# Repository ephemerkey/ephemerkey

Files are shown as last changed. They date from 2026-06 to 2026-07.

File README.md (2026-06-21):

# ephemerkey

A battery-powered, **GPS-geofenced TOTP code generator**. It produces RFC 6238
time-based one-time passwords (TOTP) — but only when the device holds a valid
GNSS fix inside an authorized geofence. Outside the fence, no codes. A companion
analog "TOTP lock" board consumes the codes and drives an actuator.

> Time comes from GNSS (disciplined RTC), place comes from GNSS — so a code is
> proof of *being in the right place at the right time*.

## Features

- **GNSS time + place**: u-blox MAX-M10S provides UTC time (TIMEPULSE-disciplined
  RTC) and a position fix. Codes are gated on both an accurate clock and a fix
  inside the configured geofence.
- **RFC 6238 TOTP**: SHA1/HMAC/Base32 engine from the `smalltotp` library,
  6-digit / 30-second codes (configurable).
- **Ultra-low-power**: STM32U083 (Cortex-M0+ ULP) + TPS63900 buck-boost with
  nanoamp-class quiescent current for long battery life; GNSS duty-cycled.
- **Tamper / motion**: LIS3DH accelerometer for wake-on-motion and tamper
  detection (optionally zeroizes the secret on tamper).
- **Single coin/Li-ion cell** input via buck-boost (works above and below 3.3 V).

## Architecture

```
                    ┌───────────────── RF ─────────────────┐
   W3011A chip ANT ─┤  (50Ω + π-match)                      │
                    └──────────────┬───────────────────────┘
                                   │ RF_IN
                          ┌────────┴─────────┐
                          │  MAX-M10S-00B    │  u-blox M10 GNSS
                          │  (TCXO, LNA, SAW)│
                          └─┬───┬────┬───┬───┘
                   UART(TXD/RXD)│    │TIMEPULSE (1 PPS → RTC discipline)
                            │   │EXTINT (wake)
                            │   │
   batt ── TPS63900 ──3V3───┼───┴──────────────┐
   (buck-boost,             │                  │
    ultra-low Iq)           │ USART1           │ V_BCKP (RTC/GNSS backup)
                     ┌───────┴────────┐         │
                     │  STM32U083KCU6 │         │
                     │  Cortex-M0+    │── RTC ──┘ (TOTP time base)
                     │  256KB flash   │
                     └─┬────┬────┬────┘
                  I2C  │    │    │ SWD (PA13/PA14)
                  ┌────┴──┐ │    │
                  │LIS3DH │ │    └── USB (PA11/PA12) — provisioning/console
                  │ accel │ │
                  └───────┘ └── code out → companion "TOTP lock" board
                  (motion/tamper)   (UART / open-drain / display)
```

## Repository Structure

```
ephemerkey/
├── hardware/                    # PCB design (KiCad 10, CERN-OHL-P v2)
│   ├── lib/                     # empty — anchor parts use KiCad bundled libs
│   │   ├── symbols/             #   (reserved for future custom symbols)
│   │   ├── footprints.pretty/   #   (reserved for future custom footprints)
│   │   └── 3dmodels/            #   (reserved for future 3D STEP models)
│   ├── ephemerkey/              # The generator board
│   │   ├── ephemerkey.kicad_pro
│   │   ├── ephemerkey.kicad_sch # Top-level: MCU, USB, SWD, button, LED
│   │   ├── psu.kicad_sch        # Battery → TPS63900 buck-boost sub-sheet
│   │   ├── gnss.kicad_sch       # MAX-M10S + W3011A antenna sub-sheet
│   │   └── sensors.kicad_sch    # LIS3DH accelerometer sub-sheet
│   ├── scripts/
│   ├── Makefile
│   ├── sym-lib-table
│   └── fp-lib-table
├── firmware/
│   ├── ephemerkey-stm32/        # STM32U083 application (STM32CubeU0 HAL)
│   ├── common/                  # Shared HAL/utilities
│   ├── shared/                  # Shared protocol definitions
│   └── LICENSE                  # Apache 2.0
├── reference/                   # Datasheets, source-skeleton pointers
├── DESIGN.md                    # Full hardware/firmware design document
└── LICENSE
```

## Key Components

| Component | Part | Package | Purpose |
|---|---|---|---|
| MCU | STM32U083KCU6 | UFQFPN-32 | ULP Cortex-M0+, 256KB flash, RTC, USB, TOTP engine |
| GNSS | MAX-M10S-00B | LGA (9.7×10mm) | u-blox M10: UTC time + position fix |
| GPS antenna | W3011A | SMD chip | 1.559–1.606 GHz GNSS antenna |
| Power | TPS63900DSKR | VSON-10 | Buck-boost, nanoamp Iq, single-cell → 3V3 |
| Accelerometer | LIS3DHTR | LGA-16 | Motion wake + tamper detection |

## Companion Project

The **TOTP lock** (separate analog board) reads the code stream from this
generator and drives an actuator (solenoid/relay). ephemerkey is the *generator*
half; the lock is the *consumer* half. The interface is documented in
`DESIGN.md` (§ Code Output Interface).

## License

- **Hardware**: CERN-OHL-P v2 (permissive open hardware)
- **Firmware**: Apache 2.0 (TOTP engine via smalltotp, also Apache 2.0)

Copyright (c) 2025-2026 EphemerKey Authors

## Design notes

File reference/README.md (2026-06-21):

# Reference Material

Pointers to source material this project was built from.

## Source skeleton
- **Altium part-selection skeleton:** `elec/pr/totp/totp_gps_gen/` — the
  original schematic with the five anchor parts. Pin names/numbers for the
  KiCad symbols were extracted from `totp_gps_gen.SchDoc`.
- **Repo skeleton modeled after:** `github/reefvolt-sensorbuddy/` (KiCad 10
  layout, Makefile, lib-tables, JLCPCB script, DESIGN.md style).

## Firmware
- **smalltotp:** `github/smalltotp/` — RFC 6238 TOTP engine (SHA1, HMAC-SHA1,
  Base32) with STM32 RTC time helpers. Linked/vendored by the firmware.

## Datasheets (to download into this folder via the datasheets skill)
| Part | MPN | Notes |
|---|-----|---|
| MCU | STM32U083KCU6 | AF map for UFQFPN-32, RTC/USB/LPUART, RDP |
| GNSS | MAX-M10S-00B | u-blox M10 integration manual (UART, PPS, V_BCKP, RF) |
| Antenna | W3011A | π-match topology, ground keep-out |
| Power | TPS63900DSKR | CFG/SEL strapping, inductor + cap selection |
| Accel | LIS3DHTR | I2C addressing, INT1/INT2 config |

> Use the `digikey`/`datasheets` skills to populate this folder, then the
> `kicad`/`emc`/`spice` analyzers can consume verified specs.

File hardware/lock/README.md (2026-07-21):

# lock — companion TOTP lock board

The **consumer** half of the ephemerkey system, and the **second PCB in this
repo** (alongside `hardware/ephemerkey/`, sharing the same `scripts/kschgen.py`
engine, `Makefile`, and lib tables — the multi-project layout used by
`reefvolt-sensorbuddy`). ephemerkey *generates* an authenticated unlock; this
board *verifies* it and drives the actuator.

```
make gen-lock      # regenerate the schematic from scripts/lock.schgen.py (placed, not wired)
make check-lock    # component/footprint/dup-ref/ERC tally
make render-lock   # per-sheet PNGs
```

The schematic is **generated from a manifest** (`scripts/lock.schgen.py`), like
ephemerkey. Components are **placed, not wired** — each sheet carries an
on-canvas note that is the wiring spec for the eeschema phase. Regenerate
*before* wiring (regen reassigns UUIDs).

## What it does

1. Sleeps at ~0.1 µA (ATtiny1616 power-down). Coil de-energized, 12 V rail off.
2. ephemerkey starts an I2C transaction; the first START wakes the MCU (wake-on-I2C).
3. **Authenticated** challenge-response over I2C proves the request is
   genuine (HMAC-SHA1, shared secret in flash — see *Firmware plan*).
4. On success: enable the boost, run the **peak-and-hold** solenoid profile,
   then drop the rail and go back to sleep.

Everything (MCU + boost + driver) is **powered from ephemerkey over the I2C
connector** (J2.2 = VSYS, ephemerkey's ~3.0–4.7 V battery/system rail). The lock
carries **no local battery** (J1 removed). See the *current caveat* under the
interface section — a 12 V solenoid pull-in draws several amps through that cable.

## Architecture

```
 VSYS from ephemerkey ──┬─────────────────────────────► U1 ATtiny1616 VCC   (direct, NO LDO; ~0.1µA sleep)
   (J2.2, I2C connector) │                            │  PA5 SOL_PWM ─┐   PB0/PB1 I2C ── J2 (target; key=master)
                           │                            │  PA6 SOL_BOOST_EN  wake-on-I2C: SCL START (no wake line)
                           │   SOL_BOOST_EN ──► EN       │  PA0 UPDI ─────── J4 (program)
                           └─► U2 MT3608 boost ──► +12V (VSOL) ─┬─ C5 220µF + C6 22µF  (reservoir)
                               L1 10µH · D2 SS34               │
                               FB: R3 200k / R4 10k ≈ 12.6V    ▼
                                                          ┌─ SOLENOID ─┐  (J3 JST-PH)
                                                  D3 SS34 │            │
                                                  flyback └─────┬──────┘
                                                                │ SOL_DRV (drain)
                                                  SOL_PWM ─[R5 100R]─┤ Q1 AO3400A (low-side)
                                                              [R6 100k]│
                                                                    GND┘
```

Sheets: **MCU** (`mcu.kicad_sch`) · **PWR** (`psu.kicad_sch`) · **DRV** (`drv.kicad_sch`).

## BOM (all JLCPCB / LCSC)

| Ref | Part | Value | LCSC | JLC | Footprint |
|-----|---|---|---|-----|---|
| U1 | ATtiny1616 | tinyAVR-1, runs 1.8–5.5 V | C507118 | ext | QFN-20 3×3 0.4 mm |
| U2 | MT3608 | boost, ~2 A switch | C84817 | ext | SOT-23-6 |
| Q1,Q2,Q4,Q5 | AO3400A | N-FET (solenoid LS, FB switch, servo logic, interlock) | C20917 | **Basic** | SOT-23 |
| Q3 | AO3401A | P-FET (servo high-side load switch) | C15127 | **Basic** | SOT-23 |
| D2,D3 | SS34 | Schottky 40 V/3 A | C8678 | **Basic** | SMA |
| L1 | FNR6045S100MT | 10 µH power inductor | C168076 | ext | 6×6 mm |
| C5,C8 | 220 µF 25 V | reservoir / VSERVO bulk (electrolytic) | C4747974 | ext | Ø6.3×7.7 |
| C4,C6 | 22 µF 25 V | boost out / VSOL bypass | C12891 | **Basic** | 1206 |
| C3 | 10 µF 25 V | boost in | C15850 | **Basic** | 0805 |
| C1,C2,C7,C9,C10 | 100 nF / 1 µF / 1 nF | decouple / hall debounce / snubber(DNP) | C1525/C29266 | **Basic** | 0402 |
| R3 | 200 k | FB top | C25764 | **Basic** | 0402 |
| R4 | 22 k | FB base → 6 V default | C25768 | **Basic** | 0402 |
| R17 | 20 k | FB switch → 12 V (Q2) | C25765 | **Basic** | 0402 |
| R2,R6,R18,R19,R20 | 100 k | pulldowns / P-FET gate pull-up | C25741 | **Basic** | 0402 |
| R16,R21,R22,R23,R25 | 10 k | servo pulldowns/series, hall pull-ups | C25744 | **Basic** | 0402 |
| R5 | 100 Ω | gate series | C106232 | ext* | 0402 |
| R1,R15,R24 | 1 k | status LED / servo signal series | C11702 | **Basic** | 0402 |
| D1 | LED green | status (driven by **PC3**) | C160479 | ext | 0402 |
| J3 | JST-PH 2-pin | solenoid | C173752 | ext | PH 2.0 |
| J2 | JST-PH 4-pin RA (S4B-PH-K) | I2C link (right-angle) | C157926 | ext | PH 2.0 RA |
| J4 | pin header 1×3 | UPDI program | — | — | 1×3 |
| J5,J8 | pin header 1×3 | servo outputs (S/V+/GND), DNP unless servo build | — | — | 1×3 |
| R13,R14 | 0 Ω | VSERVO source select (fit one) | C17168 | **Basic** | 0402 |
| J6,J7 | JST-PH 3-pin RA (S3B-PH-K) | door / bolt hall sensors | C157929 | ext | PH 2.0 RA |

\* jlcsearch under-reports Basic flags; verify in JLCPCB's BOM tool at order time.

Every footprint is a KiCad-bundled package, so **all parts carry 3D models** — the
board is clearance-checkable in KiCad's 3D viewer once it's laid out.

## Boost + reservoir sizing (read before ordering)

12 V × up to 1 A ≈ **12 W ≈ ~3.8 A from the cell** — heavy. The design splits it:

- The **MT3608** is sized for the **hold** current (~0.3 A @ 12 V ≈ within its
  ~0.5 A @ 12 V capability) plus recharging the reservoir between actuations.
- The **reservoir** (C5) supplies the brief **pull-in** surge. Sizing:
  `ΔV ≈ I_pull · t_pull / C`. A 1 A, 30 ms pull-in pulls 30 mC; with 220 µF that
  sags the rail a lot, so **220 µF is the baseline for ≤ ~500 mA / short
  pull-ins**. For a true sustained **1 A @ 12 V pull-in**, either grow C5 into
  the multi-thousand-µF range **or** swap the MT3608 for a **TPS61088-class**
  boost that can source the full 12 W directly. Pin this down against the actual
  solenoid's pull-in current × time and re-fire rate.

Set Vout exactly with the FB divider: `Vout = 0.6·(1 + R3/R4)`. 200 k/10 k ≈
12.6 V; trim R3 toward 12.0 V if desired.

## Servo variant + firmware actuator control

The board drives a **12 V solenoid** or a **6 V RC servo**. Because the boost
voltage and the servo power are both firmware-controlled, **one fully-populated board
can carry both** and switch between them (one actuator active at a time — a single
boost = a single voltage). Firmware drives three lines:

- **`BOOST_VSEL`** (PA1) — picks the rail: low/default **6 V** (servo-safe), high
  **12 V** (solenoid). NMOS Q2 switches R17 across the FB divider.
- **`SERVO_PWR_EN`** (PA2) — high-side P-FET (Q3) load switch on VSERVO. Servo power
  comes on only when firmware asserts it **and** the boost is at 6 V: a **hardware
  interlock** (Q5, gated by `BOOST_VSEL`) forces servo power OFF at 12 V regardless of
  firmware, so a 12 V solenoid pulse can never reach a 6 V servo.
- **`SERVO_SIG`** (PB2 / TCA0) — 50 Hz position pulse, via R15 (1 k) + R16 (10 k idle
  pulldown) so the servo can't twitch at boot.

| Mode | BOOST_VSEL | SERVO_PWR_EN | Actuator |
|---|---|---|---|
| Solenoid | 12 V | off (interlock-forced) | Q1/D3/J3 peak-and-hold |
| Servo, 6 V | 6 V | on | J5 servo, VSERVO ← VSOL (`R13`, populated) |
| Servo, direct | boost off | on | J5 servo, VSERVO ← VSYS (`R14`, DNP alt) |

- **J5 / J8** — two 3-pin RC-servo outputs (`1=SIG, 2=V+ (VSERVO), 3=GND`), e.g. a
  dual-latch lock. `SERVO_SIG` (PB2/TCA0) and `SERVO_SIG2` (PB4, software-timed);
  both share the `VSERVO` rail and the load-switch/interlock. MT3608 ~1 A @ 6 V —
  drive them sequentially, or upsize C5/C8 for simultaneous travel.
- **VSERVO source** — fit **exactly one** 0 Ω: `R13 = VSOL` (6 V from the boost —
  the populated default) or `R14 = VSYS` (servo direct off the connector rail,
  ~3–4.7 V). **Never both.** C8 (220 µF) buffers servo inrush.
- `SERVO_SIG` is VSYS-level logic (~3–4.7 V), accepted by typical servos, GND-referenced.

## Authenticated digital interface + Firmware plan

The ephemerkey↔lock link is an authenticated I2C bus — **ephemerkey is the
master**, this lock is the target — on a **right-angle 4-pin JST-PH** (`S4B-PH-K`,
a standard 4-pin I2C cable, straight-through):

| Pin | lock (this board, target) | ephemerkey (key, master) |
|-----|---|---|
| 1 | GND (+ actuation return) | GND |
| 2 | **VCC ← powers the lock** (VSYS in) | **VSYS** (battery/system rail out) |
| 3 | `SDA` ↔ PB1 | `LOCK_SDA` (PA6, I2C3) |
| 4 | `SCL` → PB0 (clock + wake) | `LOCK_SCL` (PA7, I2C3) |

The lock has **no local battery** — its VCC (and the boost/actuator draw) comes in
on J2.2 from ephemerkey's VSYS rail. **Current caveat:** a 12 V solenoid pull-in is
~3–4 A from VSYS, beyond a JST-PH contact (~2 A) and ephemerkey's load-share path —
favor the 6 V servo / low-duty buffered by C5/C8, or run a heavier dedicated feed.
The I2C pull-ups live on ephemerkey at +3V3 (do not pull the bus to VSYS — the STM32
pins are 3.3 V-domain). The lock (running at VSYS) reads the 3.3 V idle
level fine across the discharge curve. The lock is the **target** at addr 0x60 with
**no separate wake line** — it wakes from power-down on the first I2C START (a
pin-change interrupt on SCL), so we don't mix a discrete "button"-style input with
the bus.

Authentication is **firmware HMAC** — no secure element. A pairing secret lives
in flash on **both** boards (separate from ephemerkey's TOTP secret).

**I2C register/command map** (lock = target @ 0x60). The master reads status/nonce
and writes *authenticated* commands:

| Reg | Access | Contents |
|-----|---|---|
| `0x00 STATUS` | read | bit0 `DOOR_CLOSED` · bit1 `BOLT_LOCKED` · bit2 `ACTUATOR` (0=solenoid,1=servo) · bit3 `RAIL_12V` · bit4 `BUSY` · bit5 `LAST_CMD_OK` |
| `0x01 NONCE` | read | a fresh 16-byte random nonce; reading **arms** it (consumed by the next COMMAND) |
| `0x10 COMMAND` | write | `[cmd] ‖ HMAC-SHA1(secret, nonce ‖ cmd ‖ code)` — cmd `0x01`=UNLOCK, `0x02`=LOCK |

**Probe lid/door state (unauthenticated read — status only):** the I2C START wakes
the lock; the master reads `STATUS`. `DOOR_CLOSED` / `BOLT_LOCKED` report the J6/J7
hall sensors; `ACTUATOR` tells the key whether a servo is fitted.

**Lock / unlock (authenticated challenge-response, anti-replay):**

1. Master reads `NONCE` (0x01).
2. Master writes `COMMAND` = `cmd ‖ HMAC-SHA1(secret, nonce ‖ cmd ‖ code)`.
3. Lock recomputes, **constant-time** compares against the armed nonce (then clears
   it → replay-proof), and only then drives the actuator:
   - **UNLOCK** (0x01): solenoid → peak-and-hold release; servo → unlock angle.
   - **LOCK** (0x02): **servo → lock angle** (a servo holds position). For a
     momentary solenoid, LOCK is a no-op — it re-latches mechanically (fail-secure).
4. Master may re-read `STATUS` to confirm `BOLT_LOCKED` flipped.

`code` may be the ephemerkey TOTP digits, binding the action to a fresh in-fence
code. Optionally fold a monotonic counter (EEPROM) into the HMAC so a weak RNG
can't be exploited.

**Lock firmware (ATtiny1616 — megaTinyCore or bare AVR):**

- State machine: `SLEEP(power-down)` → (I2C START wakes it) → service TWI as target
  → `SLEEP`; a verified `COMMAND` branches to `ACTUATE`. In `SLEEP`: TWI/boost off,
  `R6` holds Q1 off, `R2` holds boost off; SCL (PB0) pin-change wakes it (wake-on-I2C).
- **STATUS read** → pulse `HALL_PWR` (PA4) high, settle ~1 ms, sample `HALL_DOOR`
  (PA7) + `HALL_BOLT` (PB3), drop HALL_PWR, return the bits (~0 µA between reads).
- **ACTUATE**:
  - *Solenoid* — the **peak-and-hold economizer**: `SOL_BOOST_EN=1` → wait VSOL →
    `SOL_PWM` 100 % pull-in (~20–50 ms) → reduce duty for hold → release. PWM = TCB0 (PA5).
  - *Servo* — `BOOST_VSEL`=6 V, `SERVO_PWR_EN`=on, drive `SERVO_SIG` (PB2/TCA0) to
    the lock/unlock angle, wait for travel, then cut servo power. The hardware
    interlock keeps servo power off whenever `BOOST_VSEL`=12 V.
- HMAC-SHA1 (reuse `smalltotp`, portable C → compiles for AVR) fits in 16 KB/2 KB.
  Secret in USERROW/flash; **disable UPDI / set lockbits** in production.

**Key firmware (ephemerkey STM32U083 — add to its superloop):**

- **Probe the lid:** wake the lock (I2C START) and read `STATUS` — surface door
  open/closed + bolt locked/unlocked (e.g. on the OLED); no auth needed.
- **Lock / unlock:** on a request (button + in-fence + fresh, valid TOTP), read
  `NONCE`, compute `HMAC-SHA1(secret, nonce ‖ cmd ‖ code)`, write `COMMAND` with cmd
  = UNLOCK or LOCK. (Send a dummy/wake byte first and retry — the just-woken target
  NACKs the first.) Re-read `STATUS` to confirm.
- Use the **same** HMAC-SHA1 as the lock — `smalltotp` ships it, so both reuse it.
- The pairing secret is provisioned over USB during pairing.

## Programming

`J4` UPDI header: `1 = UPDI (PA0)`, `2 = VCC (BAT)`, `3 = GND`. One-wire UPDI via
`pymcuprog`, a serial-UPDI adapter, megaTinyCore, or Atmel-ICE/PICkit.

## Bring-up checklist

1. Power from a current-limited 1S cell; confirm the MCU enumerates over UPDI and
   sleeps at ~µA with the I2C bus idle.
2. Pulse `SOL_BOOST_EN`; scope VSOL → should reach ~12.6 V; trim R3 if needed.
3. With a solenoid fitted, tune the pull-in time and hold duty; add the R9/C7
   snubber (DNP) only if drain ringing is high.
4. Bring up the I2C challenge-response against ephemerkey (confirm wake-on-I2C +
   the dummy-then-retry handshake); verify a wrong/late response never actuates.

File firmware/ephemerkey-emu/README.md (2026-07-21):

# ekemu — generator + lock emulator

Runs the **exact `ephemerkey-core` engines the firmware ships** — policy
state machines, TOTP validation with walk-time delay windows, the reveal
scheduler with scatter/show-once/decoy display modes — under a virtual
clock, with the display and key-entry surfaces mimicked in text. A
30-minute walk takes one `time +30m`.

```sh
make demo          # self-checking walk-vault ritual (CI-able)
make run           # interactive REPL
make test          # core unit tests (RFC 4226/6238 vectors, etc.)
```

## Commands

```
time +<n>[s|m|h]      advance the virtual clock (ticks slot expiry)
time set <unix>       jump the clock
env fence <i> <in|out>  move the lock in/out of geofence i (portable locks)
env still <secs>      set how long the lock has been motionless
env cal <i> <open|shut> open/close calendar window i
env show              print the current virtual GNSS/accel/RTC environment
gen reveal [key]      request a reveal — prints the display frames the user
                      (and any shoulder-surfer) would see; scatter mode shows
                      one digit per frame, correct position, random order
gen next [key]        countdown to the next REAL reveal (show-once modes)
lock enter <code|@N>  type a code; @N = Nth revealed code (the "notebook"
                      the user wrote codes into before walking)
lock status           slot states (respects show_progress hiding)
validate <@R>         relay the Rth emitted receipt to the remote validator
expect <substring>    assert on the last event line; any miss => exit 1
echo / # / quit
```

## Confirm-TOTP (the lock talks back)

If a scenario has a `confirm` block (`{ "secret", "digits", "mode":
sequence|time|both }`), the lock mints its own **receipt** on every fire and
relock — a `RECEIPT @R` line carrying a **sequence** code (HOTP over a
monotonic event counter: order/replay proof), a **time** code (TOTP over the
event time: "it happened at HH:MM"), or both. `validate @R` relays a receipt
to a remote validator holding the same secret, which reports `VALID
(skipped/drift)`, `REPLAY`, `OUTOFWINDOW`, `DESYNC`, or `BADCODE`. Time proves
*when*; sequence proves *which event, in order* — a lock can require either or
both.

Each slot may carry **gates** (`{ "fence": i, "stillness_s": n, "calendar":
i }`) that must all hold — evaluated against the `env` above — before a code
counts. A correct code entered while a gate is shut reports `GATED slot=…
<reason>` and is **not burned**, so the same code works once the lock is in
position / still / in-window. Gates are checked in a fixed order (fence →
stillness → calendar) so the reported reason is deterministic.

The `DECOY` tag on reveal events is ground truth from the core's
`introspect` feature (emulator-only — firmware builds cannot see it; the
display pipeline is identical for real and poison codes by construction).

## Scenario files

JSON (`scenarios/*.json`): a key table (secret, digits 4-10, optional decoy
twin, display spec) and a slot table (policy + parameters). Policies:
`always`, `sequence` (N codes, generation cadence, walk delay), `path`
(ordered zone-keyed legs), `deadman` (beat or RELOCK), `quorum` (M-of-N
distinct keys, optional alternating).

| Scenario | Script demonstrates |
|---|---|
| `walk-vault` | the canonical ritual: 3 codes on 90-240 s minting cadence, valid 30-35 min later; scatter display; poison-mode decoy → lockout |
| `courier` | walk-the-path: zone A→B→C legs, order + pace proven by counters, entered from the notebook at the destination |
| `deadman` | unlock, keep-alive beats, missed-beat RELOCK, and the forced-reset-still-relocks invariant |
| `quorum` | two-person rule: alternating violation, completion, window expiry |
| `portable-vault` | position + stillness + calendar gates peel off one at a time; the never-burned code fires only when all three hold, then re-gates on leaving the fence |
| `receipts` | confirm-TOTP in `both` mode: fires and relocks mint sequence+time receipts; a validator catches replay, resync-skip, and time-window expiry |

## What the demo script proves

`scripts/walk-vault.txt` walks the full story: cadence minting → squeezed
4th reveal is a decoy → early entry rejected → 31-min walk → 3 codes
accepted on generation cadence → replays ignored without reset → unlock
fires → post-fire replay burned → the decoy arrives later and trips a
lockout. Every step is `expect`-checked.

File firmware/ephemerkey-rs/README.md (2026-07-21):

# ephemerkey-rs — STM32U083 firmware (Rust / Embassy)

Async-Rust replacement for the C `ephemerkey-stm32/` skeleton, built on
[Embassy](https://embassy.dev). Chip: **STM32U083KCU6** (Cortex-M0+,
UFQFPN-32, `thumbv6m-none-eabi`), officially supported by `embassy-stm32`
(feature `stm32u083kc`). No STM32Cube dependency.

## Personalities

One image, two roles, selected by provisioned config (`src/config.rs`):

| Role | Pipeline |
|---|---|
| **Generator** | GNSS (USART1) → geofence → RTC-disciplined TOTP emission |
| **LockController** | code slots / policy engine (`src/policy.rs`) → authenticated I2C link to the lock board |

Both are programmed with signed config **files** over USB (button-gated
provisioning mode) or the WiFi/ESP32-C3 link — see `src/provision.rs` and
`../../DESIGN-policies.md` for the slot/policy model.

## Layout

| File | Subsystem |
|---|---|
| `src/main.rs` | boot, role dispatch, LEDs (PB0/PB1), buttons (PA5/PA15), PPS placeholder (PA0) |
| `src/gnss.rs` | MAX-M10S on USART1 (PA9/PA10, DMA RX) + RESET_N (PA4, OD) + EXTINT (PA1) |
| `src/lock.rs` | hardware I2C3 master to the lock board (PA6 SDA / PA7 SCL) — see below |
| `src/sensors.rs` | I2C1 (PB6/PB7): LIS3DH @0x18, OLED @0x3C, M24M02E log EEPROM @0x50-53, MAX17048 fuel gauge @0x36; INT1/INT2 EXTI |
| `src/wifi.rs` | ESP32-C3 on LPUART1 (PA2/PA3) + PB5 power gate (off by default) |
| `src/buzzer.rs` | TIM3_CH1 PWM on PB4 (boot chirp) |
| `src/config.rs` | role + persistent config (flash journal TODO) |
| `src/provision.rs` | signed config file ingestion (USB/WiFi transports TODO) |
| `../ephemerkey-core` | **shared no_std core**: TOTP (4-10 digits, delay windows), code-slot policy engine, reveal scheduler (scatter/show-once/decoy) — unit-tested on host, exercised by `../ephemerkey-emu` |

Every pin binding is type-checked against the U083 AF table at compile time —
the crate builds only if the DESIGN.md pin budget is electrically coherent.

### Hardware finding → rev 0.2 pin swap

The original pin budget put the lock link on PB0/PB1, which carry **no I2C
alternate function** on the U083 (only LCD/LPTIM3/SPI1-CS/UART-flow) — caught
by this crate's compile-time AF check. Resolution: the lock link and the LEDs
swapped pins. The link now rides **hardware I2C3 on PA6 (SDA) / PA7 (SCL),
AF4**; the LEDs (function-agnostic) took PB0/PB1. Schematic + DESIGN.md are
updated to match.

The bus-transient requirement survives the swap: the lock glitches SDA/SCL
for ~0.4 s during actuation (see `../lock-attiny/README.md`), so the master
re-inits the peripheral + bus-clears + retries on any error.

### Timer allocation

| Timer | Use |
|---|-----|
| TIM15 | embassy time driver (do not touch) |
| TIM2 | reserved: GNSS PPS input capture (PA0, CH1) |
| TIM3 | buzzer PWM (CH1, PB4) |
| LPTIM1 | future: time driver in Stop mode (LSE), with the `low-power` work |

## Build / flash

```sh
make build          # debug
make release
make run            # probe-rs flash + defmt console (SWD on PA13/PA14)
make flash          # release flash
```

Requires `rustup` (pulls the pinned toolchain + target via
`rust-toolchain.toml`) and `probe-rs` (`--chip STM32U083KC`).

## Roadmap

- [ ] Clock tree: LSE→RTC, HSI48+CRS→USB; then Stop-mode + `low-power` executor
- [x] TOTP core: RustCrypto `hmac`/`sha1` in `ephemerkey-core` (RFC-vector tested)
- [ ] NMEA parse + geofence (port `geofence.c` point-in-polygon)
- [ ] TIM2_CH1 PPS capture → RTC discipline + staleness window
- [ ] Flash journal (`sequential-storage`): config/secret map (2×2KB
      ping-pong, rare writes) + confirm-TOTP counter queue (2×2KB append,
      ECC-safe single-write-per-word) + RDP/HDP — see `src/config.rs`
- [ ] USB FS provisioning console (`embassy-usb`, button-gated)
- [ ] Lock link: nonce/HMAC command flow over I2C3 (+ soak
      against the real lock through actuation transients)
- [x] Path / DeadMan / Quorum state machines (ephemerkey-core, emulator-proven)
- [x] Policy-engine gate model: `Sensors` trait + fence/stillness/calendar
      gates in `ephemerkey-core` (emulator-proven); firmware still needs the
      real `Sensors` impl over GNSS-fix / LIS3DH-activity / RTC
- [x] Confirm-TOTP receipts in `ephemerkey-core`: HOTP (event-sequence) and
      TOTP (event-time) proofs, independently selectable or both, minted on
      every fire/relock, with a remote `Validator` (emulator-proven). Firmware
      still needs to persist the monotonic event counter (flash journal) and
      wire the relay to OLED/USB/WiFi.
- [ ] ESP32-C3 protocol: OTA staging, config file transport

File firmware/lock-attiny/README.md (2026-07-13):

# ephemerkey lock board — ATtiny1616 firmware

Firmware for the companion "TOTP lock" board. The ATtiny1616 runs directly
off the cell (1.8–5.5 V, no LDO), authenticates codes over I²C via HMAC-SHA1
(shared with `smalltotp`), and drives the actuator with a peak-and-hold
economizer.

This tree implements the **authenticated I²C lock**: an HMAC-SHA1 challenge-
response that gates unlock/lock actuation, plus unauthenticated hall-sensor
status — running from power-down sleep, woken by the I²C bus.

## Hardware map (from `hardware/lock/`)

| Signal | Pin  | Notes |
|---|---|---|
| Status LED | PC3  | active-high: `PC3 → D1 → R1(1k) → GND` |
| UPDI / RESET  | PA0  | `SYSCFG0=0xF6` — RESET pin is UPDI |
| I²C SCL | PB0  | TWI0 (target @ 0x60); START wakes from power-down |
| I²C SDA | PB1  | TWI0 |
| HALL_PWR | PA4  | powers both hall sensors during a read only  |
| HALL_DOOR | PA7  | door sensor in (J6.3) |
| HALL_BOLT | PB3  | bolt sensor in (J7.3) |
| Servo1 signal | PB2  | `TCA0/WO2 → R15(1k) → J5.1`, 50 Hz / 0.6–2.4 ms |
| Servo2 signal | PB4  | software pulse (TCA0 OVF+CMP1) → R24 → J8.1 |
| Servo power | PA2  | `SERVO_PWR_EN → Q3` high-side (VSERVO) |
| Solenoid drive| PA5  | `SOL_PWM → R5 → Q1` low-side; hold PWM = TCD0/WOB ~31 kHz |
| Boost enable  | PA6  | `SOL_BOOST_EN → MT3608 EN` (12 V for solenoid) |
| Boost 6/12 V  | PA1  | `BOOST_VSEL` select + servo interlock (Q5) |

Fuses read factory-default; device is unlocked. See the bringup notes in the
repo for the full fuse dump.

### Servo power — servo runs on VSOL (default strap R13)

The servo supply (`VSERVO_SRC`) is strap-selected on the DRV sheet:
**`R13`(0Ω, fitted) → VSOL** (the boost rail, the default) or **`R14`(DNP) →
BAT+** (direct battery, alt). So the servo is on VSOL: at ~Vbat when the boost
is off (VSOL's passive L1+D2 path), or **6 V when boosted** (`servo_boost`
config flag → `SOL_BOOST_EN` on, `BOOST_VSEL` low = Q5 interlock clear).
`BOOST_VSEL` high (12 V) always interlocks servo power off.

(NB: an on-canvas note in `drv.kicad_sch` labels R13/R14 the other way round —
it's stale; R13→VSOL per the `lock.schgen.py` manifest and the built board.)

## Toolchain

- **Compiler:** `avr-gcc` / `avr-libc` (Fedora: `sudo dnf install avr-gcc
  avr-libc avr-binutils`). Needs avr-libc ≥ 2.0 for tinyAVR-1 headers.
- **Programmer:** [`pymcuprog`](https://pypi.org/project/pymcuprog/) SerialUPDI
  over an Adafruit UPDI Friend. Invoked via `uvx` — no system install needed.
- Adapter enumerates as a CH340 at `/dev/ttyUSB0` (override with `PORT=`).

The HMAC-SHA1 core is the **`smalltotp`** sibling repo (`src/sha1.c`,
`src/hmac_sha1.c`), linked — not vendored — exactly as the STM32 side does.
Point `SMALLTOTP` at your checkout:

## Build & flash

```sh
make SMALLTOTP=~/path/to/smalltotp        # compile + link + size
make flash SMALLTOTP=~/path/to/smalltotp  # erase, write, verify
make ping                                 # UPDI sig check (1E9421)
make fuses                                # dump fuses
make clean
```

Default is `SMALLTOTP ?= ../../../smalltotp` (a sibling of the repo). Select the
actuator with `-DLOCK_ACTUATOR=ACTUATOR_SERVO` (default) or `ACTUATOR_SOLENOID`.

## I²C protocol (target @ 0x60 — see `hardware/lock/README.md`)

| Reg | Access | Contents |
|-----|---|---|
| `0x00 STATUS`  | read  | bit0 DOOR_CLOSED · bit1 BOLT_LOCKED · bit2 SERVO_ON (live) · bit3 RAIL_12V · bit4 BUSY · bit5 LAST_CMD_OK · bit6 SOL_ON (live: coil energized, incl. drain) |
| `0x01 NONCE` | read  | fresh 16-byte nonce; **reading arms it** (single-use) |
| `0x10 COMMAND` | write | `cmd(1) ‖ HMAC-SHA1(pairing_secret, nonce ‖ cmd)(20)`; `0x01`=UNLOCK, `0x02`=LOCK, `0x03`=ABORT (emergency stop: everything off) |
| `0x20 CONFIG`  | write | `blob(65) ‖ HMAC-SHA1(config_secret, nonce ‖ blob)(20)` · read = current blob |

Flow: read `NONCE` → write `COMMAND`/`CONFIG` → lock recomputes the HMAC,
**constant-time** compares, **burns the nonce** (replay-proof), then actuates or
saves config. Master re-reads `STATUS`. HMAC covers `nonce ‖ payload` only (no
TOTP code — the lock has no clock). UNLOCK/LOCK are **idempotent** (re-lock /
re-unlock is fine).

- **Two secrets, split across USERROW** (`SECRET_LEN`=16 each): pairing
  `[0:16]` (UNLOCK/LOCK) and config `[16:32]` (admin CONFIG writes). DEV
  fallbacks when USERROW is blank; provision over UPDI + set lockbits.
- **Anti-replay:** the armed nonce is single-use *and* derived from a monotonic
  EEPROM counter (survives resets/power loss; no TRNG):
  `nonce = HMAC-SHA1(pairing_secret, counter)[0:16]`. The counter provides
  freshness; keying with the pairing secret makes nonces opaque (an unkeyed
  hash would let one captured nonce brute-force the 2³² counter offline and
  predict all future nonces — no forgery, but a usage-count leak).
  Regenerating takes ~tens of ms (software HMAC at 3.3 MHz), so back-to-back
  NONCE reads can briefly serve the same value. Harmless: one armed slot,
  burned on first use, and regeneration is ordered before command servicing —
  a MAC verifies at most once (replay of the exact bytes is rejected; verified
  live).

### Programmable config (bit-packed, 65 bytes, persisted in EEPROM)

Actuation is a **programmable step sequence**: an ordered list of up to 6 steps
run on UNLOCK, and an independent list run on LOCK. Header + two sequences:

| Byte | Field | Encoding |
|---|---|---|
| 0 | magic (0xE4) | validity guard |
| 1 | flags | b0 servo_boost (servo-only steps at 6 V) |
| 2 | solenoid strike time | ×10 ms (full pull-in, 12 V economizer) |
| 3 | solenoid hold duty | 0–255 → 0–100 % (TCD0 economizer) |
| 4 | sensor_map | b0-1 DOOR_CLOSED src · b2-3 BOLT_LOCKED src (0=J6, 1=J7, 2=off) |
| 5–34  | `seq_unlock[6]` | 6 × step (5 bytes) |
| 35–64 | `seq_lock[6]` | 6 × step (5 bytes) |

Each **step** is 5 bytes — `act`, `s1_pos`, `s2_pos`, `dur_ds`, `eoff`:

| Field | Encoding |
|---|---|
| `act` | b0 servo1 · b1 servo2 · b2 solenoid · **0 = end of sequence** |
| `s1_pos` / `s2_pos` | 8-bit target → 500–2500 µs (per step, either direction) |
| `dur_ds` | run time ×100 ms (servo drive / solenoid hold), 0–25.5 s |
| `eoff` | b0-1 sensor (0 none · 1 DOOR · 2 BOLT) · b2 edge (0 present / 1 absent) |

A step fires any combination of its actuators **together**, for `dur_ds`, then
the sequence advances. If `eoff` names a (logical) hall sensor, the step can
end early — heavily deglitched, because actuation disturbs the sensors (on the
bench the hall reads a *sustained* false-absent whenever actuators are loaded):

1. **Arm** — the step must first see the *opposite* state for 5 consecutive
   10 ms samples (e.g. `eoff=door-` requires the door seen **closed** for
   50 ms within the step). A sensor that's disturbed from the start, broken,
   or disconnected never arms — the step simply runs its full time.
2. **Fire** — an integrating counter over 10 ms samples: wanted state +1,
   opposite −5 (floor 0); fires at 50 (~500 ms clean dwell). A few transients
   only delay it; sustained opposite readings drain it.

Both layers fail toward "keep driving". Then the sequence advances. Per-step
**rail selection** (the boost makes VSOL, which also feeds the servo):

| Step drives | Rail | Solenoid |
|---|---|---|
| solenoid **+** servo | **6 V** (`BOOST_VSEL` low, interlock clear) | **full DC**, no PWM |
| solenoid only | **12 V** (`BOOST_VSEL` high) | strike → economizer PWM hold; servo interlocked out |
| servo + `servo_boost` | **6 V** | — |
| servo only | Vbat (boost off) | — |

> **Combined servo+solenoid** is the only way to move a servo while the solenoid
> fires: forced to **6 V** with the solenoid at **full DC** (no economizer PWM),
> so the shared rail can power both. Normally the two are electrically exclusive
> (12 V solenoid interlocks servo power off).

> **`servo_boost` (flag b0) — 6 V boosted servo.** Servo-only steps run off the
> boost rail at **6 V** (`SOL_BOOST_EN` on, `BOOST_VSEL` **low** = Q5 interlock
> clear), with a boost ramp before and a VSOL drain after. Requires the servo
> strapped to VSOL (R13, the default strap) and a 6 V servo. **Off by default; do
> not set it unless the board is wired for a boosted servo.**

### Non-blocking actuation

Actuation runs as a **TCB0-tick-driven step engine** (`actuate.c`), never
blocking the main loop: it walks the configured UNLOCK/LOCK step list, ramping
each step's rail, driving its actuators for the step time (or until early-off),
then draining — all while I²C stays fully responsive, and a new lock/unlock
**aborts** the in-flight cycle. Per-step rail selection + VSOL drain are
preserved. The LED mirrors BUSY.

> **Verification status:** protocol verified **live on hardware** via the
> RedBoard I²C bridge (`testharness/`) — unlock/lock accept with a valid HMAC,
> reject a bad one, nonces are fresh per command, hall status reads; soaked 40
> lock/unlock pairs with aggressive mid-cycle polling. Sleep is
> **IDLE** for bringup (`LOCK_SLEEP_MODE`): a TWI target in continuous
> POWER-DOWN both NACK-wedges the bus and makes UPDI unreachable, so power-down
> is deferred until the wake path is hardened. Every reset opens an ~8 s awake
> window (LED flutter) for reliable reprogramming. STM32 master I²C+HMAC is
> still unimplemented (it talks one-way over UART today — a known spec gap).

> **⚠️ I²C during actuation:** the boost soft-starting into stalled servos
> glitches SDA/SCL for ~0.4 s at actuation start (bus-error bursts on every
> cycle on the bench; dev-board wiring exaggerates it, but assume nonzero on
> any build). The lock target rides it out fine — but **the master must
> implement bus-error recovery** (peripheral re-init / 9-clock bus-clear +
> retry) or it can latch and go permanently deaf, as the RedBoard's ATmega TWI
> did. Full write-up + soak/regression tool: `testharness/README.md`.

## Roadmap

- [x] Blink + sleep (LED + flash + wake path)
- [x] Dual servo actuation on battery voltage (TCA0 PWM, both connectors)
- [x] Gated 12 V solenoid, peak-and-hold, boost↔servo mutual exclusion + drain
- [x] I²C target + HMAC-SHA1 challenge-response (unlock/lock) + hall status
- [x] Power-down sleep, wake on I²C
- [ ] Live protocol test against the STM32 master (needs STM32 I²C+HMAC side)
- [ ] STM32 master I²C driver: bus-error recovery (re-init / 9-clock bus-clear
      + retry) — actuation glitches the bus every cycle; see testharness/README
- [ ] Confirm hall-sensor output polarity against the real part
- [ ] Provision USERROW secret + set UPDI lockbits
- [ ] Fuse config: enable BOD level for actuator brown-out margin

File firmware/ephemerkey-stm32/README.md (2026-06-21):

# ephemerkey-stm32

STM32U083 application firmware for the ephemerkey GPS-geofenced TOTP generator.
Built on the **STM32CubeU0 HAL** and the **smalltotp** RFC 6238 engine.

## What it does

Wake → power the GNSS → acquire a fix → parse NMEA → discipline the RTC from
GNSS UTC → gate on **fix quality** (sats, HDOP), **clock freshness**
(anti-replay), and **geofence** (haversine) → generate a TOTP code → emit it to
the companion lock (UART line + `CODE_VALID` strobe) → sleep until motion
(LIS3DH) or a duty timer. See `../../DESIGN.md` for the full design.

## Layout

```
ephemerkey-stm32/
├── Makefile                  # arm-none-eabi build (CUBE_U0 + smalltotp)
├── STM32U083KCUx_FLASH.ld    # linker script (256K flash / 40K RAM)
├── include/
│   ├── board.h               # pin map (mirrors DESIGN.md pin budget)
│   ├── ephemerkey_config.h   # secret, geofence, gating thresholds
│   ├── gnss.h                # NMEA RMC/GGA parser
│   ├── geofence.h            # haversine geofence test
│   ├── totp_app.h            # RTC <-> Unix bridge + emit
│   └── stm32u0xx_hal_conf.h  # HAL module config
└── src/
    ├── main.c                # superloop + peripheral init
    ├── gnss.c                # NMEA parser (host-testable)
    ├── geofence.c            # haversine (host-testable)
    ├── totp_app.c            # TOTP glue (RTC, smalltotp, lock output)
    ├── stm32u0xx_hal_msp.c   # AF pin / clock setup
    └── stm32u0xx_it.c        # ISRs (SysTick, EXTI2_3)
```

## Prerequisites

```bash
# ARM toolchain (already on this machine)
arm-none-eabi-gcc --version

# STM32CubeU0 (HAL + CMSIS + startup + system file)
git clone https://github.com/STMicroelectronics/STM32CubeU0 \
    ../vendor/STM32CubeU0        # -> firmware/vendor/STM32CubeU0 (gitignored)

# smalltotp is the sibling repo github/smalltotp (default path used by Makefile)
```

## Build

```bash
make                                   # uses CUBE_U0=../../vendor/STM32CubeU0
# or point at an existing checkout:
make CUBE_U0=/path/to/STM32CubeU0 SMALLTOTP=/path/to/smalltotp
make flash                             # st-flash to 0x08000000
make size
```

## TODOs before first silicon

- `SystemClock_Config()` — generate the LSE/MSI(/HSI48+CRS for USB) clock tree
  with CubeMX for STM32U083 and paste it into `main.c`.
- Verify AF numbers in `board.h` / `stm32u0xx_hal_msp.c` against the datasheet
  (USART2 TX on PB0, I2C1 on PB6/PB7, USART1 on PA9/PA10).
- I2C `Timing` value in `MX_I2C1_Init` — recompute for the chosen I2C clock.
- `enter_stop_until_event()` — implement Stop 2 entry + LIS3DH INT1 EXTI wake +
  RTC wakeup timer (currently a placeholder delay).
- `lis3dh_init()` — configure motion/tamper interrupts.
- USB CDC provisioning path (load secret + geofence into protected flash).

## Host-testable units

`gnss.c` and `geofence.c` depend only on libc/libm (no HAL) and can be compiled
and unit-tested natively:

```bash
cc -Iinclude -c src/gnss.c src/geofence.c   # sanity compile
```

## License

Apache 2.0 — see `../LICENSE`. smalltotp is also Apache 2.0.

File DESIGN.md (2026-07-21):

# ephemerkey Design Document

## Overview

ephemerkey is a battery-powered **GPS-geofenced TOTP generator**. It emits
RFC 6238 time-based one-time passwords, but only when the device holds a valid
GNSS fix *inside an authorized geofence*. The two inputs that gate a code are
therefore **time** and **place**, both sourced from the same u-blox GNSS module:

- **Time** — UTC from the GNSS, with the 1 PPS TIMEPULSE disciplining the
  STM32 RTC. The RTC is the TOTP time base (so codes are valid even between
  GNSS wake-ups).
- **Place** — a position fix that must lie within a configured lat/lon radius,
  with sufficient fix quality (min satellites, max HDOP).

A companion **TOTP lock** board (now in this repo at `hardware/lock/` — a second
PCB) consumes the emitted codes over an authenticated link and drives a solenoid.
ephemerkey is the *generator*; the lock is the *consumer*. See § Code Output
Interface.

This board was ported from an Altium part-selection skeleton
(`elec/pr/totp/totp_gps_gen`). The five anchor parts (MCU, GNSS, antenna,
power, accelerometer) come from that skeleton; the supporting circuitry and
firmware are designed here. Repository layout follows `reefvolt-sensorbuddy/`.

## Architecture Decisions

### MCU: STM32U083KCU6 (UFQFPN-32)

- **Ultra-low-power** Cortex-M0+ (STM32U0 family) — the right fit for a
  coin/Li-ion-cell device that spends most of its life in Stop mode waiting on
  motion or a duty-cycle timer.
- 256KB flash / 40KB RAM — ample for the HAL, NMEA parser, TOTP engine, and
  geofence tables, with room for readout protection (RDP) of the secret.
- **RTC with LSE** (32.768kHz crystal on PC14/PC15) is the TOTP time base.
  Disciplined by GNSS 1 PPS so it stays accurate while the GNSS is powered down.
- **USB FS device** (PA11/PA12) for provisioning/console (load the TOTP secret
  and geofence over USB; crystal-less USB clock recovery available on U0).
- AES hardware + TRNG on U0 — useful for at-rest secret protection / future
  challenge-response.
- Same family/footprint discipline as the reefvolt STM32 boards (UFQFPN custom
  footprint), so PCB practices carry over.

### GNSS: MAX-M10S-00B

- u-blox M10 module: integrated TCXO, LNA, and SAW filter — designed to work
  with a **passive** chip antenna, which is exactly the W3011A here.
- Concurrent GNSS, very low tracking power (~25mW), good for a duty-cycled,
  battery device.
- **UART (NMEA)** is the primary interface (TXD/RXD → STM32 USART1). The module
  also exposes DDC (I2C) and SPI; we use UART and leave I2C for the accelerometer.
- **TIMEPULSE** (1 PPS) → STM32 timer input capture for RTC discipline.
- **EXTINT** driven by the MCU for software wake / time-mark.
- **V_BCKP** kept alive from the always-on 3V3 tap so hot-starts are fast
  (RTC + last ephemeris retained between GNSS power cycles).
- Default UART baud 9600, UBX + NMEA. Configured at boot via UBX-CFG-VALSET
  (set message rates, power mode, dynamic model).

### GPS Antenna: W3011A

- SMD chip antenna, 1.559–1.606 GHz (covers GPS L1 / Galileo E1 / GLONASS G1).
- **Matching (datasheet-verified):** the W3011A datasheet labels the match a
  single *optional shunt*, but its rated performance (−16 dB return loss, 85%
  efficiency) is measured **with a shunt 1.8 pF** at the antenna feed. So the
  π-placeholder is populated **series 0 Ω (Rm1) + antenna-side shunt Cm2 = 1.8 pF**
  (datasheet reference value), RF_IN-side shunt Cm3 = DNP. VNA-trim at bring-up
  (target S11 < −10 dB, 1559–1606 MHz) on a 50 Ω controlled-impedance trace.
- **Keep-out:** 4.00 × 6.25 mm ground clearance under/around AE1 (W3011A datasheet),
  ground area ringed with vias; reserve a board corner. 50 Ω feed line.
- Passive antenna — the MAX-M10S RF_IN is 50 Ω with an **internal DC block** (no
  external DC-block cap) and an internal LNA (low-gain mode default) that supplies
  the gain; no external LNA/bias-tee. (Per u-blox MAX-M10S integration manual
  UBX-20053088. LNA_EN available if an active antenna is ever fitted.)
- **Antenna contingency (cap-select U.FL):** RF_IN taps two series positions —
  **Rm1** (0 Ω → the on-board W3011A, default) and **Cs1** (DNP → **J6**, a
  Hirose U.FL-R-SMT-1 on `Connector_Coaxial:U.FL_…`). Populate exactly one: to
  run an external antenna, DNP Rm1, fit Cs1 (0 Ω or a DC-block cap), and cable
  in via the U.FL. A *passive* external patch needs no bias. For an *active*
  antenna (built-in LNA), an on-board **bias-tee** is present but **DNP** — fit
  Cs1 as a DC-block cap (~10–33 pF), **L3** as an RF choke from +3V3 to the
  Cs1↔J6 node, and **C33** (100 nF) as the +3V3 RF bypass; DC then rides up the
  coax to the antenna LNA while Cs1 keeps it off RF_IN. Keeps the tiny chip
  antenna as the cheap default while leaving a populate-only path to a
  higher-gain external element — no respin.

### Power: TPS63900DSKR (buck-boost)

- Single-inductor buck-boost with **nanoamp-class quiescent current** and a
  selectable dual-output-voltage feature — ideal for a primary-cell or Li-ion
  device whose input spans both above and below 3.3V over its discharge curve.
- Input range covers 1×Li-ion (3.0–4.2V), 2×alkaline/NiMH (1.8–3.2V), or a
  LiSOCl₂ cell. Output set to **3.3V**.
- Powers everything: STM32 (VDD/VDDA/VDDUSB), MAX-M10S (VCC/VCC_RF/V_IO),
  LIS3DH, and the V_BCKP tap.
- 0.4A capability comfortably covers the GNSS (~11.5mA acq, up to 100mA inrush) and USB.
  (The optional WiFi module is expressly **not** on this rail — its 350mA TX
  bursts get a dedicated LDO from VSYS; see the WiFi section.)
- CFG1/2/3 are read once at startup by the resistor-to-digital interface
  (each pin → 1% resistor → GND, then the pins are disabled): R27 CFG1 =
  36.5kΩ (V_O(2) = 3.3V), R28 CFG2 = 0Ω (input current limit = Unlimited),
  R29 CFG3 = 16.2kΩ (V_O(1) = 3.3V). SEL is strapped to GND — no spare GPIO
  for runtime DVS, and both presets read 3.3V anyway so a SEL fault is
  harmless. EN tied to VIN (always on).

### Accelerometer: LIS3DHTR (LGA-16)

- 3-axis, low-power (µA-class), I2C — on I2C1 (addr 0x18/0x19) alongside the
  OLED (0x3C) and the audit-log EEPROM (0x50–0x53); GNSS is on UART.
- **Wake-on-motion** (INT1) lets the MCU sleep in Stop mode and only run the
  GNSS/TOTP pipeline when the device is handled.
- **Tamper detection** (free-fall / orientation, OR'd onto the INT1 pin) —
  optional policy to zeroize the TOTP secret in flash if the enclosure is
  disturbed while armed.
- **Peripheral power gate** (`PERI_EN`, freed from the 2nd accel-interrupt
  pin): a high-side load switch (Sensors Q3 AO3401A / Q4 AO3400A, R30/R31,
  C31) powers **+3V3_SW** for the OLED, the audit EEPROM, and the I2C1
  pull-ups (R9/R10) — all gated off in Stop so they can't leak. The LIS3DH
  stays on always-on +3V3 (it's the wake source); FW drives SCL/SDA low
  before Stop so the powered accel never floats on the unpulled bus. The lock
  link (PB0/PB1, R11/R12) is a **separate** bus and stays always-on.

### WiFi (optional): ESP32-C3-MINI-1 + AP2112K-3.3

Optional 2.4GHz link (provisioning, NTP cross-check, later OTA). Lives on its
own sheet (`wifi.kicad_sch`) — **depopulate the sheet to omit**; nothing else
references it.

- **Own regulator, own rail.** AP2112K-3.3 (600mA LDO, U6) fed from **VSYS**,
  not from the 3V3 buck-boost rail: an 802.11b TX burst is **350mA @ +21dBm**
  (C3-MINI-1 datasheet), which would eat the TPS63900's 400mA rating at
  coincident peaks and ripple the GNSS VCC_RF supply. Off-state cost: AP2112K
  standby 0.01µA typ / 1µA max; EN-low engages an internal 60Ω VOUT discharge,
  so a power cycle re-straps cleanly in milliseconds.
- **3 MCU pins total:**
  - **PB5 = WIFI_PWR** → U6 EN (R26 100k pulldown — off by default, incl.
    through MCU reset). No ESP EN/RESET pin: **power cycle = reset** (module EN
    has a local 10k+1µF RC).
  - **PA2 = WIFI_TXD** (LPUART1_TX/USART2_TX) → ESP IO20 via 1k. **Doubles as
    the IO9 boot strap** (10k from the TX net to IO9): hold PA2 GPIO-low across
    a WIFI_PWR power-up → ROM UART loader; leave Hi-Z/idle-high → flash boot.
  - **PA3 = WIFI_RXD** (LPUART1_RX) ← ESP IO21 via 1k; LPUART1 gives
    wake-from-Stop on RX.
- **Flashing the ESP:** STM32 firmware exposes a USB-CDC transparent bridge
  (maps DTR/RTS semantics onto the PWR/strap sequence) — stock `esptool.py`
  flashes MD2 through the MCU unmodified.
- **Later (STM32-from-WiFi):** the app jumps to a UART bootloader on LPUART1.
  PA2/PA3 = USART2 = an STM32U0 ROM-bootloader UART (AN2606 — verify for U083),
  so R24/R25 (0R, DNP) from ESP IO4/IO5 to BOOT0/NRST let the ESP reflash even
  a blank MCU.
- **FW policy:** prefer WiFi when USB-powered (VSYS ≈4.6V → full 3.3V). On
  battery below ~3.5V the LDO drops out toward the C3's 3.0V floor — gate WiFi
  on power state. Keep WiFi TX and GNSS acquisition time-separated (RF hygiene);
  place the module's PCB antenna at a board edge with the Espressif keep-out.
- **Displaced pins:** ACC INT1 PA2→PB3 (EXTI3), which now also carries tamper
  (2nd interrupt generator OR'd onto INT1 via CTRL_REG3 I1_IA2). The 2nd accel
  interrupt *pin* is dropped, freeing PA8 → **PERI_EN** (peripheral power-gate
  → Sensors Q3). PB5 carries WIFI_PWR (PA5/BTN1 owns EXTI line 5, so PB5 can't
  take an INT).
  **No spare GPIO remains** on the 32-pin package.

## Geofence + TOTP Logic

```
   wake (motion INT1 or duty timer)
        │
        ▼
   power GNSS ──► acquire fix ──► parse NMEA (RMC/GGA/GSA)
        │                              │
        │                       fix valid? sats ≥ N, HDOP ≤ H?
        │                              │ yes
        ▼                              ▼
   discipline RTC from PPS      inside geofence? (haversine ≤ radius)
        │                              │ yes
        ▼                              ▼
   RTC = TOTP time base    ─────►  totp_generate_current()
                                       │
                                       ▼
                                emit code (UART + strobe), blink green
        out-of-fence / no fix / stale clock ──► no code, blink red
```

- **Geofence test:** haversine distance from fix to each authorized center;
  inside if ≤ radius. Centers/radii stored in flash (provisioned over USB).
- **Fix gating:** require GNSS valid flag, ≥ N satellites, HDOP ≤ H, and an
  RTC that has been disciplined within a max-staleness window. Reject codes if
  the clock has not seen PPS/UTC recently enough (prevents replay with a frozen
  clock).
- **TOTP:** `smalltotp` (`totp_generate_current`) with the RTC-derived Unix
  time; 6 digits / 30 s by default. Secret stored base32, decoded at boot.

## Power Tree

Resolved: **1S Li-ion (rechargeable)**, **USB-C powers + charges + provisions**,
GNSS kept hot via **V_BCKP** (see decisions below).

```
 USB-C ─VBUS─┬─ USBLC6-2SC6 (ESD: VBUS, D+, D-)
 (GCT        │      D+/D- ─────────────► STM32 USB (PA11/PA12)
  USB4105)   │      CC1/CC2 ─ 5.1k ─ GND (UFP/sink)
             │
             ├─ MCP73831T-2ACI/OT ──BAT── 1S Li-ion ──┐  (charge; Rprog sets Ichg)
             │   (VBUS in, STAT→LED)                  │
             │                                        │
             └─ Schottky ─┐                  load-share P-FET (AO3401A):
                          ▼                  src=BAT, drn=SYS, gate=VBUS
                         SYS ◄────────────────── ON when VBUS absent (run from BAT)
                          │                       OFF when VBUS present (run from VBUS,
                          │                                              charge cleanly)
                          ▼
                  TPS63900DSKR ──── 3V3 rail ──┬── STM32U083  VDD/VDDA-VREF+/VDDUSB (~5–25mA)
                  (buck-boost,                 ├── MAX-M10S   VCC / VCC_RF / V_IO   (~12mA acq, 100mA inrush)
                   ~75nA Iq, L=2.2µH,          ├── LIS3DH     VDD / VDD_IO          (~2µA–2mA)
                   Cin/Cout per DS)            ├── V_BCKP tap (always-on, GNSS RTC/ephemeris backup)
                                               └── pull-ups, LEDs

 (SYS also feeds) ► AP2112K-3.3 ── WIFI_3V3 ── ESP32-C3-MINI-1   (OPTIONAL; EN ← PB5, default off,
                    (600mA LDO)                (350mA TX bursts)   <1µA off — WiFi never loads the 3V3 rail)
```

SYS (TPS63900 VIN) is VBUS-via-Schottky (~4.7V) when USB present, else BAT
(3.0–4.2V) — both inside the TPS63900 1.8–5.5V input range, so the buck-boost
outputs a steady 3.3V either way.

### Buck-boost: TPS63900DSKR

- L: 2.2µH shielded (per datasheet typical), DCR-low for efficiency.
- Cin: 10µF X7R; Cout: 2×10µF X7R (low ESR for ripple at the GNSS RF supply).
- Output: 3.3V via CFG straps — R27 36.5k (CFG1, V_O(2)=3.3V), R28 0R (CFG2,
  I_lim Unlimited; needs L Isat ≥ 2A — FNR3015S2R2MT is 2A), R29 16.2k (CFG3,
  V_O(1)=3.3V); SEL = GND (V_O(1) active). Read once at EN rising — power-cycle
  to change. 1%/≤200ppm parts, short CFG traces (<10pF), no probes/caps on CFG.
- EN: tied to VIN (always on).
- Thermal pad to ground pour.

### USB-C input + Li-ion charging

Built from parts already used in sibling projects (BOM consolidation):

- **USB-C receptacle:** GCT **USB4105-xx-A** 16-pin USB-2.0 receptacle
  (MPN USB-TYPE-C-019, LCSC C2927039) — the house-standard connector
  (footprint `Connector_USB:USB_C_Receptacle_GCT_USB4105-xx-A_16P_TopMnt_Horizontal`,
  used in pulsarfab + others). Alt: HRO `TYPE-C-31-M-12` (C165948, notchdeck).
  - **CC1/CC2:** 5.1kΩ pull-downs to GND (device/sink/UFP role; advertises
    default USB current). Two resistors, one per CC line.
  - **D+/D-:** to STM32 USB (PA11/PA12), through the ESD device.
  - **VBUS:** 10µF bulk + feeds charger and the SYS power path.
  - **SHIELD:** to chassis/GND via a 1MΩ ∥ 4.7nF (or direct, TBD).
- **ESD:** **USBLC6-2SC6** (SOT-23-6, LCSC C2687116) on VBUS/D+/D- — same part
  the reefvolt/notchdeck boards use.
- **Charger:** **MCP73831T-2ACI/OT** (SOT-23-5, LCSC C424093) — the house Li-ion
  charger (used in notchdeck). Single-cell, 4.2V (the "-2" variant).
  - VBUS → VDD (input); VBAT → battery (+) node; STAT → indicator LED + 1kΩ.
  - **Rprog** sets charge current: I_chg ≈ 1000V / R_prog. Pick for the cell,
    e.g. 4.7kΩ → ~210mA (≈0.5C of a 400–500mAh cell). 4.7µF on VDD and VBAT.
  - **TODO:** finalize cell capacity → Rprog; add NTC/temperature qualification
    only if the cell pack lacks its own protection.
- **Power path (load sharing):** **AO3401A** P-FET (SOT-23, LCSC C15127) — the
  house P-MOS. Standard Microchip/Adafruit load-share:
  - Q: source=BAT, drain=SYS, gate→VBUS (100kΩ gate-to-GND pull-down).
  - VBUS present → gate high → P-FET OFF → battery isolated from the system load
    (charger sees only the battery → clean charge termination); SYS is fed from
    VBUS through a small **Schottky** (e.g. house SS-series) → run + provision
    from USB without cycling the battery.
  - VBUS absent → gate pulled low → P-FET ON → battery powers SYS.
- **Battery protection:** use a protected 1S Li-ion pack (integrated
  over/under-voltage + over-current), or add a 1S protection IC (e.g. DW01 +
  dual-FET) if using a bare cell. JST-PH 2-pin battery connector (house style).

This keeps provisioning-over-USB clean (system runs from VBUS, battery charges)
and adds no quiescent penalty when unplugged (P-FET on, ~75nA TPS63900 Iq path).

### Supply decoupling

- STM32: 100nF per VDD/VDDA/VDDUSB + 4.7µF bulk; VREF+ filtered (1µF + 10nF).
- MAX-M10S: VCC 100nF + 10µF; **VCC_RF** clean (ferrite bead + 100nF/10pF) —
  RF supply isolation matters for sensitivity; V_BCKP 100nF.
- LIS3DH: 100nF VDD + 100nF VDD_IO.

## Pin Budget: STM32U083KCU6 (UFQFPN-32)

32 perimeter pins + exposed pad. Assignments below are preliminary and must be
verified against the STM32U083 datasheet AF table for the UFQFPN-32 package.

| Pin | MCU | Function | Notes |
|-----|-----|---|---|
| 1 | VDD | 3V3 | 100nF + 4.7µF |
| 2 | PC14-OSC32_IN | LSE in | 32.768kHz crystal (RTC) |
| 3 | PC15-OSC32_OUT | LSE out | 32.768kHz crystal (RTC) |
| 4 | PF2-NRST | Reset | 100nF to GND |
| 5 | VDDA/VREF+ | 3V3 analog | 1µF + 10nF |
| 6 | PA0-CK_IN | GNSS PPS in | TIM2_CH1 input capture (RTC discipline) |
| 7 | PA1 | GNSS EXTINT | MCU → GNSS wake / time-mark |
| 8 | PA2 | WIFI_TXD | LPUART1_TX → ESP IO20 (1k); doubles as IO9 boot strap (10k) |
| 9 | PA3 | WIFI_RXD | LPUART1_RX ← ESP IO21 (1k); wake-from-Stop on RX |
| 10 | PA4 | GNSS RESET_N | open-drain output to GNSS |
| 11 | PA5 | Button | SW1 user button 1 (internal pull-up, to GND) |
| 12 | PA6 | LOCK_SDA | I2C3_SDA (AF4) ↔ lock (authenticated link; ephemerkey = master) |
| 13 | PA7 | LOCK_SCL | I2C3_SCL (AF4) → lock (authenticated link; ephemerkey = master) |
| 14 | PB0 | LED green | in-fence / code-valid |
| 15 | PB1 | LED red | out-of-fence / fault |
| 16 | VSS_1 | GND | |
| 17 | VDDUSB | 3V3 USB | 100nF (USB transceiver supply) |
| 18 | PA8 | PERI_EN | peripheral power-gate → Sensors Q3 (+3V3_SW); active-high, R31 pulldown = off at reset |
| 19 | PA9 | USART1_TX | → GNSS RXD (NMEA/UBX) |
| 20 | PA10 | USART1_RX | ← GNSS TXD (NMEA/UBX) |
| 21 | PA11 | USB_DM | USB FS (provisioning/console) |
| 22 | PA12 | USB_DP | USB FS (provisioning/console) |
| 23 | PA13 | SWDIO | debug |
| 24 | PA14 | SWCLK | debug |
| 25 | PA15 | Button | SW2 user button 2 (internal pull-up, to GND) |
| 26 | PB3 | LIS3DH INT1 | EXTI wake-on-motion (EXTI3) |
| 27 | PB4 | BUZZER_PWM | TIM3_CH1 → LS1 buzzer via Q2 low-side driver |
| 28 | PB5 | WIFI_PWR | → AP2112K EN (100k pulldown — WiFi off by default) |
| 29 | PB6 | I2C1_SCL | LIS3DH + OLED + log EEPROM + fuel gauge (and optional GNSS DDC) |
| 30 | PB7 | I2C1_SDA | LIS3DH + OLED + log EEPROM + fuel gauge (and optional GNSS DDC) |
| 31 | PF3-BOOT0 | Button + BOOT0 | SW3 user button 3 (to +3V3); 10k pull-down = boot from flash. Hold SW3 at reset → USB DFU |
| 32 | VSS_2 | GND | |
| EP (33) | GND | thermal/exposed pad | via stitching |

**Peripheral summary:** USART1 (GNSS), LPUART1 (WiFi, wake-from-Stop), I2C3
(master, authenticated lock link: PA6/PA7), I2C1 (accel, OLED,
log EEPROM, fuel gauge), TIM2 capture (PPS), RTC+LSE (TOTP time), USB FS (provisioning),
1×EXTI (accel INT1, PB3), TIM3_CH1 (buzzer PWM, PB4), SWD (debug), WIFI_PWR
gate (PB5), PERI_EN peripheral load-switch gate (PA8).
**No spare GPIO** — the 32-pin package is fully allocated.

**Notes**
- USB DM/DP must land on PA11/PA12. On the UFQFPN-32, PA9/PA10 and PA11/PA12
  share pads with a SYSCFG remap — here PA9/PA10 (pins 19/20) carry USART1 and
  PA11/PA12 (pins 21/22) carry USB. Verify the remap configuration in firmware
  (`SYSCFG` PA11/PA12 remap) matches this intent.
- GNSS UART stays on **USART1** — the duty-cycle design keeps the MCU awake
  while GNSS is on. LPUART1 (wake-on-RX in Stop mode) is allocated to the WiFi
  link on PA2/PA3.
- The lock link and the LEDs **swapped pins** (rev 0.2): PB0/PB1 carry no I2C
  alternate function on the U083 (caught by the Rust firmware's compile-time
  AF check), while PA6/PA7 are I2C3 SDA/SCL at AF4. LEDs are
  function-agnostic, so they took PB0/PB1.

## Storage, Logging & OTA

Three data classes, three homes — chosen so nothing secret ever leaves the MCU
and no new pins are spent (the 32-pin package is fully allocated):

| Data | Where | Why |
|---|---|-----|
| Secrets (TOTP, lock-pairing, device/log keys) + config (geofence table) | **Internal flash**, last 2×2KB pages, ping-pong journal + CRC | Desolder-proof; hidden from SWD via RDP (+HDP secure-hide — verify RM0503). Config is <1KB and rarely written. |
| Audit log (code emissions, unlock commands, fence enter/exit, tamper, power events) | **U7 M24M02E-F** (2Mbit I2C EEPROM, UFDFPN8 2×3mm, `storage.kicad_sch`) at 0x50–0x53 on I2C1 | Zero new pins — rides the existing accel/OLED bus. 256KB ≈ 8,000 records ≈ 13 months rolling at 20 events/day. 350nA standby; 4M-cycle endurance; lockable 256B ID page for board serial. |
| Staged STM32 OTA image | **ESP32-C3's own 4MB flash** (WiFi sheet) | The ESP downloads it anyway; the image survives power-fail mid-update, so no internal A/B slots are needed. |

**Log format.** Fixed 32B records in an append-only ring: sequence, RTC
timestamp, event type, fix quality, truncated code hash, and a **chained
HMAC-SHA1 tag** (key = internal device key; reuses smalltotp's HMAC). Records
are **encrypted** with an internal-flash key before hitting the external chip —
the EEPROM is desolderable, so it stores no plaintext and no secrets, and any
excised or edited record breaks every subsequent chain tag (tamper-evident
audit trail). Torn writes are detected by CRC + sequence and skipped. 4M-cycle
endurance → decades of ring logging.

**Counters.** The confirm-TOTP event counter (bumped every fire/relock) and
the config anti-rollback `seq` are monotonic and must survive power loss, but
they are written far more often than the ~1 KB config blob — so they live in a
**separate 2×2KB append region**, not the config record. Unlock/lock events
aren't frequent, but we size for them anyway: exploiting NOR's program-`1→0` /
bulk-erase asymmetry, each bump programs the next fresh 64-bit double-word
(STM32U0 ECC forbids re-writing a unit before erase, so we append rather than
re-flip in place) and the region is bulk-erased only when full. That's 256
bumps per 2 KB page, ~5M bumps across the two-page queue before the erase-cycle
limit (verify the U0 number) — **>100 years even at a heavy 100 events/day**,
so no reserve-ahead is needed for wear. A reboot resumes from the last
persisted counter; the small skip is absorbed by the receipt validator's
RFC 4226 look-ahead, so no counter is ever reused. Built on the
`sequential-storage` log (ECC-safe single-write-per-word), not hand-rolled.

**OTA flow (STM32-from-WiFi; later firmware work, no extra hardware):**

1. ESP32 downloads the STM32 image into its own flash partition and verifies
   the image HMAC (shared device key; asymmetric signatures possible later).
2. The STM32 app sets an "update pending" flag in config flash and reboots
   into the bootloader (first ~16KB, WRP write-protected, never self-erases).
3. The bootloader streams CRC'd chunks over LPUART1, verifies the whole-image
   tag, then erases and rewrites the app region.
4. Power-fail ≠ brick: the image persists in ESP flash, so recovery is
   "bootloader asks again." Fallbacks stay layered: USB DFU via ROM bootloader
   (SW3/BOOT0) on the bench; R24/R25 DNP links for ESP-driven ROM recovery.

## Code Output Interface (to the companion lock)

The companion **lock board lives in this repo at `hardware/lock/`** (a second
PCB; see its README). ephemerkey talks to it over an authenticated I2C bus —
**ephemerkey is the master** — on J2, a **right-angle 4-pin JST-PH** (`S4B-PH-K`,
a standard 4-pin I2C cable), straight-through to the lock's J2:

| J2 pin | net | dir | function |
|---|-----|-----|---|
| 1 | GND | — | common ground / actuation return |
| 2 | VSYS | out | **battery/system rail — powers the lock** (the lock has no own cell) |
| 3 | LOCK_SDA | bidir (PA6, I2C3) | I2C data |
| 4 | LOCK_SCL | out (PA7, I2C3) | I2C clock — ephemerkey is master; also the lock's wake edge |

The lock is **powered from ephemerkey** over this connector (J2.2 = VSYS, the
load-share/battery rail); it carries no local battery. There is **no separate
wake/trigger line** — the lock sleeps in power-down and wakes on the first I2C
START (a pin-change interrupt on SCL). The master sends a dummy/wake transfer,
then retries once the target is up.

**Current caveat:** the lock's logic *and* its boost/actuator draw come through
this cable. A 12 V solenoid pull-in is ~3–4 A from VSYS — beyond a JST-PH contact
(~2 A) and ephemerkey's load-share path. Keep actuation to the **6 V servo** / low
duty buffered by the lock's reservoir caps, or add a heavier dedicated power feed.

The I2C pull-ups (≈4.7 kΩ, R11/R12) stay on **ephemerkey** to **+3V3** — do not
pull the bus to VSYS (verify PA6/PA7 voltage tolerance in the datasheet before ever
reconsidering; a 3.3 V bus is correct regardless). The lock's open-drain target
sinks fine, and its VIH (~0.7·VSYS) is met by the 3.3 V idle level across the
discharge curve. Keep the cable short (100 kHz).

**Register interface + authentication (firmware HMAC, no secure element).** The lock
exposes `STATUS` (read), `NONCE` (read), and `COMMAND` (write) registers; a pairing
secret (distinct from the TOTP secret) is held in flash on both boards.

- **Probe lid state** (no auth): wake the lock (I2C START) and read `STATUS` — door
  open/closed, bolt locked/unlocked, and whether a servo is fitted (show on the OLED).
- **Lock / unlock** (authenticated), on a request — (in-fence) ∧ (valid fix) ∧ (fresh
  clock) ∧ (button/armed): read `NONCE`, then write `COMMAND` =
  `cmd ‖ HMAC-SHA1(secret, nonce ‖ cmd ‖ code)`, cmd ∈ {UNLOCK, LOCK}. The lock
  constant-time compares against the armed nonce (replay-proof) and only then drives
  the actuator — **LOCK** drives a fitted servo to the lock angle; **UNLOCK** releases
  (solenoid peak-and-hold, or servo to the unlock angle).

**Firmware plan.** Both boards use **HMAC-SHA1**, reusing `smalltotp`'s existing
HMAC-SHA1 (no extra crypto; HMAC-SHA1 stays sound — it doesn't rely on SHA1 collision
resistance). ephemerkey drives the I2C master transactions (I2C3, PA6/PA7) from firmware;
the lock side (ATtiny1616 sleep/wake, door-hall sampling, peak-and-hold or servo drive,
fail-secure timing) is specified in `hardware/lock/README.md`.

## Security Considerations

- **Secret at rest:** TOTP shared secret stored in MCU flash; enable RDP
  (level 1 minimum) in production. Optionally wrap with the U0 AES engine using
  a key derived from a device-unique value.
- **Tamper:** LIS3DH free-fall/motion-while-armed (2nd interrupt generator
  OR'd onto the INT1 pin) can trigger secret zeroization. Policy is
  firmware-configurable.
- **Anti-replay on clock:** reject code generation if the RTC has not been
  disciplined by GNSS within a configurable staleness window — a frozen or
  rolled-back clock must not yield valid codes.
- **Geofence integrity:** geofence table also in protected flash; provisioning
  over USB requires the device be in an explicit provisioning mode (button +
  USB), not silently writable.

## Resolved Decisions

- **MCU:** STM32U083KCU6 (UFQFPN-32, LCSC C22459164) — ULP Cortex-M0+, RTC,
  USB, 256KB flash. Kept over the JLCPCB-stocked STM32U073KCU6 to retain AES.
- **GNSS:** MAX-M10S-00B over UART (USART1), PPS to TIM2 capture.
- **Antenna:** W3011A passive chip antenna + π-match into RF_IN.
- **Power:** TPS63900DSKR buck-boost, 3.3V out.
- **Battery:** 1S Li-ion (rechargeable), JST-PH; protected pack or add 1S
  protection IC. Buck-boost spans the 3.0–4.2V discharge curve.
- **USB-C:** powers + charges + provisions. GCT USB4105 (USB-TYPE-C-019,
  C2927039), USBLC6-2SC6 ESD, MCP73831T-2ACI/OT charger, AO3401A load-share
  P-FET — all house parts (see § USB-C input + Li-ion charging).
- **GNSS power:** keep V_BCKP alive (~3µA, retains ephemeris) for hot starts
  (~1–2s vs ~25s cold); VCC stays on the always-on 3V3 rail — PA8 is now PERI_EN,
  so no VCC gate. Deep-sleep via EXTINT/UBX-RXM-PMREQ software standby: floor
  ≈49µA, V_IO-dominated (VCC 120nA, V_IO 46µA, V_BCKP 3µA). A VCC-only gate would
  save only that 120nA — worthless; the 28µA hardware-backup floor needs V_IO
  gated too, not worth the back-power cost. [MAX-M10S DS UBX-20035208, T15/17]
- **Accel:** LIS3DHTR on I2C1, INT1 = wake + tamper (INT2 generator OR'd onto the INT1 pin; 2nd pin freed → PERI_EN).
- **Time base:** STM32 RTC w/ LSE crystal, GNSS-disciplined.
- **Code output / lock link:** authenticated I2C (ephemerkey = master) on J2, which
  also carries VSYS to power the companion lock. See § Code Output Interface.

## Open Questions

1. ~~**Battery chemistry / holder**~~ **RESOLVED:** 1S Li-ion (rechargeable),
   JST-PH connector; USB-C charges via MCP73831 + load-share. Use a protected
   pack or add a 1S protection IC. Remaining: pick cell capacity → set Rprog.
2. ~~**GNSS power gating**~~ **RESOLVED:** keep V_BCKP alive for hot starts
   (energy math strongly favors it); VCC left ungated (PA8 reassigned to
   PERI_EN) — deep-sleep the receiver via EXTINT/PMREQ backup, not a VCC cut.
3. **W3011A placement/keep-out:** confirm ground clearance and match topology
   against the antenna datasheet; reserve a board corner.
4. ~~**TPS63900 CFG/SEL strapping**~~ **RESOLVED:** SEL = GND (no spare GPIO
   for DVS); R27 CFG1 = 36.5k → V_O(2) 3.3V, R28 CFG2 = 0R → I_lim Unlimited,
   R29 CFG3 = 16.2k → V_O(1) 3.3V (the active preset). Both presets 3.3V, so
   no sleep rail — the TPS63900's 75nA Iq doesn't need one.
5. ~~**USB-C role**~~ **RESOLVED:** USB-C powers + charges + provisions
   (GCT USB4105, MCP73831 charger, AO3401A load-share). Remaining: USB-C SHIELD
   tie (direct vs 1MΩ∥cap).
6. **Lock interface electrical level:** 3.3V logic direct, or opto-isolated /
   open-drain only? Depends on the companion lock board's input stage.
6. **Provisioning UX:** USB CDC console only, or also a button-driven on-device
   secret-entry mode?
7. ~~**Display**~~ **RESOLVED:** a 128×32 I²C OLED (DS1) mounts on a 4-pin 0.1"
   header on I²C1 (shares the bus with U5 LIS3DH; addresses 0x3C vs 0x18). Shows
   the code / status for manual entry. (Enclosure style still TBD.)
8. **LSE vs internal:** is a 32.768kHz crystal populated, or run RTC from LSI +
   GNSS discipline only (cheaper, less accurate between fixes)?

## Parts List

### Active Components

| Part | MPN | Package | Qty | Purpose | LCSC | Stock | JLC |
|---|-----|---|-----|---|---|---|-----|
| MCU | STM32U083KCU6 | UFQFPN-32 | 1 | ULP Cortex-M0+, RTC, USB, TOTP | C22459164 | ~10 | extended |
| GNSS module | MAX-M10S-00B | LCC-18 9.7×10mm | 1 | u-blox M10 GNSS (time + place) | C4153167 | ~183 | extended |
| GPS antenna | W3011A | 1206 SMD | 1 | 1.559–1.606 GHz passive antenna | C5830926 | ~101 | extended |
| Buck-boost | TPS63900DSKR | WSON-10-EP | 1 | Battery → 3.3V, nanoamp Iq | C1518762 | ~4187 | extended |
| Accelerometer | LIS3DHTR | LGA-16 3×3 | 1 | Motion wake + tamper | C15134 | ~89984 | extended |
| USB-C conn | USB-TYPE-C-019 (GCT USB4105) | 16P SMD | 1 | USB-C power/charge/data | C2927039 | ~34k | extended |
| Li-ion charger | MCP73831T-2ACI/OT | SOT-23-5 | 1 | 1S Li-ion charger (4.2V) | C424093 | ~2.7k | extended |
| USB ESD | USBLC6-2SC6 | SOT-23-6 | 1 | USB VBUS/D± ESD | C2687116 | ~231k | extended |
| Load-share FET | AO3401A | SOT-23 | 1 | USB/battery power path (P-FET) | C15127 | ~1.2M | extended |
| Fuel gauge | MAX17048G+T10 | TDFN-8 2×2 | 1 | 1S battery SoC (ModelGauge), I2C1 @0x36, 3µA hibernate | C2682616 | — | extended |

> LCSC numbers verified 2026-06-21 (jlcsearch API; STM32U083KCU6 confirmed on
> the LCSC storefront under C22459164, which jlcsearch does not index). Stock
> figures are a snapshot — recheck before ordering. All parts are JLCPCB
> **extended** (per-part setup fee); none are basic.
>
> **STM32U083KCU6 (C22459164)** is in the LCSC/JLCPCB library, so the MCU is
> JLCPCB-assemblable — but storefront stock is thin (~10), so verify availability
> before an assembly run. If stock is short, the pin-compatible
> **STM32U073KCU6** (UFQFPN-32, C22445363) is a drop-in alternative that drops
> only the unused AES accelerator.

### KiCad Library Map

All five anchor parts are in **KiCad's bundled libraries** — no custom symbols
or footprints are needed. When placing each part in the schematic, use the
symbol below and assign the listed footprint, then set the `LCSC`, `MPN`, and
`Manufacturer` fields (a project Field-Name Template pre-defining these three
fields is recommended). The project's own symbol/footprint libs are kept empty,
reserved for future non-standard parts.

| Part | Symbol (lib:name) | Footprint (lib:name) | LCSC | MPN |
|---|---|---|---|-----|
| MCU | `MCU_ST_STM32U0:STM32U083KCUx` | `ephemerkey:UFQFPN-32-1EP_5x5mm_P0.5mm_EP3.5x3.5mm` (project copy → generic QFN-32 3D model) | C22459164 | STM32U083KCU6 |
| GNSS | `RF_GPS:MAX-M10S` | `ephemerkey:ublox_MAX` (project copy of RF_GPS:ublox_MAX + 3D model) | C4153167 | MAX-M10S-00B |
| Antenna | `Device:Antenna_Chip` (2-pin: feed+GND) | `RF_Antenna:Pulse_W3011` (pads 1,2,2) | C5830926 | W3011A |
| Buck-boost | `Regulator_Switching:TPS63900` | `Package_SON:WSON-10-1EP_2.5x2.5mm_P0.5mm_EP1.2x2mm` | C1518762 | TPS63900DSKR |
| Accel | `Sensor_Motion:LIS3DH` | `Package_LGA:LGA-16_3x3mm_P0.5mm` | C15134 | LIS3DHTR |
| USB-C | `Connector:USB_C_Receptacle_USB2.0_16P` | `Connector_USB:USB_C_Receptacle_GCT_USB4105-xx-A_16P_TopMnt_Horizontal` | C2927039 | USB-TYPE-C-019 |
| Charger | `Battery_Management:MCP73831-2-OT` | `Package_TO_SOT_SMD:SOT-23-5` | C424093 | MCP73831T-2ACI/OT |
| USB ESD | `Power_Protection:USBLC6-2SC6` | `Package_TO_SOT_SMD:SOT-23-6` | C2687116 | USBLC6-2SC6 |
| Load-share FET | `Device:Q_PMOS_GSD` | `Package_TO_SOT_SMD:SOT-23` | C15127 | AO3401A |
| OLED (display) | `Display_Graphic:ER_OLEDM0.91_1x-I2C` | `Connector_PinSocket_2.54mm:PinSocket_1x04_P2.54mm_Vertical` | — | 128×32 I²C OLED module (DS1, 4-pin 0.1" female socket) |

Manufacturers: STM32U083KCU6 / LIS3DHTR = STMicroelectronics; MAX-M10S-00B =
u-blox; W3011A = Pulse Electronics; TPS63900DSKR = Texas Instruments.

Notes:
- GNSS footprint is `ephemerkey:ublox_MAX` — a project copy of the bundled
  `RF_GPS:ublox_MAX` (18-pad LCC, shared MAX-series land pattern) with its
  `(model …)` repointed to the vendored `lib/3dmodels/ublox_MAX-M10S.step`.
- `RF_Antenna:Pulse_W3011` has 3 pads numbered 1,2,2 (feed + two GND) — it pairs
  with the 2-pin `Device:Antenna_Chip` symbol. Honor the antenna ground keep-out
  (4.0 × 6.25 mm for the W3011A variant) and 50 Ω feed; see § GPS Antenna.
- STM32 symbols ship with an empty Footprint field — assign the UFQFPN-32 one
  above explicitly (use the `_ThermalVias` variant for the EP if preferred).
- **User buttons (×3):** SW1→PA5, SW2→PA15 (active-low, MCU pull-ups). SW3→PF3/
  BOOT0 (active-high to +3V3; R1 10k pulldown = default flash boot). Holding SW3
  at reset enters the STM32U0 ROM bootloader → **USB DFU** over USB-C (AN2606;
  crystal-less USB via HSI48+CRS). All three use `ephemerkey:SW_Push_1P1T_XKB_TS-1187A`.
- **3D models:** most footprints carry bundled models. MAX-M10S and the SW
  buttons are **vendored** in `lib/3dmodels/`; the MCU's UFQFPN-32 footprint
  (project copy) points at KiCad's **generic QFN-32-1EP_5x5mm_P0.5mm** model
  (UFQFPN is the ultra-thin variant of the same body — only the height differs).
  **Only W3011A still needs a downloaded STEP** — see
  `hardware/lib/3dmodels/README.md`.

### Power Passives

| Part | Value | Package | Qty | Purpose |
|---|---|---|-----|---|
| Inductor | 2.2µH shielded | 2520/2016 | 1 | TPS63900 buck-boost |
| Input cap | 10µF 16V X7R | 0805 | 1 | TPS63900 VIN |
| Output cap | 10µF 16V X7R | 0805 | 2 | TPS63900 VOUT |
| CFG straps | 36.5k / 0R / 16.2k 1% | 0402 | 3 | TPS63900 CFG1/2/3 → GND (R27/R28/R29); EN → VIN, SEL → GND (no resistor) |
| Bulk | 4.7µF 16V X7R | 0805 | 1 | 3V3 rail bulk |
| Decoupling | 100nF 16V X7R | 0402 | ~10 | per-IC supply decoupling |

### GNSS / RF Passives

| Part | Value | Package | Qty | Purpose |
|---|---|---|-----|---|
| RF match series | DNP/0Ω (tune) | 0402 | 1 | W3011A π-match series element |
| RF match shunt | DNP (tune) | 0402 | 2 | W3011A π-match shunt elements |
| VCC_RF ferrite | ferrite bead | 0402 | 1 | RF supply isolation |
| VCC_RF cap | 100nF + 10pF | 0402 | 2 | RF supply decoupling |
| GNSS bulk | 10µF 16V X7R | 0805 | 1 | MAX-M10S VCC bulk |
| V_BCKP cap | 100nF | 0402 | 1 | GNSS backup-supply decoupling |

### MCU / Misc Passives

| Part | Value | Package | Qty | Purpose |
|---|---|---|-----|---|
| LSE crystal | 32.768kHz | 3215 | 1 | RTC time base |
| LSE load caps | ~6–12pF | 0402 | 2 | crystal load (per CL) |
| VREF filter | 1µF + 10nF | 0402 | 2 | VDDA/VREF+ |
| BOOT0 pull-down | 10k | 0402 | 1 | boot from flash |
| NRST cap | 100nF | 0402 | 1 | reset filter |
| I2C pull-ups | 4.7k | 0402 | 2 | I2C1 SCL/SDA |
| Button | tactile SMD | — | 1 | provision / show-code |
| LEDs | red / green | 0402 | 2 | status |
| LED resistors | 1k | 0402 | 2 | LED current limit |
| USB connector | USB-C / micro | — | 1 | provisioning + (opt) power |
| USB CC resistors | 5.1k | 0402 | 2 | USB-C CC (if USB-C) |
| Battery holder | per chemistry | — | 1 | see Open Questions |

## Schematic Sheet Plan

| Sheet | Contents |
|---|---|
| ephemerkey.kicad_sch | Top-level: STM32U083, SWD, USB, button, LEDs, lock interface, inter-sheet buses |
| psu.kicad_sch | Battery input + TPS63900 buck-boost + 3V3 distribution + V_BCKP tap |
| gnss.kicad_sch | MAX-M10S + W3011A antenna + π-match + RF supply + UART/PPS/EXTINT |
| sensors.kicad_sch | LIS3DH accelerometer + I2C + interrupt lines |

## Firmware Dependencies (STM32U083)

| Library | License | Purpose | Source |
|---|---|---|---|
| smalltotp | Apache-2.0 | TOTP / HMAC-SHA1 / Base32 / RTC time helpers | github/smalltotp (sibling) |
| STM32CubeU0 HAL/LL | BSD-3 | RTC, USART, I2C, USB, GPIO, low-power | ST (set CUBE_U0) |
| minmea (or hand-rolled) | MIT | NMEA sentence parser (RMC/GGA/GSA) | github.com/kosma/minmea |

Architecture: low-power superloop. Sleep in Stop mode; wake on LIS3DH motion
(INT1) or a duty-cycle RTC alarm; power/duty-cycle the GNSS; parse NMEA;
discipline the RTC from PPS; run the geofence test; generate and emit the TOTP
code; return to Stop. USB provisioning entered via button + USB enumeration.

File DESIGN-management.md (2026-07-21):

# ephemerkey Management Plane — Sets, Keys, Encoding, Web UI

Companion to `DESIGN-policies.md` (what policies exist) — this covers how
policies get **into** devices and how signed telemetry gets **out**: the key
model, the wire encoding, and the web UI that authors it all. Applies to both
personalities (Generator / LockController).

## The "set" — key-bound fleet model

An **ephemerkey set** is an owner keypair plus the devices enrolled under it.

| Key | Where | Algorithm | Purpose |
|-----|---|---|---|
| **Owner key** | web UI / operator (exportable, or WebCrypto non-extractable) | Ed25519 | signs every config document; the root of the set |
| **Device signing key** | generated ON-device (U0 TRNG), never leaves | Ed25519 | signs telemetry, receipts, enrollment proof |
| **Device agreement key** | generated on-device, pubkey exported at enrollment | X25519 | lets the UI encrypt secrets *to* a device |
| Zone/TOTP/pairing secrets | symmetric, delivered inside config | (existing HMAC-SHA1 machinery) | the data plane stays symmetric and cheap |

- `set_id = SHA-256(owner_pub)[0..8]` — devices are *bound* to the set by
  storing `owner_pub` at enrollment; every config they ever accept must verify
  under it. A config for set A is meaningless to a device in set B.
- **Enrollment (TOFU, physically gated):** device in provisioning mode
  (button + USB) emits an enrollment doc `{device_id, sign_pub, kx_pub, fw}`
  signed by its device key; the UI adds it to the roster and writes back
  `owner_pub`. First writer wins; re-keying requires physical provisioning
  mode again. Remote enrollment is deliberately impossible.
- **Owner rotation:** a rotation doc signed by the *old* owner key, or
  physical re-enrollment. (Losing the owner key = re-enroll everything —
  document this loudly in the UI.)

ECC choice: **Ed25519/X25519**, not P-256. No PKA hardware on the U083 either
way, `salty` is written for Cortex-M (verify ≈ tens of ms at 48 MHz, fine for
config-rate events), no ECDSA nonce-reuse footgun, and WebCrypto ships Ed25519
in current browsers (libraries like `@noble/curves` cover stragglers).

## Encoding: CBOR + COSE

Config documents and telemetry are **CBOR** (RFC 8949), wrapped in **COSE**
(RFC 9052) envelopes:

- **Config update** = `COSE_Encrypt0( COSE_Sign1(config, owner_key), device_kx )`
  — sign-then-encrypt. Signature = authority; encryption (ephemeral X25519 →
  HKDF → AES — the U083 has an AES engine) because configs *carry symmetric
  secrets* and the remote path traverses the ESP and the internet.
- **Telemetry** = `COSE_Sign1(events, device_key)` — no secrets inside
  (audit records are already encrypted at rest before they hit the EEPROM),
  so integrity/attribution only.

Why CBOR over the alternatives:

| | verdict |
|---|---|
| custom TLV (what the 65-byte lock blob uses) | right for a fixed tiny struct, wrong for a growing policy tree — every field addition is a migration |
| protobuf | schema compiler in the loop, no canonical bytes without care, signing needs wrapper conventions |
| JSON | not compact, not canonical, floats/strings ambiguity — hostile to signatures |
| **CBOR/COSE** | deterministic encoding rules for signing, integer-keyed maps stay tiny, decodes with `minicbor` (no_std, no alloc) on the M0+, native in JS (`cbor-x`), and COSE is *the* standard for exactly this shape of problem |

Skeleton (integer keys, unknown keys ignored → forward compatible):

```
config = {
  1: seq,          ; uint, strictly increasing per device (anti-rollback)
  2: set_id,       ; bstr[8]
  3: target,       ; device_id or 0 = whole set
  4: role,         ; 1 = generator, 2 = lock-controller
  5: keys,         ; [ {id, kind(totp/zone/pairing/confirm/decoy), secret,
                   ;    digits(4-10), display(plain/scatter/short/once), decoy_ref} ]
  6: zones,        ; [ {id, shape(circle/poly), coords, hdop, minsats} ]
  7: slots,        ; [ {key, policy, gates, action, progress, reset_on_invalid} ]
  8: policy-blobs, ; per-slot params, tagged by policy type
  9: device-opts   ; staleness window, tamper policy, buzzer, display
}

event = {
  1: seq, 2: device_id, 3: rtc_ts, 4: type,   ; unlock/lock/duress/tamper/
  5: detail, 6: chain_tag                     ; fence-enter/exit/power/config-ack
}
```

Device rules: reject bad signature, wrong `set_id`, `seq <=` stored seq (the
config journal already stores a monotonic sequence — same slot). A `config-ack`
telemetry event (echoing `seq` + config hash) closes the loop in the UI.

## Transports (same bytes everywhere)

The envelope is transport-independent — the device trusts only the
COSE layers, never the channel:

- **Local / USB:** provisioning mode (button + USB CDC). Web UI talks
  **WebSerial** directly from the browser (Chromium; elsewhere: download the
  `.ekcfg` blob and use a tiny CLI, or file-drop once USB-MSC-style ingest
  exists). Telemetry pulls the audit ring the same way.
- **Remote / WiFi:** the UI publishes the sealed blob (any dumb HTTPS
  endpoint or relay — it needs no trust); the ESP32-C3 fetches it, streams it
  over LPUART1, the STM32 verifies exactly as if it came over USB. Telemetry
  pushes back through the ESP as signed event batches.
- **Sneakernet:** the sealed blob is just bytes — QR-code chunks or a file on
  a phone work for air-gapped sites.

## Web UI — configuring the policy catalog

One page per set: roster (enrollment status, last-seen telemetry, config seq),
a **slot table** per device, and a policy editor per slot. Per-policy forms:

| Policy | UI controls |
|---|---|
| Master (AlwaysValid) | key slot picker; big red "no ceremony" warning |
| Time-gated sequence (N/Y/min-max) | steppers for N; duration fields for window + min/max gap; live validity check (`n·gap_min ≤ window`); progress visible/hidden toggle |
| Walk-time delay | dual duration slider "codes valid from +X to +Y after minting" (0 = instant); warning that a wide window multiplies guess surface → suggests longer digits |
| Code length / display | digits stepper 4–10 (entropy note at 10: 31-bit truncation cap); display mode dropdown per key: plain / scatter-reveal (dwell ms, step-by-button) / short-reveal (secs) / show-once → refuse-or-decoy; decoy severity picker (reset / lockout / silent duress) |
| Rhythm lock | cadence + tolerance; renders a metronome preview |
| Zone-keyed distance ("generator must be far") | map widget: draw the far zone(s) on the *generator's* config, UI auto-creates the zone key and references it from the lock's slot — the cross-device wiring is done by the UI, invisibly |
| Walk-the-path | ordered waypoint list on the map, per-leg deadline fields; drag to reorder |
| Walk-away unlock | concentric ring editor (radii sliders) |
| Two-person / quorum | multi-select from the set roster, M-of-N stepper, "alternating" toggle |
| Dead-man re-arm | beat interval; scary copy about what happens when you miss one |
| Calendar gate | week grid (paint hours), attachable to any slot |
| Stillness / motion gate | quiet-seconds slider; invert checkbox |
| Portable-lock positioning | two map fences: P_unlock, P_lock |
| Duress slot | clone-of-slot picker + silent-flag notice; UI shows its distinct confirm-code stream |
| Receipt chaining | toggle per slot; picks which validator key verifies receipts |
| Backoff/lockout | failure threshold + base delay; graph preview of the curve |

Plus a **ritual simulator**: given a slot's config, the UI renders a timeline
("code at t=0, next accepted 90 s–4 min, all three inside 10 min…") and lets
you scrub through a simulated attempt — the pedantic policies are exactly the
ones people will misconfigure, so dry-run before signing.

Signing UX: "Review & sign" shows the canonical CBOR diff vs the device's
acked config, then signs with the owner key (WebCrypto) and queues per-device
sealed blobs for whichever transport is available.

## Firmware crates (all no_std, verified available)

| Crate | Use |
|---|-----|
| `minicbor` | CBOR encode/decode, zero-alloc |
| `salty` | Ed25519 sign/verify (Cortex-M optimized) |
| `x25519-dalek` | ECDH for COSE_Encrypt0 unseal |
| U083 AES engine | payload cipher (via embassy/PAC), HKDF via existing SHA1-HMAC or add sha2 |

COSE envelopes are small enough to hand-roll with `minicbor` (COSE_Sign1 /
Encrypt0 are ~4-field arrays) — no heavy COSE crate needed.

## Open questions

- Telemetry batching/ack window when the ESP is only powered occasionally
  (how much audit ring to replay; the chain tags make gaps detectable).
- Whether the web UI is a static SPA only (fits the "dumb relay" model) or
  also a small server for fleets — leaning static-first.
- SHA-256 shows up in set_id/HKDF — pull in `sha2` (fine) or reuse SHA-1
  everywhere (avoid; keep SHA-1 confined to the legacy lock link + TOTP).
- Config size budget: a maxed-out slot table with polygon zones should stay
  ≤ 2 KB (one journal page) — enforce in the UI, paginate zones if ever needed.

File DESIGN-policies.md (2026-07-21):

# ephemerkey Unlock Policies — Ideas & Design

Companion to `DESIGN.md`. This covers the *behavioral* layer: what combinations
of codes, places, and timing a lock demands before it acts. Firmware sketch:
`firmware/ephemerkey-rs/src/policy.rs`.

## Personalities

One firmware image, one hardware design, two roles selected by provisioned
config (`firmware/ephemerkey-rs/src/config.rs`):

- **Generator** — the classic ephemerkey: emits TOTP codes only with a valid
  GNSS fix inside (or outside — see zone keys) its authorized geofence.
- **LockController** — receives/validates codes and drives the companion
  ATtiny lock board over the bit-banged LOCK I2C bus. It has the *same* GNSS
  hardware, so it can impose position requirements on **itself** (portable
  locks).

Both are programmed with a signed config **file** delivered over USB
(explicit provisioning mode: button + enumeration) or the WiFi/ESP32-C3 link
(`provision.rs`). The file carries the role, secrets, geofences, and the
**code slot table** below.

## Who can enforce what (the honest part)

A TOTP code is six digits; it carries no location. So:

- A lock can enforce **its own** position (it has GNSS), timing between codes,
  code counts, and code validity.
- A lock **cannot observe the generator's position**. "The generator must be
  ≥5 km away" is enforced one of two ways:
  1. **Generator-side policy** — the generator simply refuses to emit unless
     its own policy (fix + fence + clock freshness) is satisfied. Fine when
     both devices are ours (they are — that's the product).
  2. **Zone-keyed secrets** — the generator holds several TOTP secrets and
     selects one by which of *its* configured zones it currently occupies
     (e.g. `K_home`, `K_far`, `K_transit`). A code proves, cryptographically,
     "a trusted generator, in zone X, at time T." The lock's policy then says
     "I need a `K_far` code," and distance claims stop being honor-system.

Zone-keyed secrets are the primitive that makes most of the pedantic
sequences below real instead of theatrical.

## Code slots

A lock holds up to `N_SLOTS` **parallel, independent code slots**. Each slot
is its own secret (or zone-key set), its own policy state machine, and its own
action. Examples of a slot table:

| Slot | Secret | Policy | Action |
|---|---|---|---|
| 0 | `K_master` | AlwaysValid | unlock |
| 1 | `K_far` | Sequence{n=3, window=10min, gap=90s..240s} | unlock |
| 2 | `K_home` | AlwaysValid | lock |
| 3 | `K_duress` | AlwaysValid | unlock + silent flag |

Semantics:

- Every received code is tried against **every slot** (constant-time compare
  per slot; a code is consumed by at most one slot — first match in priority
  order).
- A code that matches **no** slot is an *invalid code*: it resets the
  sequence state of every slot marked `reset_on_invalid` (default: all).
- Each TOTP counter value is counted **once per slot** — replaying the same
  code twice in one period advances nothing (dedupe by period counter, same
  discipline as the lock board's armed nonce).

## The canonical pedantic sequence (the motivating example)

Lock fixed at the vault; generator must be taken far away. Unlock requires
**N codes within Y minutes**, with **min and max spacing between codes**:

```
policy Sequence {
    key        = K_far          # zone-keyed: generator must be in the "far" zone
    n          = 3              # codes required
    window     = 10 min         # all N must land inside this (arrival)
    gap_min    = 90 s           # too fast -> reset (no code hoarding)
    gap_max    = 4 min          # too slow -> reset (continuous presence)
    delay      = 30..35 min     # walk time: codes valid this long AFTER minting
                                # (0..~30s = instant; see "Time-shifted validity")
    reset_on_invalid = true
    progress   = visible | hidden
}
```

State machine: `Idle --code--> Counting(1) --code(in gap)--> Counting(2) ...
--> Fire`. Any violation (early, late, invalid, window expiry) → `Idle`,
silently or visibly per `progress`. `gap_min` prevents pre-generating a batch
of codes and replaying them in one burst; `gap_max` proves the generator
*stayed* in the far zone for the whole ritual.

**Progress display** is a per-slot flag: show a count on the OLED/LEDs, or
show nothing (an observer can't tell a 2-of-3 state from idle — decoy option:
always display the same idle screen).

## Time-shifted validity (walk time)

The person opening the lock and the holder of the generator are usually the
**same person** — the far zone and the lock may be a 30-minute walk apart. So
a slot can accept codes with a configured **delay window**: a code generated
at T=0 is valid at the lock from `T+delay_min` to `T+delay_max` (e.g.
+30…+35 min) — and, importantly, *not* valid immediately.

Mechanics (all from standard TOTP, no new crypto):

- The lock knows which TOTP counter a code matched, i.e. its **generation
  time** to one period. Delay check: `now - gen_time ∈ [delay_min, delay_max]`.
  The verifier simply searches the counter range
  `[(now-delay_max)/P … (now-delay_min)/P]` instead of "current ± 1".
- With a delay window, sequence **gap timing splits in two**, and both are
  checked:
  - **generation cadence** — spacing between the *counters* of accepted
    codes (`Δcounter × P ∈ [gap_min, gap_max]`): proves the codes were
    minted at the far place at the required rhythm. Immune to arrival
    jitter, and immune to hoarding-then-bursting by construction.
  - **arrival window** — all M codes must still be entered within the
    slot's overall window (and optionally with their own arrival gaps).
- A delayed slot proves "*you were in the far zone at T-30min, M times, at
  the right cadence*" — the person writes the codes down (or remembers them)
  and walks. This is the intended, primary usage of the sequence policy.
- Composition rule: **split-epoch freshness** (catalog #11) is the delay
  window's opposite (`delay = [0, X]`); a slot has exactly one arrival
  window, `[delay_min, delay_max]`, with instant slots being `[0, ~P]`.
- Replay unchanged: each accepted counter burns once per slot; the wider
  counter search only widens brute-force surface, which is countered by code
  length (below) and lockout (#12).

## Code length & display modes (generator side)

**Code length is per-key configurable, 4–10 digits.** RFC 6238 dynamic
truncation yields 31 bits, so entropy saturates just above 9 digits — 10 is
allowed but adds nothing (and its leading digit skews low); the UI says so.
Short codes (4–5 digits) are for low-stakes slots and pair naturally with
strict lockout; delayed/high-stakes slots should use 8+ (a wider delay window
multiplies the guessing surface).

The generator's *display* is itself policy-configurable per key:

- **Scatter reveal (secret mode)** — the code is shown **one digit at a
  time, in its correct position, in random order** (`__3___`, `4_____`, …).
  A shoulder-surfer must capture every frame *and* its position; the owner
  just fills in a mental grid. Config: per-digit dwell time, auto-advance or
  button-step.
- **Short reveal** — correct codes display for a bounded time (e.g. 5 s),
  then blank. Config: reveal seconds.
- **Show-once + refuse** — after one reveal, the generator refuses to show
  another code until the *next legitimate cadence window* (it knows the
  slot's `gap_min`/`gap_max` and counts down to it). Someone who grabs the
  device after you've read your code gets nothing.
- **Show-once + decoy (poison mode)** — stronger: instead of refusing,
  subsequent reveals show a plausible code drawn from a distinct decoy
  secret (`K_decoy`). Entering a decoy at the lock is a **negative match**:
  it's not "invalid noise", it's a definite signal someone squeezed the
  generator for extra codes. Per-slot response: reset, hard lockout, or
  silent duress telemetry. Under coercion, "show me another code" hands the
  attacker a tripwire.

  **Indistinguishability is a hard requirement:** the decoy stream renders
  through the *identical* display pipeline as real codes — same digit count,
  same scatter-reveal order/dwell, same reveal duration, same "next code in
  N s" countdown, same refusal windows. Real and decoy reveals share one
  code path parameterized only by which key they mint from; any observable
  difference (timing, animation, brightness, buzzer) is a side channel that
  defeats poison mode.

Generator-side display/reveal state is RAM-only and per-key, mirroring the
lock's slot config so the countdown UX ("next code in 90 s") matches what
the lock will actually accept.

## Cascading generators (ritual-gated generation)

So far a generator emits a code whenever its **emission gate** is open (valid
fix, inside fence, fresh clock — `gate::may_emit`). That is a *place* gate. A
generator can also sit behind a **ritual** gate: it will not reveal a key's
real code until an unlock ritual has been performed on the device itself, and
reveals a **decoy** (or silently refuses) until then. This makes generators
first-class ritual devices, symmetric with the LockController, and lets them
**cascade**: one device's output feeds the next device's ritual.

**Ritual = entering TOTP codes.** The ritual is not button choreography — it is
dialing in one or more 4–8 digit TOTP codes, exactly the codes a LockController
consumes. So the generator embeds the *same* engine: a `LockEngine`
(`ephemerkey-core::engine`) built from a slot table, validating dialed codes
against any policy in the catalog (a single `AlwaysValid` code, a paced
`Sequence`, a `Quorum`, a `Path`…). Nothing new in the engine — the generator
holds **a `Generator` *and* a `LockEngine`**, and wires the lock's outcome to
the reveal window:

```
dialed code --> LockEngine::enter_code_with(code, now, sensors)
     Fired(unlock)  --> unlocked_until = now + window_s   (real reveals open)
     Fired(duress)  --> unlocked_until = now + window_s, DECOY-ONLY (poison)
     Progress/Gated --> stay locked (no distinct signal — see below)
```

`reveal(idx)` then gates on the ritual window in addition to the place gate.
Real, decoy, and refusal already share one code path in
`ephemerkey-core::reveal` (poison-mode indistinguishability), so the ritual
gate only chooses *which* branch:

| place gate (fix+fence+fresh) | ritual window | REVEAL yields |
|---|---|---|
| open | unlocked | **real code** |
| open | locked | **decoy** if a twin is configured, else **silent refuse** (blank, no tone) |
| open | duress-unlocked | **decoy** (device looks unlocked; only poison flows) |
| closed | — | refuse (no fresh in-fence fix, unchanged) |

A locked REVEAL never emits a "wrong ritual" signal — an error tone or distinct
screen would leak that the ritual failed, defeating poison mode. Decoy if a
decoy secret exists; otherwise a blank no-op.

**The cascade.** A ritual leg is just a TOTP over some secret; make that secret
one that *another device generates* and you have cascading devices:

```
Device A: unlock A (its ritual + fence) --> A reveals a code over K_cascade
Human reads A's display, dials it into B within B's gap window
Device B: that code satisfies a leg of B's ritual --> B unlocks --> B reveals
```

The "ritual" is physically walking the code from A to B; the `Sequence` gap
windows (`gap_min`/`gap_max`) bound how long that walk may take, so a stale
relayed code is rejected by construction. Within-device cascade (key X's ritual
gates key Y) is the identical mechanism pointed at a *local* secret — purely a
config choice. The existing receipt chain (`reveal::ChainSpec` / `feed_chain`,
catalog #10) is the pre-wired **lock→generator** instance of this; ritual-gated
generation generalizes it to any predecessor, generator or lock.

**Duress cascade.** Because `Fired(duress)` opens a decoy-only window, a duress
*ritual code* propagates deniably down a cascade: dial the duress code into A
and every device downstream that keys off A's output now mints only poison,
while looking unlocked to an observer.

### Three-button generator UX

The product generator has **three tactile buttons** and a small display — no
keypad — yet must dial 4–8 digit codes, select among keys, reveal, and enter
provisioning. The buttons are overloaded by *mode*, not multiplied. Naming them
`●` (left), `◆` (center), `■` (right):

**Dialing a code (LOCKED / DIAL mode):**

| Button | Action |
|---|---|
| `●` | current digit −1 (wraps 9→0) |
| `■` | current digit +1 (wraps 0→9) |
| `◆` tap | accept digit → advance to next position |
| `◆` double-tap | backspace (fix a mis-dialed digit) |
| `◆` hold | submit the assembled code to the engine |

Nearest-direction increment means any digit is ≤5 presses; the center button
carries accept / backspace / submit by tap / double / hold. The display shows
the code-so-far with a cursor (`[ 4 _ _ _ _ _ ]`).

**State machine:**

```
SLEEP ──any press──▶ LOCKED / DIAL   [ _ _ _ _ _ _ ]
        (◆ long-hold at boot ──▶ USB provisioning, unchanged)
   submit ─┬─ Progress ─▶ DIAL next code   (display: ✓ n/m, gap countdown)
           ├─ Fired(unlock) ─▶ UNLOCKED (window countdown running)
           ├─ Fired(duress) ─▶ UNLOCKED (decoy-only, indistinguishable)
           └─ Invalid/Gated ─▶ back to DIAL   (no distinct error — silent)

UNLOCKED:  ● prev-key   ■ next-key   ◆ REVEAL selected key
           auto re-lock on window expiry or idle timeout
```

Multi-code rituals reuse the lock's timing gates directly: dial code 1 → submit
→ engine returns `Progress` → the UI shows `✓ 1/3` and counts down the
`gap_min`/`gap_max` window before code 2 is accepted. A cascade leg is where the
human leaves to go generate the next code on another device; the gap window is
sized for that trip.

### What this reuses vs. adds

Reused unchanged: `LockEngine` + the whole policy catalog, `reveal.rs` poison
mode / decoy indistinguishability, the receipt-chain primitive, the emission
gate. New work is small and mostly wiring:

- **core** — the `Generator` gains an optional embedded `LockEngine` and a
  `unlocked_until` window; `reveal()` consults it (real vs. decoy vs. refuse per
  the table). No new policy types.
- **firmware** — a 3-button input task (dial → assemble → `enter_code_with`);
  wire the two currently-unused buttons (only `PA5` is read today).
- **config schema** — let the **Generator** role carry a `slots` ritual table
  plus a reveal `window_s` and a per-key "gated" flag; add encoders to
  `cose.ts` / `ekenv.mjs` and the emulator so the wire format agrees across all
  three producers.
- **emu** — model the dial as CLI commands and the reveal window, so cascades
  are exercised end-to-end (A→B) on host without hardware.

**Implemented** across the stack: the reveal-window gate + `apply_ritual_outcome`
in `ephemerkey-core::reveal`; the schema (`gated` key field 7, `unlock_window_s`
key 9, `crit:["cascade"]`) + `build_ritual` in `ephemerkey-config`; the emulator
`gen unlock` command + `cascade-generator` scenario (in `make demo`); the
`configToCbor` encoders (`cose.ts` + `ekenv.mjs`, auto-injecting the cascade
crit) with a serial-emu round-trip; and the firmware `generator::task` 3-button
dial FSM (SW1/SW2/SW3 = PA5/PA15/PF3) building the ritual engine and gating
reveals. The dial / reveal UI is a shared render model (`ephemerkey-ui`): a
`View` → a 21×4 character `Screen` the firmware blits to the 128×32 SSD1306 OLED
(`display.rs`, ssd1306 + embedded-graphics) and the emulator paints to the
terminal, so the sim shows what the device draws. The bench `hw-aes` build omits
the panel for SRAM headroom (the `oled` cfg). I2C1 is a shared blocking bus
(`embassy-embedded-hal`), so the generator drives both the OLED and the LIS3DH:
`sensors::task` samples the accel and publishes a stillness duration to the
`motion` latch, which the generator ritual's and the lock's stillness gates now
read (the accel threshold is bench-tunable). Remaining hardware bring-up: the
lock's own GNSS fence, and tuning the stillness threshold on real hardware.
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

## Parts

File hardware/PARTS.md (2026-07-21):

# ephemerkey — Parts (BOM source of truth)

Every line resolves to a real KiCad **bundled** symbol + footprint and a JLCPCB
**LCSC** number. 0402 passives throughout; bulk caps 0805. Charge current set for
a ~500 mAh 1S Li-ion (Rprog 4.7 kΩ ≈ 213 mA, ~0.5 C). The schematic is generated
from `scripts/ephemerkey.schgen.py` — **edit that, not the `.kicad_sch` files**.

> JLCPCB Basic vs Extended: the jlcsearch API under-reports the Basic flag, so
> verify in JLCPCB's BOM tool at order time. The common 0402 R/C (Uniohm/Samsung)
> and SOT-23 jellybeans here are Basic; the ICs, crystal, inductor, connectors,
> and LEDs are Extended.

## Actives / modules

| Ref | Value | MPN | LCSC | Footprint |
|-----|---|-----|---|---|
| U1 | STM32U083KCU6 | STM32U083KCU6 | C22459164 | ephemerkey:UFQFPN-32-1EP_5x5mm_P0.5mm_EP3.5x3.5mm (project copy → generic QFN-32 3D model) |
| MD1 | MAX-M10S-00B | MAX-M10S-00B | C4153167 | ephemerkey:ublox_MAX (project copy + vendored 3D model) |
| AE1 | W3011A | W3011A | C5830926 | RF_Antenna:Pulse_W3011 |
| U2 | TPS63900DSKR | TPS63900DSKR | C1518762 | Package_SON:WSON-10-1EP_2.5x2.5mm_P0.5mm_EP1.2x2mm |
| U3 | USBLC6-2SC6 | USBLC6-2SC6 | C2687116 | Package_TO_SOT_SMD:SOT-23-6 |
| U4 | MCP73831-2-OT | MCP73831T-2ACI/OT | C424093 | Package_TO_SOT_SMD:SOT-23-5 |
| U5 | LIS3DHTR | LIS3DHTR | C15134 | Package_LGA:LGA-16_3x3mm_P0.5mm |
| Q1, Q3 | AO3401A (P-FET) | AO3401A | C15127 | Package_TO_SOT_SMD:SOT-23 |
| Q2, Q4 | AO3400A (N-FET) | AO3400A | C20917 | Package_TO_SOT_SMD:SOT-23 |
| D3 | B5819W (Schottky) | B5819W | C8598 | Diode_SMD:D_SOD-123 |
| MD2 | ESP32-C3-MINI-1 (WiFi, optional) | ESP32-C3-MINI-1-N4 | C2838502 | ephemerkey:ESP32-C3-MINI-1 (vendored from espressif/kicad-libraries, w/ 3D model) |
| U6 | AP2112K-3.3 (WiFi LDO, optional) | AP2112K-3.3TRG1 | C51118 | Package_TO_SOT_SMD:SOT-23-5 |
| U7 | M24M02E (2Mbit audit-log EEPROM) | M24M02E-FMC6TG | C29549719 | ephemerkey:ST_UFDFPN8-8-1EP_2x3mm_P0.5mm_EP1.4x1.4mm (vendored; verified vs ST UFDFPN8 outline) |
| U8 | MAX17048 (1S fuel gauge, I2C1 @0x36) | MAX17048G+T10 | C2682616 | Package_DFN_QFN:TDFN-8-1EP_2x2mm_P0.5mm_EP0.8x1.2mm (stdlib; sym `ephemerkey:MAX17048` authored from ADI DS, cross-checked vs notchdeck's — verify EP land vs 21-0168) |

## Frequency / power magnetics

| Ref | Value | MPN | LCSC | Footprint | Note |
|-----|---|-----|---|---|---|
| Y1 | 32.768 kHz | Q13FC13500004 | C32346 | Crystal:Crystal_SMD_3215-2Pin_3.2x1.5mm | RTC LSE; match load caps to CL |
| L1 | 2.2 µH | FNR3015S2R2MT | C167747 | Inductor_SMD:L_Changjiang_FNR3015S | TPS63900 (3×3 mm, small) |
| L2 | FB 600Ω@100MHz | BLM15AG601SN1D | C76884 | Inductor_SMD:L_0402_1005Metric | VCC_RF isolation |

## Connectors / switch / LEDs

| Ref | Value | MPN | LCSC | Footprint |
|-----|---|-----|---|---|
| J3 | USB-C (GCT USB4105) | USB-TYPE-C-019 | C2927039 | Connector_USB:USB_C_Receptacle_GCT_USB4105-xx-A_16P_TopMnt_Horizontal |
| J4 | BAT 1S (JST PH RA) | S2B-PH-K-S | C173752 | Connector_JST:JST_PH_S2B-PH-K_1x02_P2.00mm_Horizontal |
| J1 | SWD | Conn_ARM_SWD_TagConnect_TC2030-NL | — | Connector:Tag-Connect_TC2030-IDC-NL_2x03_P1.27mm_Vertical |
| J2 | LOCK OUT (1x4) | header 2.54 | — | Connector_PinHeader_2.54mm:PinHeader_1x04_P2.54mm_Vertical |
| DS1 | OLED 128x32 I2C (1x4, 0.1") | `Display_Graphic:ER_OLEDM0.91_1x-I2C` | — | 1x4 female socket P2.54 (PinSocket_1x04): GND/VCC/SCL/SDA → I2C1 |
| SW1–SW3 | USER1/2/3 (SW3=BOOT0/DFU) | TS-1187A-B-A-B | C318884 | ephemerkey:SW_Push_1P1T_XKB_TS-1187A (vendored from tsumikoro, has 3D model) |
| D1 | LED green (status) | LTST-C281KGKT | C160479 | LED_SMD:LED_0402_1005Metric |
| D2 / D4 | LED red (fault / charge) | NCD0402R1 | C130719 | LED_SMD:LED_0402_1005Metric |

## 0402 passives (Basic)

| Value | LCSC | Used for |
|---|---|---|
| R 5.1k | C25905 | USB-C CC1/CC2 (R4,R5) |
| R 4.7k | C25900 | Rprog (R6, 213 mA), I²C pull-ups (R9,R10) |
| R 100k | C25741 | load-share gate pulldown (R7), WiFi LDO EN pulldown (R26), +3V3_SW switch (R30 Q3 gate PU, R31 PERI_EN PD) |
| R 10k | C25744 | BOOT0 pulldown (R1), WiFi EN RC + straps (R18–R21) |
| R 1k | C11702 | LED series (R2,R3,R8), WiFi UART series (R22,R23) |
| R 0Ω | C17168 | antenna π-match series (Rm1), TPS63900 CFG2 = I_lim Unlimited (R28), WiFi→MCU recovery links (R24,R25 — DNP) |
| R 36.5k 1% | C25887 | TPS63900 CFG1 = V_O(2) 3.3V (R27) |
| R 16.2k 1% | C27176 | TPS63900 CFG3 = V_O(1) 3.3V, the active preset (R29) |
| C 100nF | C1525 | decoupling (C3,C4,C5,C8,C9,C17,C20,C21,C22,C23,C24,C28,C30) |
| C 1µF | C29266 | VDDA/VREF+ filter (C7), WiFi EN RC (C25), +3V3_SW reservoir (C31) |
| C 12pF | C1547 | LSE load caps (C1,C2) — tune to crystal CL |
| C 10pF | (TBD) | VCC_RF HF bypass (C18) |
| C 10µF 0805 | C15850 | bulk: 3V3, charger, buck-boost, VBUS/VBAT, GNSS VCC (C6,C10–C16,C19), WiFi LDO/module (C26,C27,C29) |
| C DNP | — | antenna π-match shunts (Cm2,Cm3 — fit at bring-up) |

## Notes
- **Rprog → charge current:** I_chg ≈ 1000 V / Rprog. 4.7 kΩ = 213 mA (~0.5 C of
  500 mAh). Use 3.9 kΩ for ~256 mA if faster charging is wanted.
- **LSE load caps:** 12 pF shown; set to ≈2·(CL − C_stray) for the chosen Y1 CL,
  trim residual with the STM32 RTC SMOOTHCALIB.
- **TPS63900 CFG straps (R27–R29):** read once at EN rising by the R2D
  interface — 1% / ≤200 ppm required (TI: total RMS error < 3%), keep CFG
  traces short (< 10 pF), SEL strapped to GND. Both presets 3.3 V, I_lim
  Unlimited (L1 Isat 2 A meets the ≥ 2 A requirement).
- **3 parts need a downloaded 3D model** (STM32U083KCU6, MAX-M10S, W3011A) — see
  `lib/3dmodels/README.md`.
- **WiFi is optional:** MD2 + U6 + R18–R26 + C25–C29 live on `wifi.kicad_sch`
  and can be depopulated as a group. Own LDO rail from VSYS (350mA TX bursts
  never load the TPS63900); off by default (PB5 low, <1µA leak).
- **U7 audit log** (`storage.kicad_sch`): I2C1 @ 0x50–0x53, encrypted +
  HMAC-chained 32B records, ~8000-record ring (2Mbit). Secrets stay in internal
  flash; STM32 OTA images stage in the ESP32's 4MB flash — see DESIGN.md
  "Storage, Logging & OTA".

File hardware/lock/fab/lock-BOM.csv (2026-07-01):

Item | Designator | Comment | Footprint | Qty | LCSC Part # | MPN | Manufacturer
1 | C1,C9,C10 | 100nF | Capacitor_SMD:C_0402_1005Metric | 3 | C1525
2 | C2 | 1uF | Capacitor_SMD:C_0402_1005Metric | 1 | C29266
3 | C3 | 10uF | Capacitor_SMD:C_0805_2012Metric | 1 | C15850
4 | C4,C6 | 22uF | Capacitor_SMD:C_1206_3216Metric | 2 | C12891
5 | C5,C8 | 220uF 25V | Capacitor_SMD:CP_Elec_6.3x7.7 | 2 | C4747974 | RST220UF25V019 | generic
6 | D1 | STAT | LED_SMD:LED_0402_1005Metric | 1 | C160479 | LTST-C281KGKT | Lite-On
7 | D2,D3 | SS34 | Diode_SMD:D_SMA | 2 | C8678 | SS34 | MDD
8 | J2 | I2C JST-PH RA | Connector_JST:JST_PH_S4B-PH-K_1x04_P2.00mm_Horizontal | 1 | C157926 | S4B-PH-K-S | JST
9 | J3 | SOLENOID 12V | Connector_JST:JST_PH_S2B-PH-K_1x02_P2.00mm_Horizontal | 1 | C173752 | S2B-PH-K-S | JST
12 | J6 | HALL DOOR | Connector_JST:JST_PH_S3B-PH-K_1x03_P2.00mm_Horizontal | 1 | C157929 | S3B-PH-K-S | JST
13 | J7 | HALL BOLT | Connector_JST:JST_PH_S3B-PH-K_1x03_P2.00mm_Horizontal | 1 | C157929 | S3B-PH-K-S | JST
15 | L1 | 10uH | Inductor_SMD:L_Changjiang_FNR6045S | 1 | C168076 | FNR6045S100MT | Changjiang
16 | Q1,Q2,Q4,Q5 | AO3400A | Package_TO_SOT_SMD:SOT-23 | 4 | C20917 | AO3400A | AOS
17 | Q3 | AO3401A | Package_TO_SOT_SMD:SOT-23 | 1 | C15127 | AO3401A | AOS
18 | R1,R15,R24 | 1k | Resistor_SMD:R_0402_1005Metric | 3 | C11702
19 | R2,R6,R18,R19,R20 | 100k | Resistor_SMD:R_0402_1005Metric | 5 | C25741
20 | R3 | 200k | Resistor_SMD:R_0402_1005Metric | 1 | C25764
21 | R4 | 22k | Resistor_SMD:R_0402_1005Metric | 1 | C25768
22 | R5 | 100R | Resistor_SMD:R_0402_1005Metric | 1 | C106232
23 | R13 | 0R | Resistor_SMD:R_0402_1005Metric | 1 | C17168
24 | R16,R21,R22,R23,R25 | 10k | Resistor_SMD:R_0402_1005Metric | 5 | C25744
25 | R17 | 20k | Resistor_SMD:R_0402_1005Metric | 1 | C25765
26 | U1 | ATtiny1616 | Package_DFN_QFN:VQFN-20-1EP_3x3mm_P0.4mm_EP1.7x1.7mm | 1 | C507118 | ATTINY1616-MNR | Microchip
27 | U2 | MT3608 | Package_TO_SOT_SMD:SOT-23-6 | 1 | C84817 | MT3608 | Aerosemi

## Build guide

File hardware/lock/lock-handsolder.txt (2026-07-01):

# Designators assembled by hand (NOT by JLCPCB) — excluded from the assembly
# BOM + CPL so the two match. One per line; '#' comments allowed.
#
# The pin headers have no LCSC part and are fitted by hand:
J4   # UPDI programming header (1x3)
J5   # servo output 1 (1x3)
J8   # servo output 2 (1x3)
#
# The JST connectors (J2 I2C, J3 solenoid, J6/J7 hall) DO have LCSC numbers and
# are left in the package for JLCPCB THT assembly — do not list them here.

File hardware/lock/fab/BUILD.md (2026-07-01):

# lock — fab package snapshot

A captured copy of the JLCPCB manufacturing outputs so we have a record of
*exactly* what was generated. The live build dir (`hardware/lock/jlcpcb/`) is
gitignored/regenerable; this `fab/` folder is the committed snapshot.

## Provenance
- **Source commit:** `92903b9` (schematic `mcu.kicad_sch` with U1 LCSC restored +
  repoured `lock.kicad_pcb` with clearances cleared).
- **Built with:** `make jlc-lock` → `scripts/jlcpcb-package.sh` (KiCad 10 `kicad-cli`).
- **Date:** 2026-06-30.
- **Board:** 2-layer, 1.6 mm, ~64 × 23 mm. Design rules = JLCPCB 2-layer.

## Contents
| File | What |
|---|---|
| `gerbers/*.gtl/.gbl/.gts/.gbs/.gto/.gbo/.gtp/.gbp` | copper / mask / silk / paste (F+B) |
| `gerbers/lock-Edge_Cuts.gm1` | board outline |
| `gerbers/lock.drl`, `lock-drl_map.gbr` | merged Excellon drill + map |
| `gerbers/lock-job.gbrjob` | Gerber job file |
| `lock-BOM.csv` | assembly BOM (Designator, Value, Footprint, Qty, LCSC, MPN, Mfr) |
| `lock-CPL.csv` | component placement (pick-and-place) |
| `lock-jlcpcb.zip` | the upload bundle (gerbers + drill + BOM + CPL) |

Upload the zip to <https://cart.jlcpcb.com/quote>, enable PCB Assembly, attach
BOM + CPL.

## BOM/CPL format (JLCPCB match)
- BOM lists every designator **individually** (`--ref-range-delimiter ''`) — JLCPCB
  can't expand ranges like `R18-R20`, which would silently drop those SMD parts.
- CPL is **DNP-excluded** (`--exclude-dnp`) and drops mounting holes (H*) + the
  hand-solder list; the BOM applies the same hand-solder exclusion. **BOM and CPL
  now match exactly (42 = 42 parts, no diffs)** — no JLCPCB part-mismatch warnings.

## Assembly plan (JLCPCB **Standard** tier)
- **JLC-assembled (SMD + THT):** all SMD, plus the **JST connectors** J2 (I2C),
  J3 (solenoid), J6/J7 (hall) — they carry LCSC and are placed via **THT assembly**.
- **Hand-soldered (excluded from BOM+CPL):** the 1×3 pin headers **J4** (UPDI),
  **J5 / J8** (servo) — no LCSC. Listed in `hardware/lock/lock-handsolder.txt`.
- **Assembly tier — Economic worked (confirmed on an actual order).** JLCPCB
  **Economic** assembly accepted the whole board, **including the through-hole JST
  connectors** J2/J3/J6/J7 — so THT did *not* force the Standard tier here, contrary
  to the old "Economic is SMD-only" assumption. Only the hand-soldered pin headers
  (J4/J5/J8) sit outside JLC assembly.
  - **C5 / C8 — 220 µF 25 V uses `C4747974` (RST220UF25V019)**, which is
    Economic-eligible (swapped from `C2918361`, which was not — same D6.3×L7.7 mm
    body). With that swap, the full BOM assembles on Economic.

## State at capture — READ BEFORE ORDERING
This is a **working snapshot, not a signed-off release.** Known-open items:

- **DRC:** 0 unconnected, 0 schematic-parity. **3 starved-thermal** on the
  through-hole GND pins of **J6/J7** (hall connectors) — mild (pads still connect
  to GND); fix by setting those pads to solid zone connection or widening the
  thermal spoke.
- **THT rotation:** verify the JST connector rotations in the CPL against JLCPCB's
  convention at review (JST/THT parts sometimes need a rotation offset).
- **ERC (schematic hygiene, does not affect these outputs):** no-connect flags
  still needed on PA3/PB5/PC0–PC2; PWR_FLAGs on VCC + GND.

## DNP (not assembled) / hand-solder
- **DNP** (excluded from BOM+CPL): `R14` (VSERVO source alt), `R9` + `C7` (drain snubber).
- **Hand-solder** (excluded from BOM+CPL, fitted by hand): `J4`, `J5`, `J8`.

## Regenerate
`cd hardware && make jlc-lock` → rebuilds `hardware/lock/jlcpcb/` + the zip, then
copy over this `fab/` folder to re-capture.

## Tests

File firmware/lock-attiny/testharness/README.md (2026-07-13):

# Lock I²C test harness (RedBoard bridge)

Drive the ATtiny1616 lock's authenticated I²C protocol from the host, without
the STM32 master. A SparkFun RedBoard (ATmega328P) runs a serial↔I²C-master
bridge; `lock_test.py` speaks the NONCE/COMMAND/STATUS protocol over it.

## Build & flash the bridge

```sh
make flash                      # /dev/ttyUSB1, Optiboot @ 115200
# older bootloader? make flash PROG_BAUD=57600
```

## Wiring  ⚠️ level safety

The RedBoard is 5 V, the lock runs at ~Vbat (≈3.3 V). I²C is open-drain and the
bridge **only pulls low** (internal pull-ups disabled), so this is safe **iff**:

| RedBoard | Lock (J2) | notes |
|---|---|---|
| A4 (SDA) | SDA / PB1 (J2.3) | |
| A5 (SCL) | SCL / PB0 (J2.4) | |
| GND | GND (J2.1) | **common ground required** (also with the UPDI adapter) |

- Bus **pull-ups (≈4.7 kΩ) go to the LOCK's Vdd, NOT the RedBoard 5 V.** If the
  lock board already has I²C pull-ups to its Vdd, add none.
- **Do not** wire RedBoard 5 V to the lock.
- The lock must be powered (its own cell or the UPDI adapter's Vtarget).

## Run the protocol (authenticated, over the I2C bridge)

```sh
uv run --with pyserial lock_test.py status                 # door/bolt/status bits
uv run --with pyserial lock_test.py nonce                  # arm + print a nonce
uv run --with pyserial lock_test.py unlock                 # NONCE -> HMAC -> COMMAND -> poll
uv run --with pyserial lock_test.py lock
uv run --with pyserial lock_test.py abort                  # emergency stop (everything off)
uv run --with pyserial lock_test.py getconfig
uv run --with pyserial lock_test.py setconfig \            # authenticated (config secret)
    --servo-boost 1 \
    --unlock "s1=2500,s2=2500,dur=550 sol,dur=10000,eoff=door-" \
    --lock   "s1=500,s2=500,dur=550"
```

If you provision non-default secrets (below), pass them to the I2C actions too:
`--pairing-secret <16B ASCII|32 hex>` / `--config-secret ...`.

## Provision config + keys over UPDI (the debug probe, no I2C/auth)

Writes straight to the chip via `pymcuprog` on the UPDI adapter (`/dev/ttyUSB0`)
— for factory/first provisioning before any secret exists. Config → EEPROM,
keys → USERROW (pairing `[0:16]`, config `[16:32]`). Needs `pymcuprog`
(`uv tool install pymcuprog`, or pass `--pymcuprog "uvx pymcuprog"`).

```sh
# keys: default DEV secrets, explicit, or random (prints them — record for the master)
uv run --with pyserial lock_test.py provision-keys
uv run --with pyserial lock_test.py provision-keys \
    --pairing-secret 00112233445566778899aabbccddeeff --config-secret <32hex>
uv run --with pyserial lock_test.py provision-keys --random

# config straight to EEPROM (same knobs as setconfig)
uv run --with pyserial lock_test.py provision-config --servo1 1 --solenoid 1 --hold-ms 10000

uv run --with pyserial lock_test.py provision-all --random   # keys + config in one go
```

USERROW keys survive a chip erase; the EEPROM config does not — re-provision
config after any `--erase` reflash. Once USERROW holds a real secret, set UPDI
lockbits in production.

The lock NACKs its first transaction after waking from power-down, so every op
is retried. The DEV secret in `lock_test.py` matches `src/secret.c` while
USERROW is blank.

## Bridge serial protocol (all hex, one response line each)

```
W <addr> <b0> <b1> ...   -> OK | ERR <tw_status>
R <addr> <n>             -> D <b0> <b1> ... | ERR <tw_status>
L                        -> L SDA=<0|1> SCL=<0|1>   (raw bus line levels)
```
`ERR FF` = bus timeout (nothing responding / no pull-ups). `ERR 48`/`20` =
address NACK (expected on the lock's first post-wake transaction). `ERR 00` =
TWI bus error — an illegal START/STOP seen on the wire (electrical glitch, see
below). The bridge **fully re-inits its TWI on every error**, so one glitch
cannot latch it.

## ⚠️ Bus transients during actuation (bench finding, July 2026)

Soak-testing (`soak.py`) showed **bursts of bus errors on every actuation**:
3–5 failed transactions (`ERR 00` bus error / `ERR 20` NACK / timeouts) in the
~0.4 s window where the MT3608 boost soft-starts into two stalled servos at
6 V. The solenoid phases produce none — it is the boost-under-stall switching
transient coupling into SDA/SCL, **not** a firmware fault (the lock's engine
and TWI target stay healthy throughout).

The original "lock goes deaf" wedge was the **ATmega328 TWI master latching**
after one such bus error and failing every subsequent START — which looks
identical, from the host, to the target dying. Recovery attempts confounded
this for days: every new `lock_test.py` invocation DTR-resets the RedBoard,
silently un-latching the bridge while we credited the target reset.

Caveats and requirements that follow:

- **This bench exaggerates transients**: flying jumpers, one thin shared
  ground lead carrying servo/boost return current, and dev-board wiring. A
  real installation (short traces, solid ground, local decoupling) should be
  much quieter — but do not count on zero glitches.
- **Any I²C master talking to the lock during actuation MUST be robust**: on
  bus error / arbitration-lost / NACK, re-init the peripheral (or run a
  bus-clear: 9 SCL toggles), back off, retry. This applies to the real
  **STM32 master** — its I²C driver needs explicit bus-error recovery, not
  just a retry loop. Polling STATUS during a cycle is safe *only* with that
  in place.
- `soak.py` is the regression test: repeated lock/unlock pairs, aggressive
  polling, one serial session (no hidden DTR resets), per-error `L` line
  states, and a wedge-attribution ladder (in-session retry → bridge-only
  reset → target). Baseline: 40 pairs, ~250 transient errors, zero wedges.

```sh
uv run --with pyserial python3 soak.py /dev/ttyUSB1 40
```

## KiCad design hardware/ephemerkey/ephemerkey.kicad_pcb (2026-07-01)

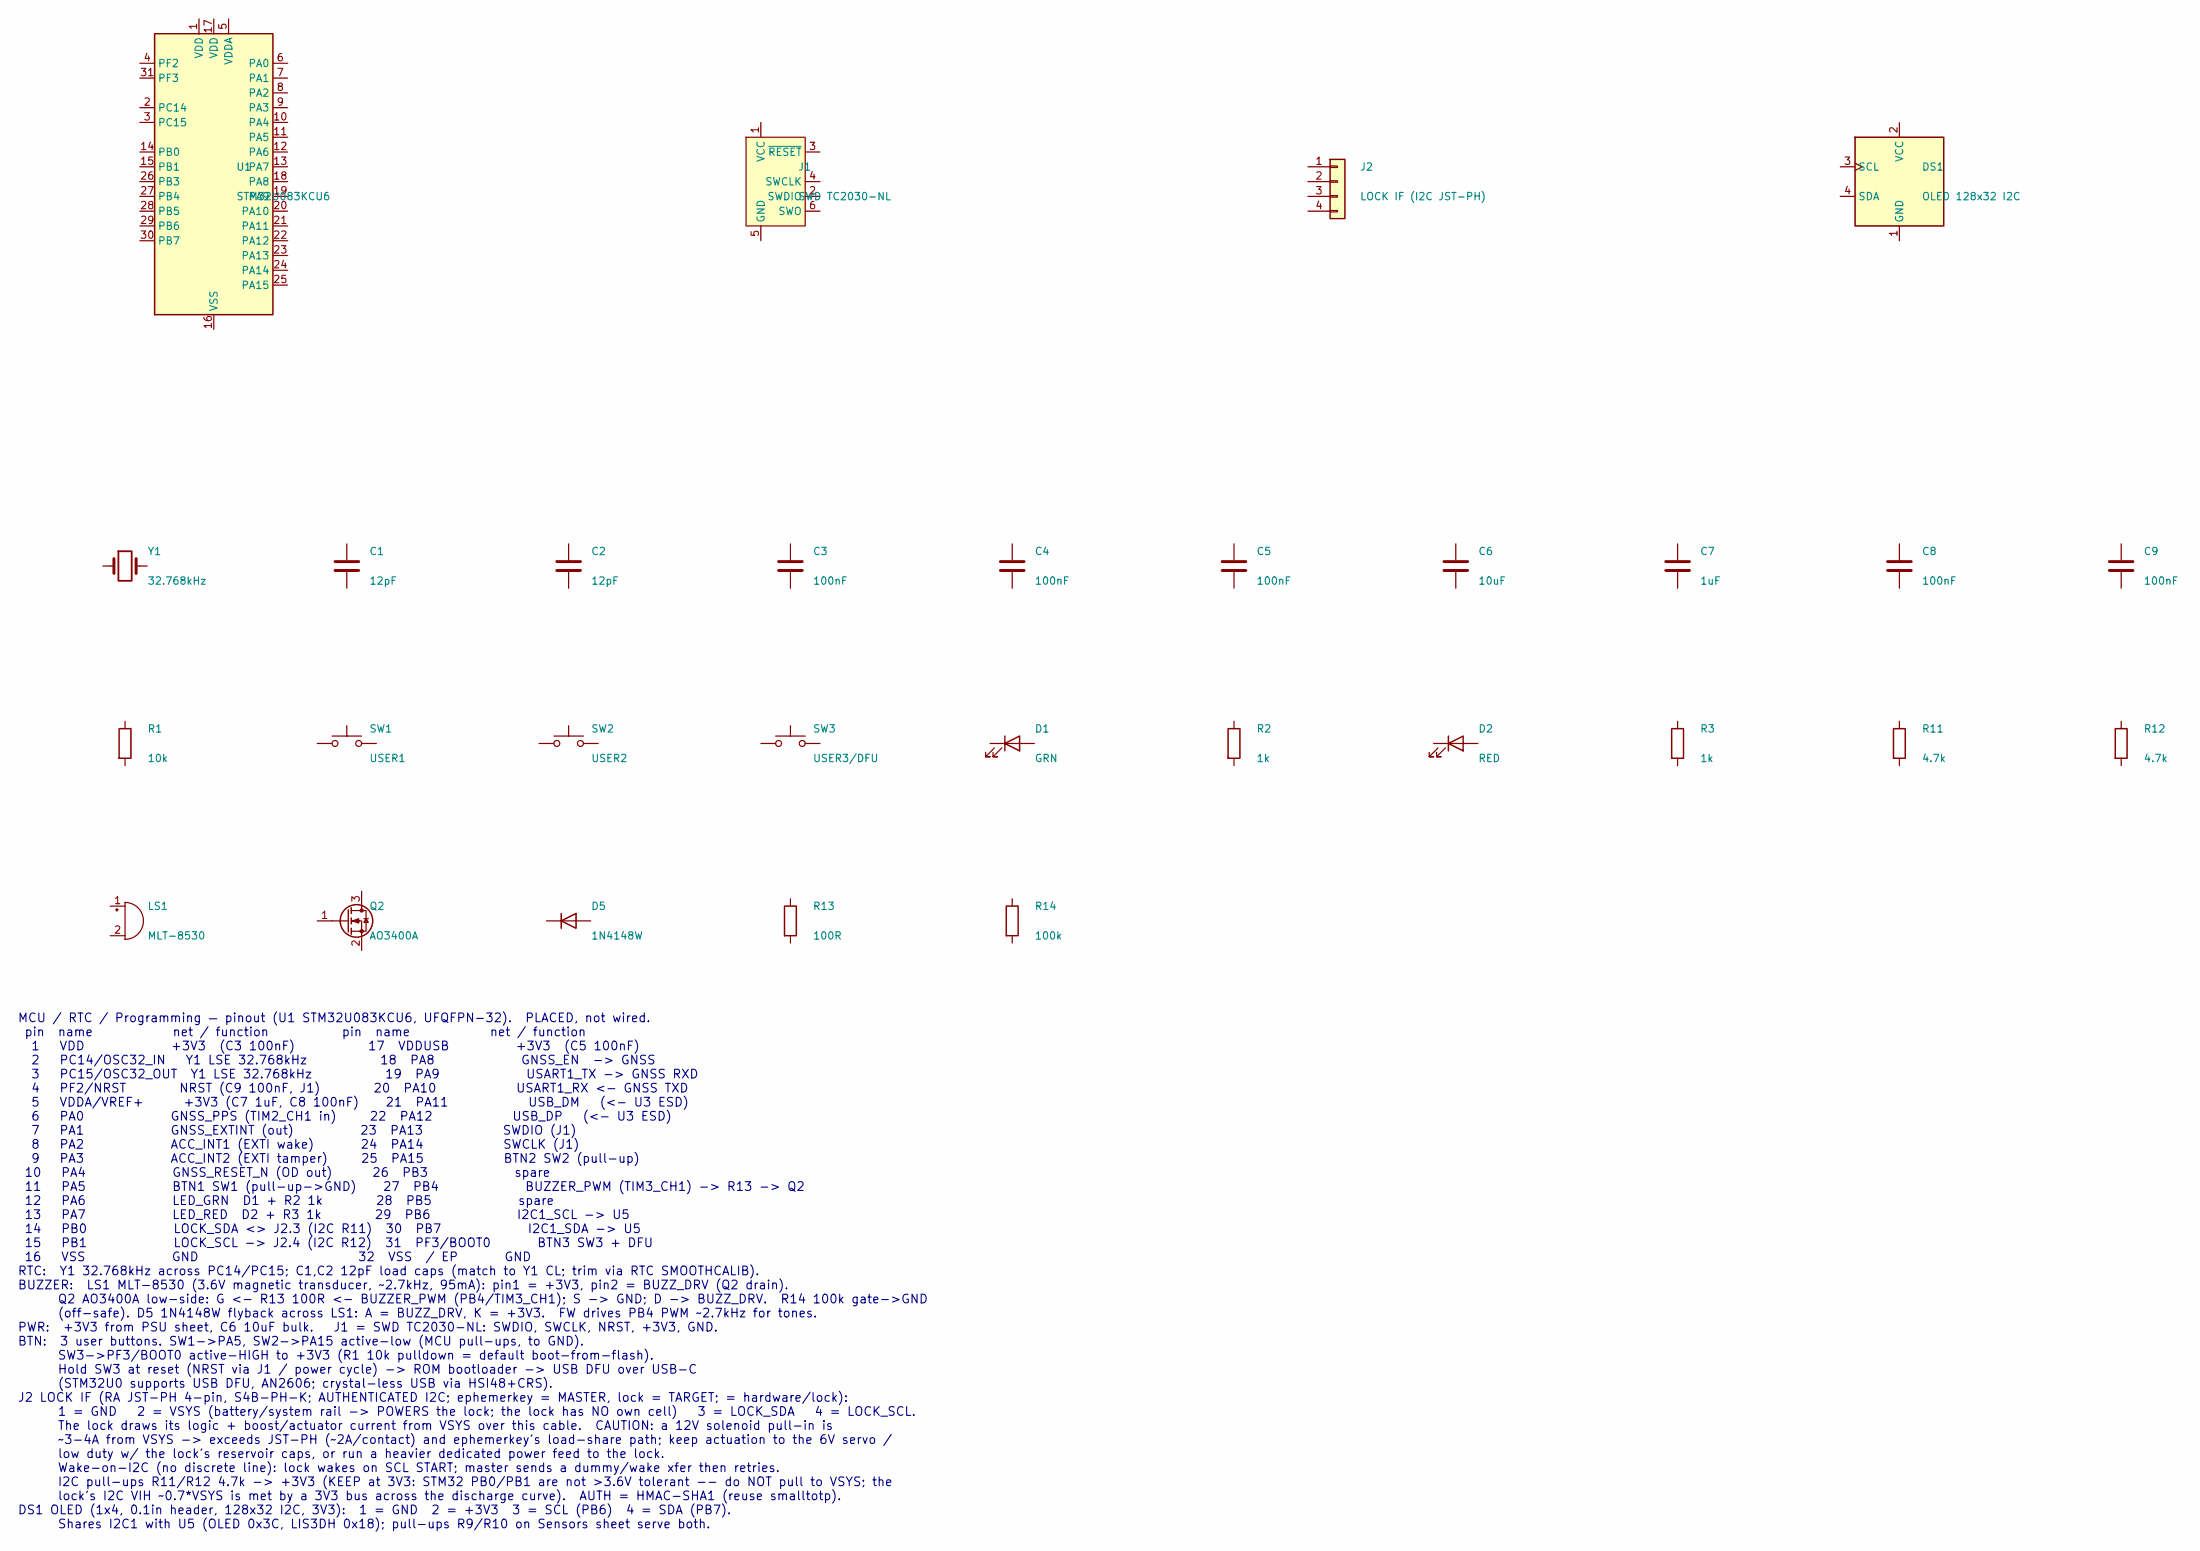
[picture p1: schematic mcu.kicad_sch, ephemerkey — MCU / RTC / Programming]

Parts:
C1, C2: 12pF; C_0402_1005Metric; LCSC C1547
C3, C4, C5, C8, C9: 100nF; C_0402_1005Metric; LCSC C1525
C6: 10uF; C_0805_2012Metric; LCSC C15850
C7: 1uF; C_0402_1005Metric; LCSC C29266
D1: GRN; LED_0402_1005Metric; MPN LTST-C281KGKT; LCSC C160479
D2: RED; LED_0402_1005Metric; MPN NCD0402R1; LCSC C130719
D5: 1N4148W; D_SOD-123; MPN 1N4148W; LCSC C81598
DS1: OLED 128x32 I2C; PinSocket_1x04_P2.54mm_Vertical
J1: SWD TC2030-NL; Tag-Connect_TC2030-IDC-NL_2x03_P1.27mm_Vertical
J2: LOCK IF (I2C JST-PH); JST_PH_S4B-PH-K_1x04_P2.00mm_Horizontal; MPN S4B-PH-K-S; LCSC C157926
LS1: MLT-8530; MagneticBuzzer_CUI_CMT-8504-100-SMT; MPN MLT-8530; LCSC C94599
Q2: AO3400A; SOT-23; MPN AO3400A; LCSC C20917
R1: 10k; R_0402_1005Metric; LCSC C25744
R2, R3: 1k; R_0402_1005Metric; LCSC C11702
R11, R12: 4.7k; R_0402_1005Metric; LCSC C25900
R13: 100R; R_0402_1005Metric; LCSC C106232
R14: 100k; R_0402_1005Metric; LCSC C25741
SW1: USER1; SW_Push_1P1T_XKB_TS-1187A; MPN TS-1187A-B-A-B; LCSC C318884
SW2: USER2; SW_Push_1P1T_XKB_TS-1187A; MPN TS-1187A-B-A-B; LCSC C318884
SW3: USER3/DFU; SW_Push_1P1T_XKB_TS-1187A; MPN TS-1187A-B-A-B; LCSC C318884
U1: STM32U083KCU6; UFQFPN-32-1EP_5x5mm_P0.5mm_EP3.5x3.5mm; MPN STM32U083KCU6; LCSC C22459164
Y1: 32.768kHz; Crystal_SMD_3215-2Pin_3.2x1.5mm; MPN Q13FC13500004; LCSC C32346

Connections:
unnamed: U1.16 (VSS), U1.32 (VSS), U1.33 (VSS)

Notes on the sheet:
MCU / RTC / Programming — pinout (U1 STM32U083KCU6, UFQFPN-32). PLACED, not wired. pin name net / function pin name net / function 1 VDD +3V3 (C3 100nF) 17 VDDUSB +3V3 (C5 100nF) 2 PC14/OSC32_IN Y1 LSE 32.768kHz 18 PA8 GNSS_EN -> GNSS 3 PC15/OSC32_OUT Y1 LSE 32.768kHz 19 PA9 USART1_TX -> GNSS RXD 4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

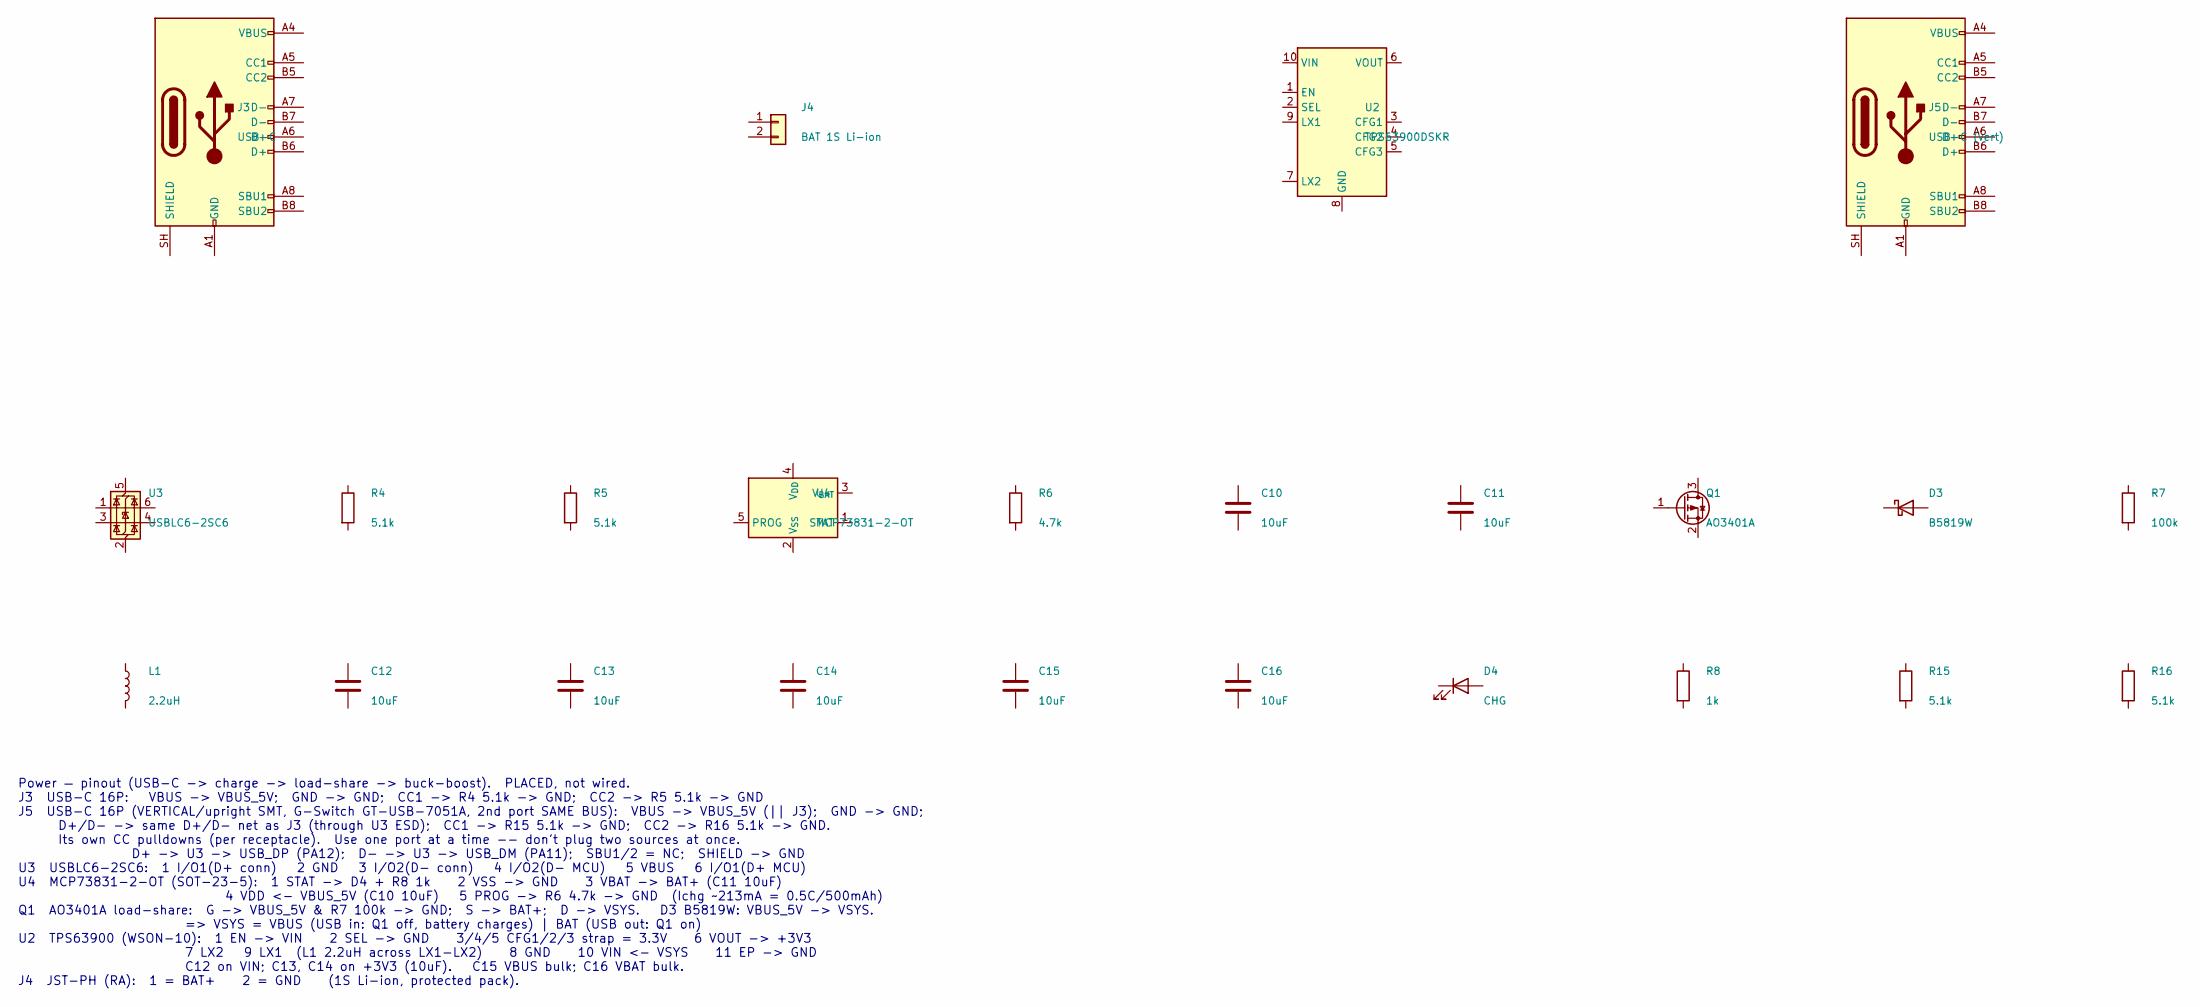
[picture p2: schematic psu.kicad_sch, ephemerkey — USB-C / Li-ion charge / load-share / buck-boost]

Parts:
C10, C11, C12, C13, C14, C15, C16: 10uF; C_0805_2012Metric; LCSC C15850
D3: B5819W; D_SOD-123; MPN B5819W; LCSC C8598
D4: CHG; LED_0402_1005Metric; MPN NCD0402R1; LCSC C130719
J3: USB-C; USB_C_Receptacle_GCT_USB4105-xx-A_16P_TopMnt_Horizontal; MPN USB-TYPE-C-019; LCSC C2927039
J4: BAT 1S Li-ion; JST_PH_S2B-PH-K_1x02_P2.00mm_Horizontal; MPN S2B-PH-K-S; LCSC C173752
J5: USB-C (vert); USB_C_Receptacle_G-Switch_GT-USB-7051x; MPN GT-USB-7051A; LCSC C2843970
L1: 2.2uH; L_Changjiang_FNR3015S; MPN FNR3015S2R2MT; LCSC C167747
Q1: AO3401A; SOT-23; MPN AO3401A; LCSC C15127
R4, R5, R15, R16: 5.1k; R_0402_1005Metric; LCSC C25905
R6: 4.7k; R_0402_1005Metric; LCSC C25900
R7: 100k; R_0402_1005Metric; LCSC C25741
R8: 1k; R_0402_1005Metric; LCSC C11702
U2: TPS63900DSKR; WSON-10-1EP_2.5x2.5mm_P0.5mm_EP1.2x2mm; MPN TPS63900DSKR; LCSC C1518762
U3: USBLC6-2SC6; SOT-23-6; MPN USBLC6-2SC6; LCSC C2687116
U4: MCP73831-2-OT; SOT-23-5; MPN MCP73831T-2ACI/OT; LCSC C424093

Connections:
unnamed: J3.A1 (GND), J3.A12 (GND), J3.B1 (GND), J3.B12 (GND)
unnamed: J3.A4 (VBUS), J3.A9 (VBUS), J3.B4 (VBUS), J3.B9 (VBUS)
unnamed: J5.A1 (GND), J5.A12 (GND), J5.B1 (GND), J5.B12 (GND)
unnamed: J5.A4 (VBUS), J5.A9 (VBUS), J5.B4 (VBUS), J5.B9 (VBUS)
unnamed: U2.8 (GND), U2.11 (GND)

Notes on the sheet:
Power — pinout (USB-C -> charge -> load-share -> buck-boost). PLACED, not wired. J3 USB-C 16P: VBUS -> VBUS_5V; GND -> GND; CC1 -> R4 5.1k -> GND; CC2 -> R5 5.1k -> GND J5 USB-C 16P (VERTICAL/upright SMT, G-Switch GT-USB-7051A, 2nd port SAME BUS): VBUS -> VBUS_5V (|| J3); GND -> GND; D+/D- -> same 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

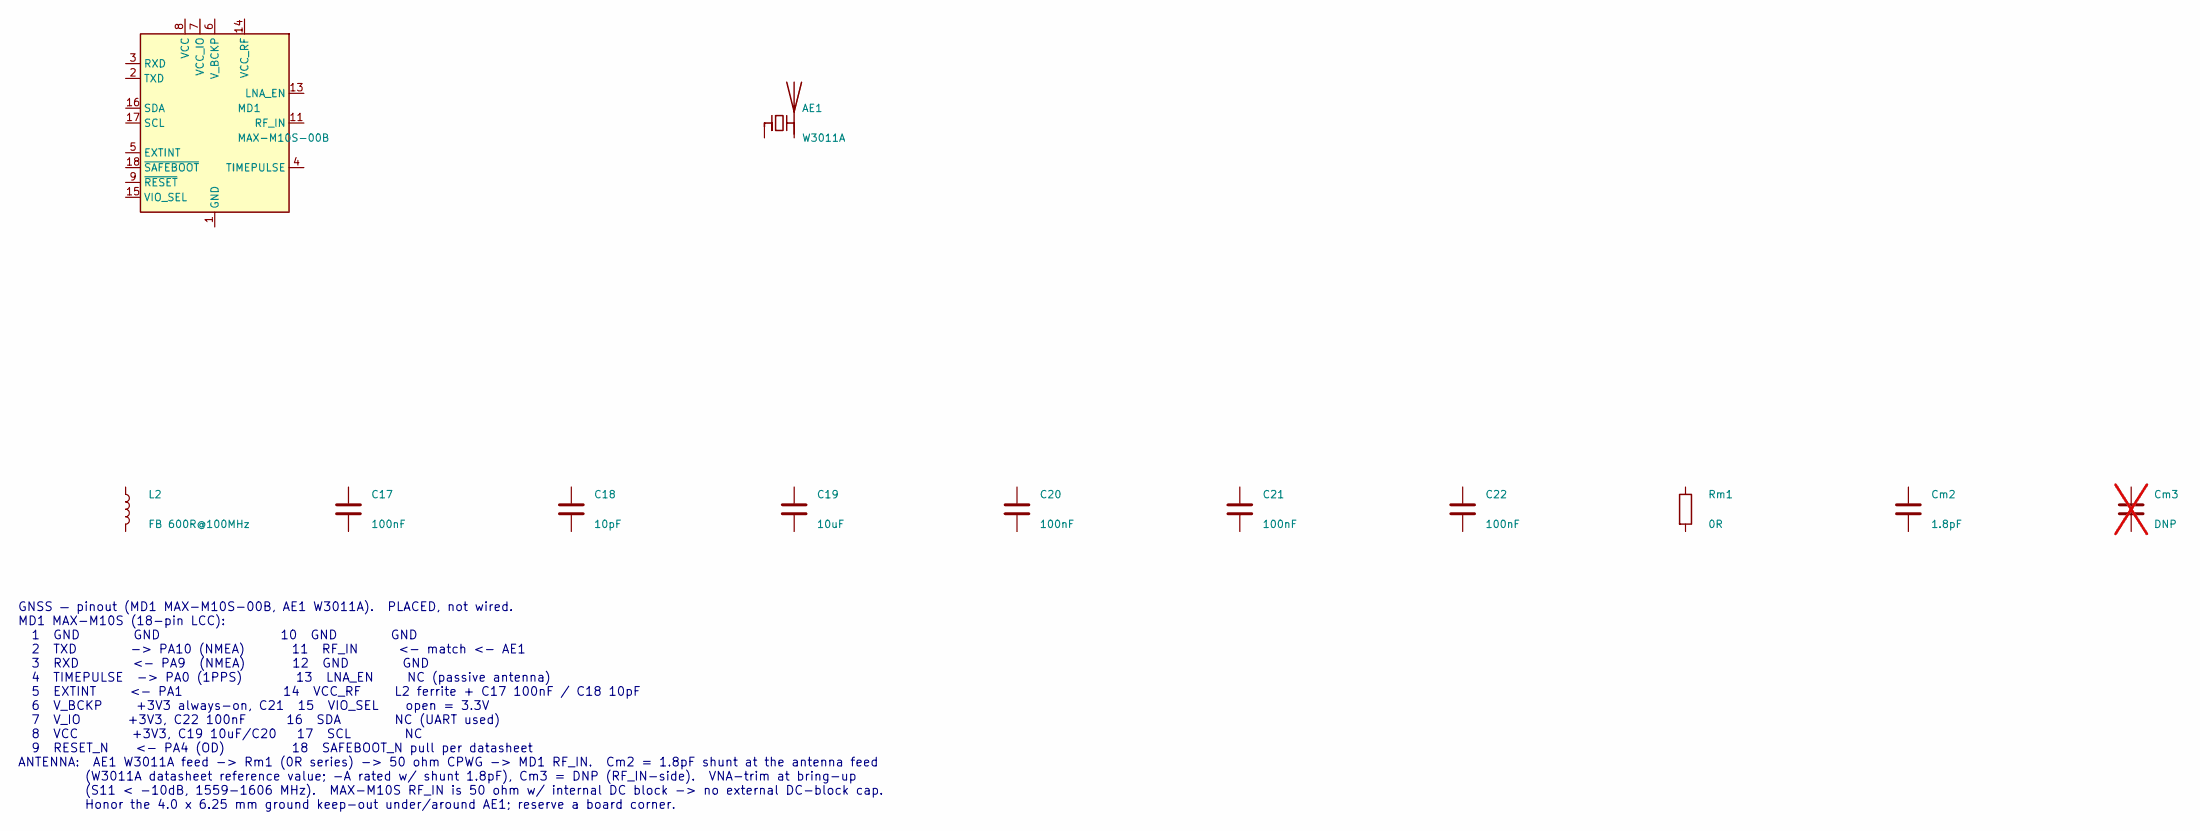
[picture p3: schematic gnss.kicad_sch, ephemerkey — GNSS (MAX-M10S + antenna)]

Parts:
AE1: W3011A; Pulse_W3011; MPN W3011A; LCSC C5830926
C17, C20, C21, C22: 100nF; C_0402_1005Metric; LCSC C1525
C18: 10pF; C_0402_1005Metric
C19: 10uF; C_0805_2012Metric; LCSC C15850
Cm2: 1.8pF; C_0402_1005Metric; LCSC C1549
Cm3: DNP; C_0402_1005Metric; not fitted
L2: FB 600R@100MHz; L_0402_1005Metric; MPN BLM15AG601SN1D; LCSC C76884
MD1: MAX-M10S-00B; ublox_MAX; MPN MAX-M10S-00B; LCSC C4153167
Rm1: 0R; R_0402_1005Metric; LCSC C17168

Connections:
unnamed: MD1.1 (GND), MD1.10 (GND), MD1.12 (GND)

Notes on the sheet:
GNSS — pinout (MD1 MAX-M10S-00B, AE1 W3011A). PLACED, not wired. MD1 MAX-M10S (18-pin LCC): 1 GND GND 10 GND GND 2 TXD -> PA10 (NMEA) 11 RF_IN <- match <- AE1 3 RXD <- PA9 (NMEA) 12 GND GND 4 TIMEPULSE -> PA0 (1PPS) 13 LNA_EN NC (passive antenna) 5 EXTINT <- PA1 14 VCC_RF L2 ferrite + C17 100nF / C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

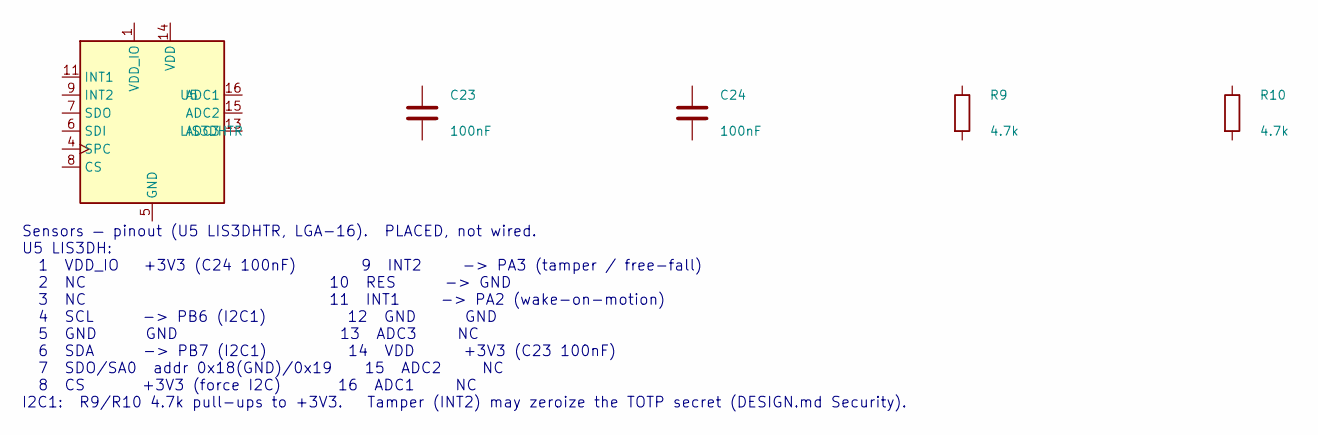
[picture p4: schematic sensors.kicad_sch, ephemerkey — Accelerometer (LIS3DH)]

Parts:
C23, C24: 100nF; C_0402_1005Metric; LCSC C1525
R9, R10: 4.7k; R_0402_1005Metric; LCSC C25900
U5: LIS3DHTR; LGA-16_3x3mm_P0.5mm; MPN LIS3DHTR; LCSC C15134

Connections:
unnamed: U5.5 (GND), U5.10 (GND), U5.12 (GND)

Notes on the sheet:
Sensors — pinout (U5 LIS3DHTR, LGA-16). PLACED, not wired. U5 LIS3DH: 1 VDD_IO +3V3 (C24 100nF) 9 INT2 -> PA3 (tamper / free-fall) 2 NC 10 RES -> GND 3 NC 11 INT1 -> PA2 (wake-on-motion) 4 SCL -> PB6 (I2C1) 12 GND GND 5 GND GND 13 ADC3 NC 6 SDA -> PB7 (I2C1) 14 VDD +3V3 (C23 100nF) 7 SDO/SA0 addr 0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

Board: 2 copper layers, 70 parts (0 on the bottom side), 8 nets, no tracks yet.

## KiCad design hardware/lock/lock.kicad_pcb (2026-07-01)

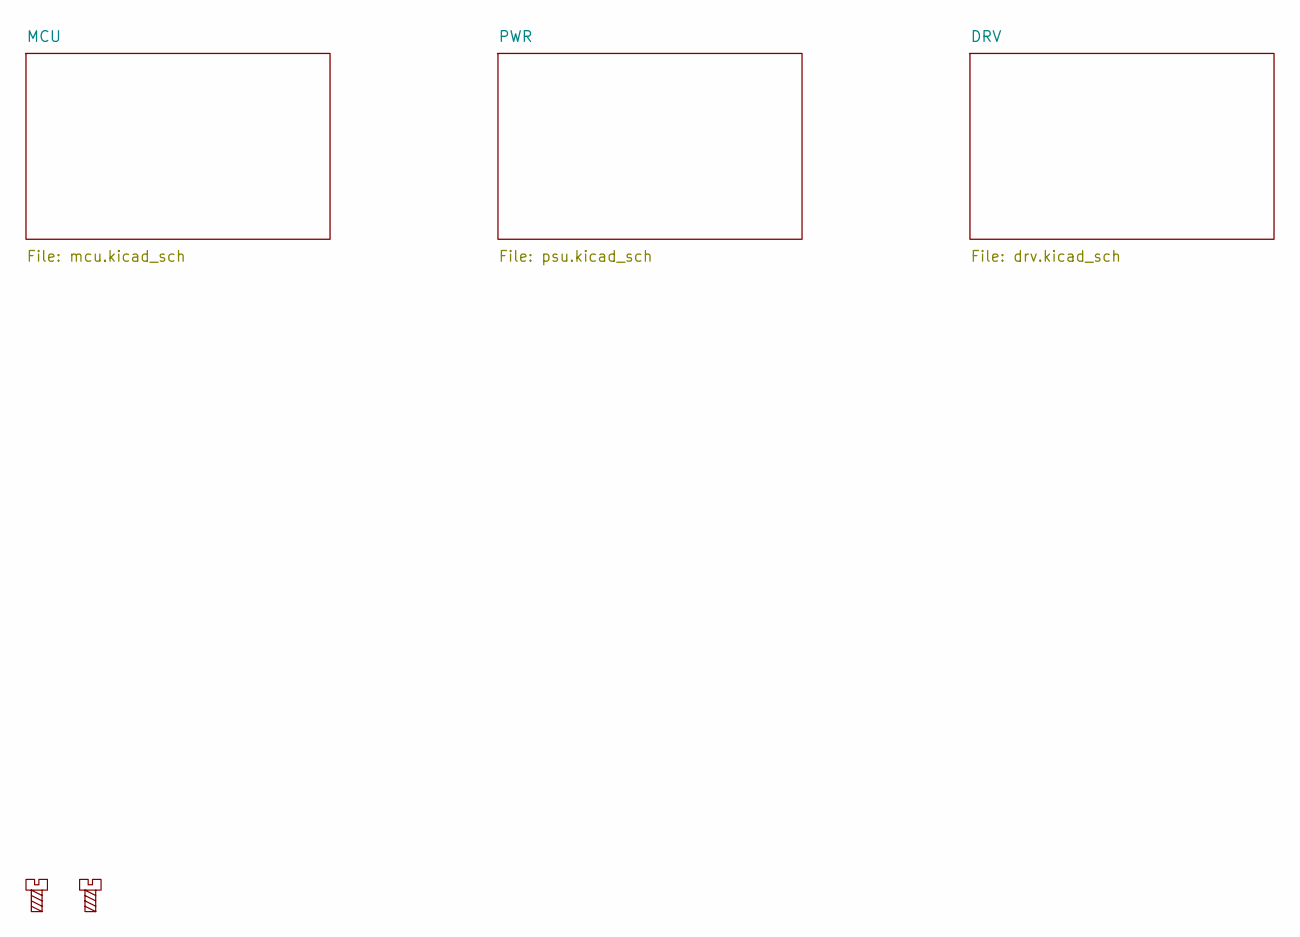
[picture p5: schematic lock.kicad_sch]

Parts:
H2, H3: MountingScrew; MountingHole_3.2mm_M3_Pad_TopBottom

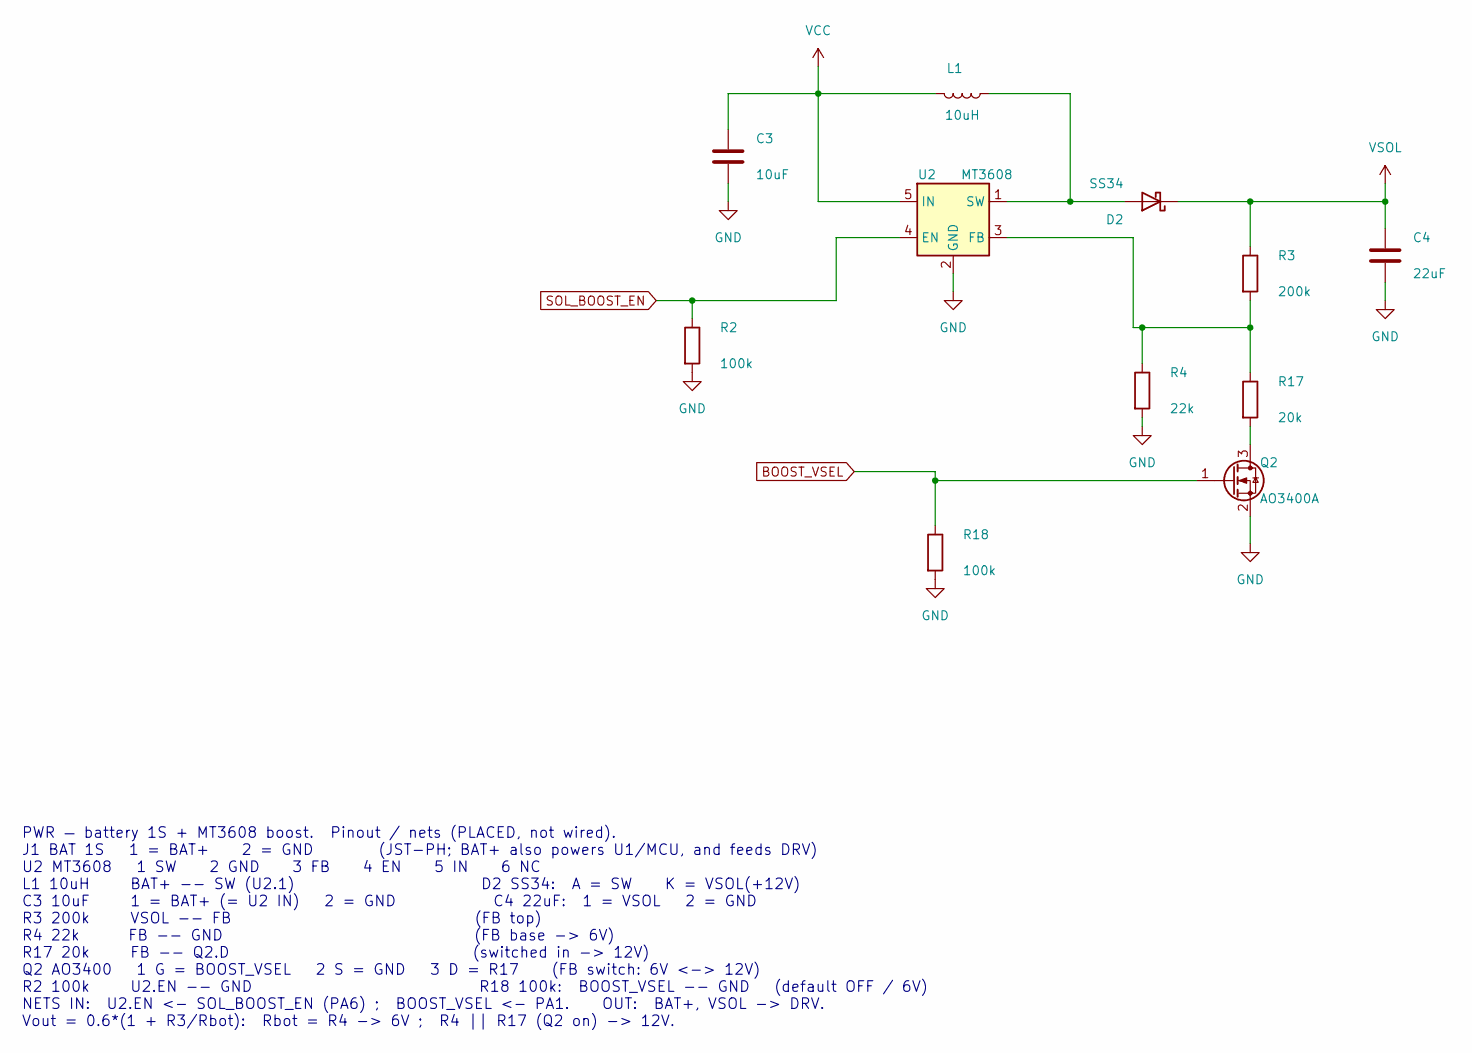
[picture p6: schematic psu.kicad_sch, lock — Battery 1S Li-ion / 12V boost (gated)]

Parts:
C3: 10uF; C_0805_2012Metric; LCSC C15850
C4: 22uF; C_1206_3216Metric; LCSC C12891
D2: SS34; D_SMA; MPN SS34; LCSC C8678
L1: 10uH; L_Changjiang_FNR6045S; MPN FNR6045S100MT; LCSC C168076
Q2: AO3400A; SOT-23; MPN AO3400A; LCSC C20917
R2, R18: 100k; R_0402_1005Metric; LCSC C25741
R3: 200k; R_0402_1005Metric; LCSC C25764
R4: 22k; R_0402_1005Metric; LCSC C25768
R17: 20k; R_0402_1005Metric; LCSC C25765
U2: MT3608; SOT-23-6; MPN MT3608; LCSC C84817

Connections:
BOOST_VSEL: Q2.1 (G), R18.1; also elsewhere on the board
GND: C3.2, C4.2, Q2.2 (S), R2.2, R4.2, R18.2, U2.2 (GND); also elsewhere on the board
unnamed: D2.2 (A), L1.1, U2.1 (SW)
unnamed: Q2.3 (D), R17.2
unnamed: R3.2, R4.1, R17.1, U2.3 (FB)
SOL_BOOST_EN: R2.1, U2.4 (EN); also elsewhere on the board
VCC: C3.1, L1.2, U2.5 (IN); also elsewhere on the board
VSOL: C4.1, D2.1 (K), R3.1; also elsewhere on the board

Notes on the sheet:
PWR — battery 1S + MT3608 boost. Pinout / nets (PLACED, not wired). J1 BAT 1S 1 = BAT+ 2 = GND (JST-PH; BAT+ also powers U1/MCU, and feeds DRV) U2 MT3608 1 SW 2 GND 3 FB 4 EN 5 IN 6 NC L1 10uH BAT+ -- SW (U2.1) D2 SS34: A = SW K = VSOL(+12V) C3 10uF 1 = BAT+ (= U2 IN) 2 = GND C4 22uF: 1 = VSOL 2 = 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

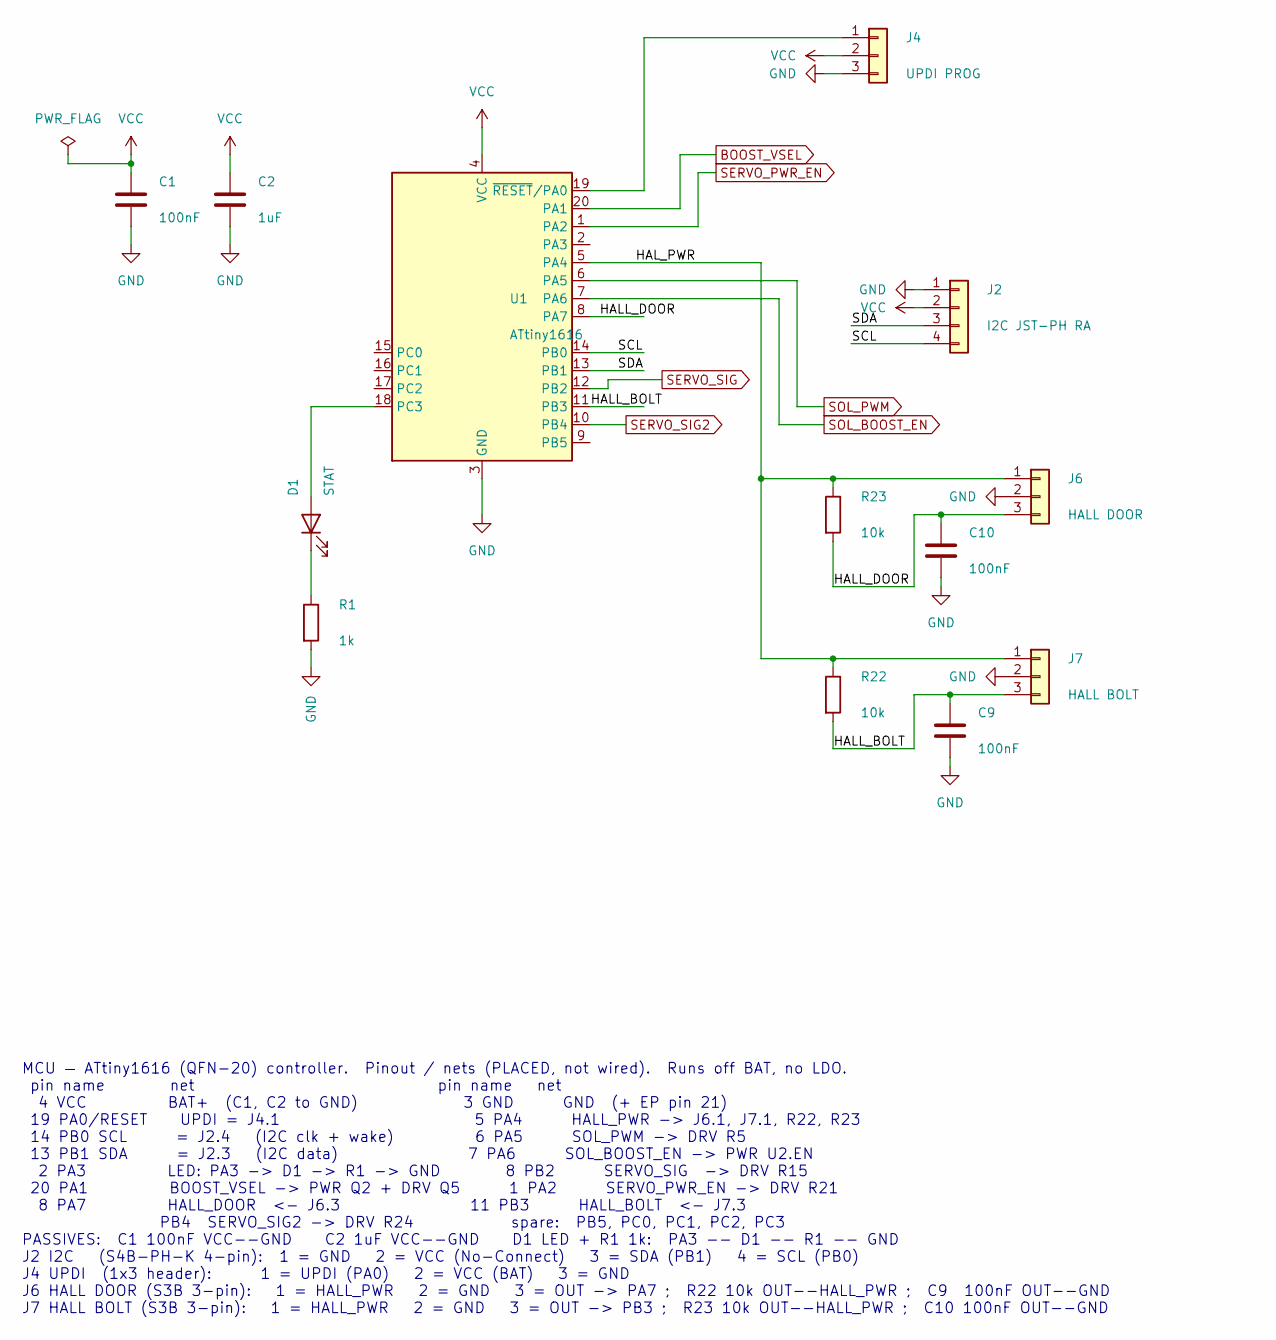
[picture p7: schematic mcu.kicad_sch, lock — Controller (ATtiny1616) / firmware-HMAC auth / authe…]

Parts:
C1, C9, C10: 100nF; C_0402_1005Metric; LCSC C1525
C2: 1uF; C_0402_1005Metric; LCSC C29266
D1: STAT; LED_0402_1005Metric; MPN LTST-C281KGKT; LCSC C160479
J2: I2C JST-PH RA; JST_PH_S4B-PH-K_1x04_P2.00mm_Horizontal; MPN S4B-PH-K-S; LCSC C157926
J4: UPDI PROG; PinHeader_1x03_P2.54mm_Vertical
J6: HALL DOOR; JST_PH_S3B-PH-K_1x03_P2.00mm_Horizontal; MPN S3B-PH-K-S; LCSC C157929
J7: HALL BOLT; JST_PH_S3B-PH-K_1x03_P2.00mm_Horizontal; MPN S3B-PH-K-S; LCSC C157929
R1: 1k; R_0402_1005Metric; LCSC C11702
R22, R23: 10k; R_0402_1005Metric; LCSC C25744
U1: ATtiny1616; VQFN-20-1EP_3x3mm_P0.4mm_EP1.7x1.7mm; MPN ATTINY1616-MNR; LCSC C507118

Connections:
/MCU/HALL_BOLT: C9.1, J7.3, R22.2, U1.11 (PB3)
/MCU/HALL_DOOR: C10.1, J6.3, R23.2, U1.8 (PA7)
/MCU/HAL_PWR: J6.1, J7.1, R22.1, R23.1, U1.5 (PA4)
/MCU/SCL: J2.4, U1.14 (PB0)
/MCU/SDA: J2.3, U1.13 (PB1)
BOOST_VSEL: U1.20 (PA1); also elsewhere on the board
GND: C1.2, C2.2, C9.2, C10.2, J2.1, J4.3, J6.2, J7.2, R1.2, U1.3 (GND), U1.21 (GND); also elsewhere on the board
unnamed: D1.2 (A), U1.18 (PC3)
unnamed: D1.1 (K), R1.1
unnamed: J4.1, U1.19 (~RESET/PA0)
SERVO_PWR_EN: U1.1 (PA2); also elsewhere on the board
SERVO_SIG: U1.12 (PB2); also elsewhere on the board
SERVO_SIG2: U1.10 (PB4); also elsewhere on the board
SOL_BOOST_EN: U1.7 (PA6); also elsewhere on the board
SOL_PWM: U1.6 (PA5); also elsewhere on the board
VCC: C1.1, C2.1, J2.2, J4.2, U1.4 (VCC); also elsewhere on the board

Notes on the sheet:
MCU — ATtiny1616 (QFN-20) controller. Pinout / nets (PLACED, not wired). Runs off BAT, no LDO. pin name net pin name net 4 VCC BAT+ (C1, C2 to GND) 3 GND GND (+ EP pin 21) 19 PA0/RESET UPDI = J4.1 5 PA4 HALL_PWR -> J6.1, J7.1, R22, R23 14 PB0 SCL = J2.4 (I2C clk + wake) 6 PA5 SOL_PWM -> DRV R5 13 P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

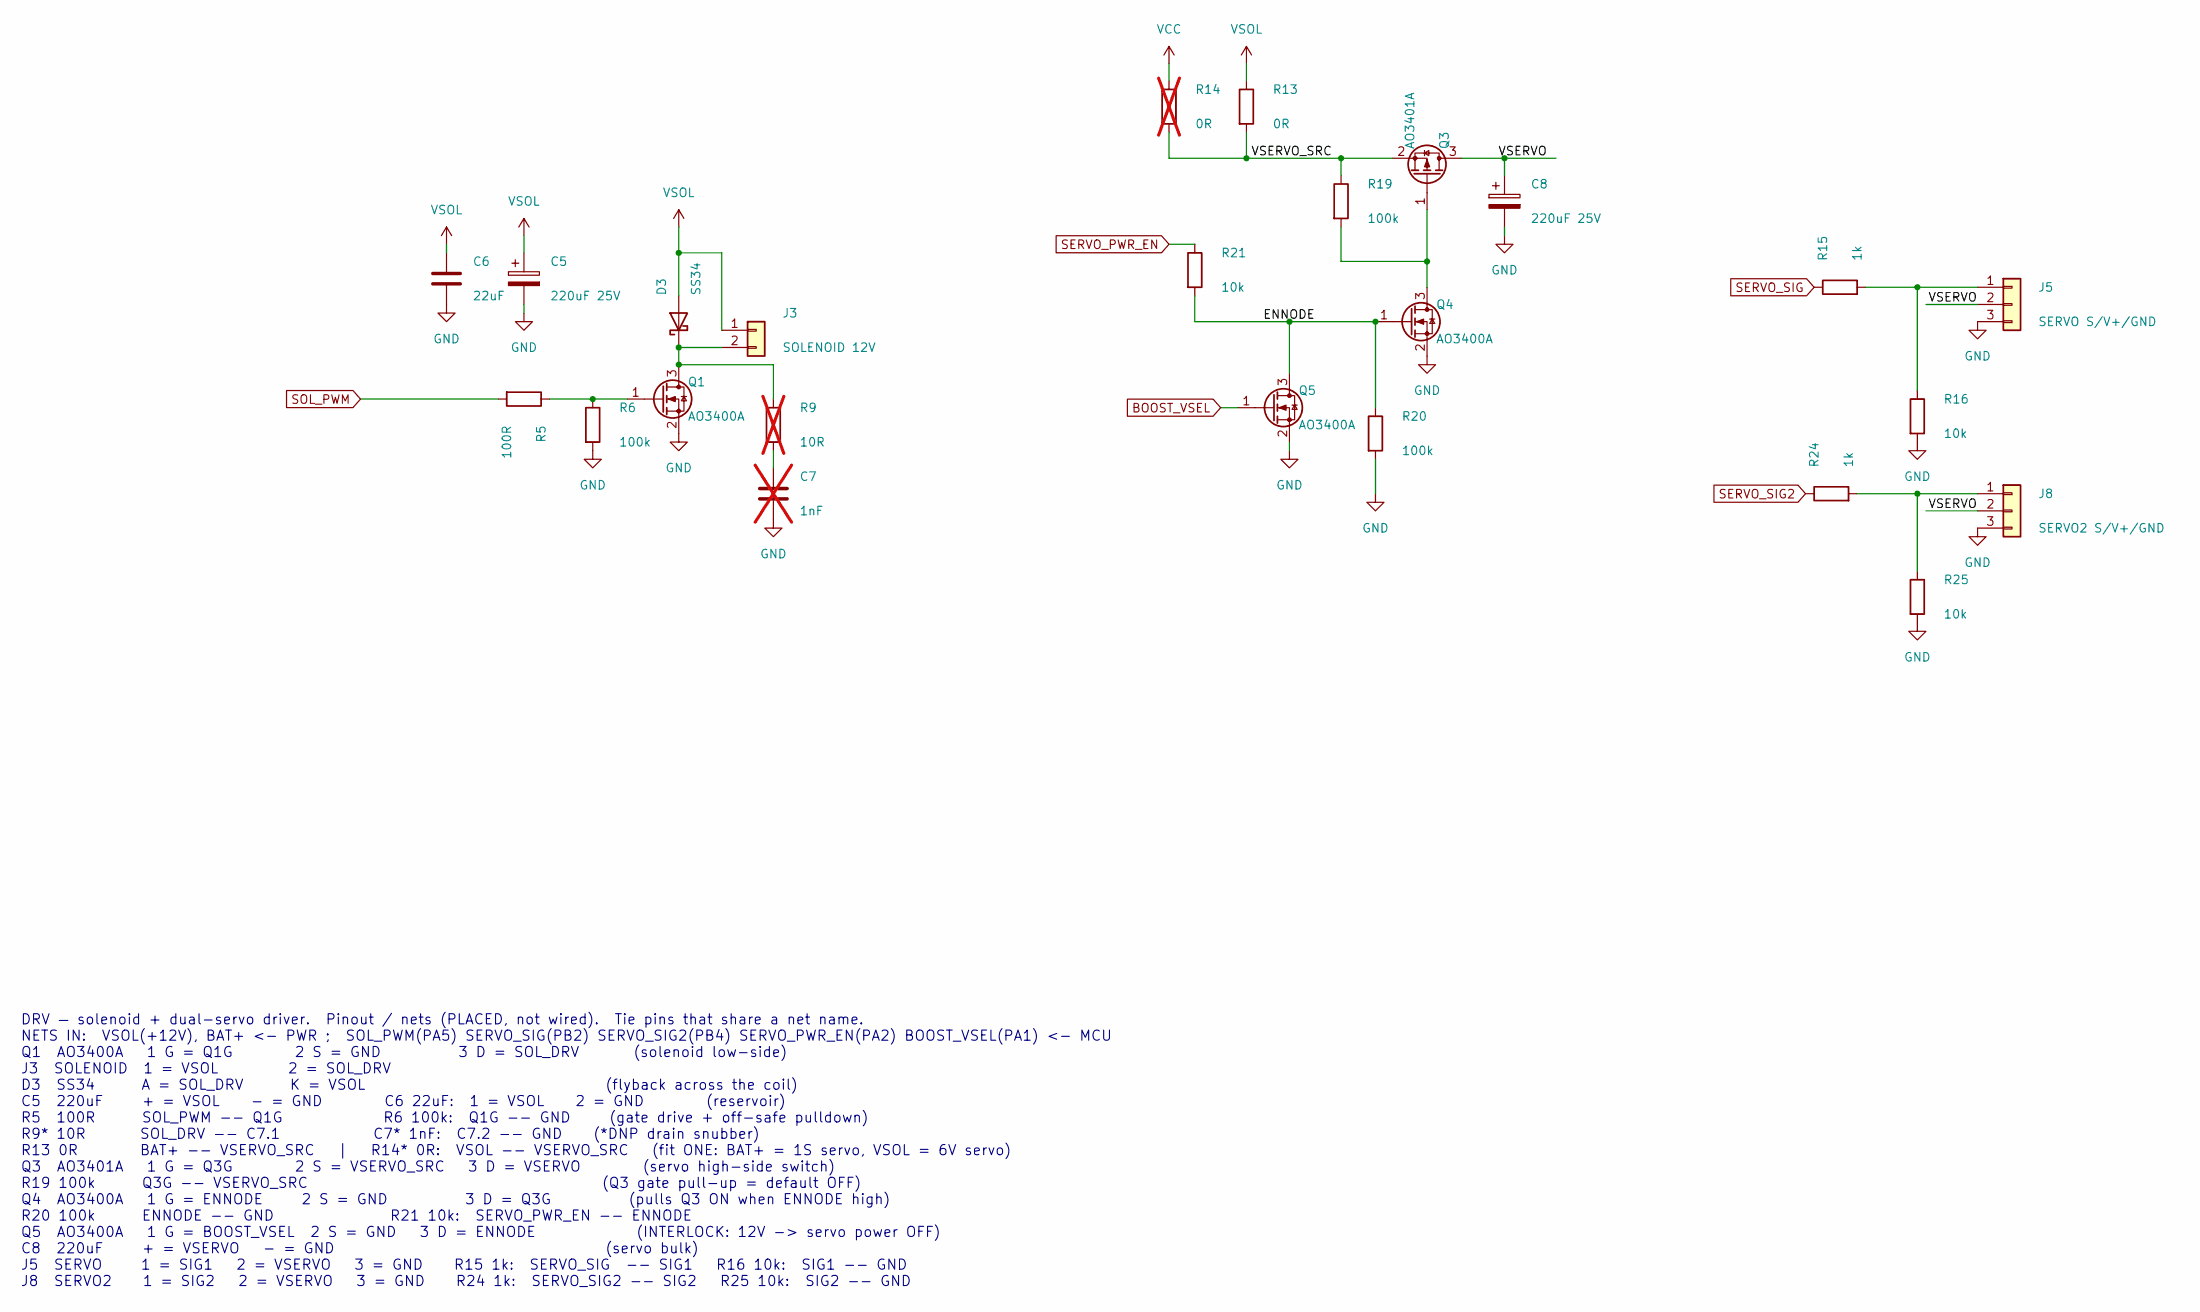
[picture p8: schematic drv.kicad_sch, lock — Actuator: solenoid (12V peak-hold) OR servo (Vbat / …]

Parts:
C5, C8: 220uF 25V; CP_Elec_6.3x7.7; MPN RVT1E221M0607; LCSC C2918361
C6: 22uF; C_1206_3216Metric; LCSC C12891
C7: 1nF; C_0402_1005Metric; not fitted
D3: SS34; D_SMA; MPN SS34; LCSC C8678
J3: SOLENOID 12V; JST_PH_S2B-PH-K_1x02_P2.00mm_Horizontal; MPN S2B-PH-K-S; LCSC C173752
J5: SERVO S/V+/GND; PinHeader_1x03_P2.54mm_Vertical
J8: SERVO2 S/V+/GND; PinHeader_1x03_P2.54mm_Vertical
Q1, Q4, Q5: AO3400A; SOT-23; MPN AO3400A; LCSC C20917
Q3: AO3401A; SOT-23; MPN AO3401A; LCSC C15127
R5: 100R; R_0402_1005Metric; LCSC C106232
R6, R19, R20: 100k; R_0402_1005Metric; LCSC C25741
R9: 10R; R_0402_1005Metric; not fitted
R13: 0R; R_0402_1005Metric; LCSC C17168
R14: 0R; R_0402_1005Metric; LCSC C17168; not fitted
R15, R24: 1k; R_0402_1005Metric; LCSC C11702
R16, R21, R25: 10k; R_0402_1005Metric; LCSC C25744

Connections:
/DRV/ENNODE: Q4.1 (G), Q5.3 (D), R20.1, R21.2
/DRV/VSERVO: C8.1, J5.2, J8.2, Q3.3 (D)
/DRV/VSERVO_SRC: Q3.2 (S), R13.2, R14.2, R19.1
BOOST_VSEL: Q5.1 (G); also elsewhere on the board
GND: C5.2, C6.2, C7.2, C8.2, J5.3, J8.3, Q1.2 (S), Q4.2 (S), Q5.2 (S), R6.2, R16.2, R20.2, R25.2; also elsewhere on the board
unnamed: C7.1, R9.2
unnamed: D3.1 (K), J3.2, Q1.3 (D), R9.1
unnamed: J5.1, R15.2, R16.1
unnamed: J8.1, R24.2, R25.1
unnamed: Q1.1 (G), R5.1, R6.1
unnamed: Q3.1 (G), Q4.3 (D), R19.2
SERVO_PWR_EN: R21.1; also elsewhere on the board
SERVO_SIG: R15.1; also elsewhere on the board
SERVO_SIG2: R24.1; also elsewhere on the board
SOL_PWM: R5.2; also elsewhere on the board
VCC: R14.1; also elsewhere on the board
VSOL: C5.1, C6.1, D3.2 (A), J3.1, R13.1; also elsewhere on the board

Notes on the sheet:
DRV — solenoid + dual-servo driver. Pinout / nets (PLACED, not wired). Tie pins that share a net name. NETS IN: VSOL(+12V), BAT+ <- PWR ; SOL_PWM(PA5) SERVO_SIG(PB2) SERVO_SIG2(PB4) SERVO_PWR_EN(PA2) BOOST_VSEL(PA1) <- MCU Q1 AO3400A 1 G = Q1G 2 S = GND 3 D = SOL_DRV (solenoid low-side) J3 SOLENOID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

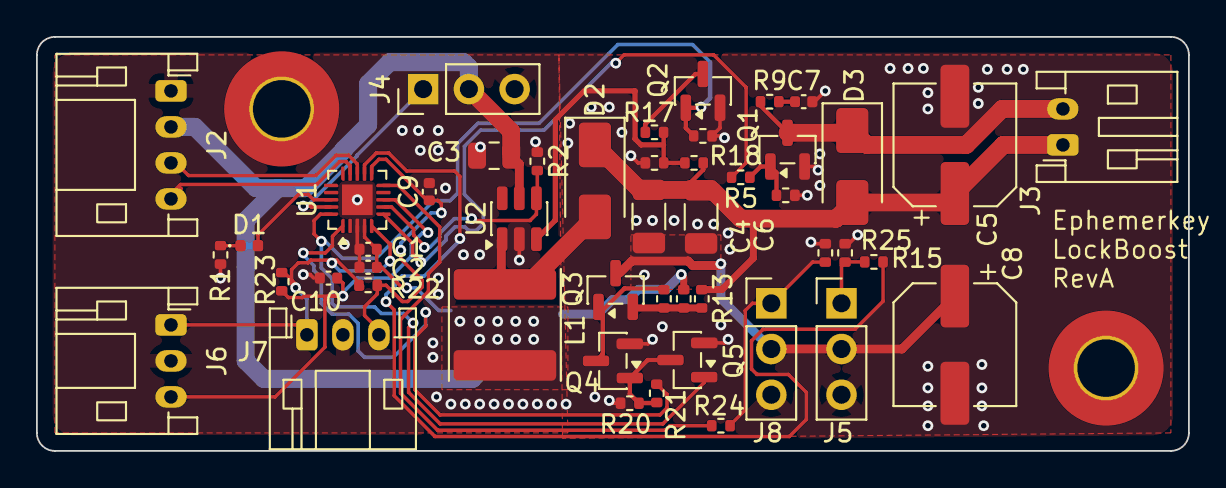
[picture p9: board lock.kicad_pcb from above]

Board: 2 copper layers, 64.0 x 23.0 mm, 50 parts (0 on the bottom side), 29 nets.

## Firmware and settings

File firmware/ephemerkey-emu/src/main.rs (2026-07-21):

//! ekemu — local emulator for an ephemerkey generator + lock pair.
//!
//! Runs the EXACT `ephemerkey-core` engines the firmware ships, under a
//! virtual clock, with the display/key-entry surfaces mimicked in text.
//! Scriptable: commands from stdin (or a file via shell redirection), one
//! per line; `expect` makes scripts self-checking (non-zero exit on miss).
//!
//!   ekemu scenario.json < script.txt
//!
//! Commands:
//!   time +<n>[s|m|h]        advance the virtual clock
//!   time set <unix>         jump the clock
//!   gen reveal [key]        request a code reveal (default key 0)
//!   gen unlock <code|@N>    cascade: dial a code into the generator's unlock
//!                           ritual (@N = a predecessor device's code)
//!   gen dial <d…>|bs|clr|go simulate the 3-button dial (shows the display);
//!                           `go` submits the dialed code to the ritual
//!   gen key <n>             select key n in the UNLOCKED display
//!   gen screen              paint the generator's current OLED face
//!   gen next [key]          seconds until the next REAL reveal
//!   lock enter <code|@N>    type a code at the lock (@N = Nth revealed
//!                           code, 1-based — the "written down" notebook)
//!   lock status             slot states
//!   validate <@R>           relay the Rth emitted receipt to the remote
//!                           validator (confirm-TOTP verification)
//!   env ...                 drive the virtual GNSS/accel/RTC (see cmd_env)
//!   expect <substring>      assert the last event line contains this
//!   echo <text> | # ...     narration / comments
//!   quit

use ephemerkey_core::engine::{LockEngine, Outcome};
use ephemerkey_core::policy::{Action, Sensors};
use ephemerkey_core::receipt::{Receipt, ReceiptCheck, ReceiptMode, Validator};
use ephemerkey_core::totp::Code;
use ephemerkey_core::reveal::{ChainErr, DisplayMode, Generator, RevealErr};
use ephemerkey_config::Calendars;
use ephemerkey_ui::{render, Align, Screen, Size, View};
use serde::Deserialize;
use std::io::BufRead;

mod serial;

// ---------------------------------------------------------------- scenario

#[derive(Deserialize)]
struct Scenario {
    #[serde(default = "default_start")]
    start_time: u64,
    #[serde(default = "default_seed")]
    seed: u32,
    keys: Vec<KeyCfg>,
    slots: Vec<SlotCfg>,
    /// Cascade: seconds a ritual unlock keeps the generator's real reveals open
    /// (the slots double as the generator's unlock ritual — dial codes with
    /// `gen unlock`). Only meaningful when a key is `gated`.
    #[serde(default = "default_unlock_window")]
    unlock_window_s: u32,
    /// Critical features this config depends on: every entry must be in
    /// KNOWN_FEATURES or the scenario/config is refused outright.
    #[serde(default)]
    crit: Vec<String>,
    /// The lock's own confirm-TOTP identity (receipts it mints on every
    /// fire/relock). Absent = the lock stays silent.
    confirm: Option<ConfirmCfg>,
    /// Calendar windows the slot `calendar` gates reference (time-of-week).
    #[serde(default)]
    calendars: Vec<CalendarCfg>,
}

/// A recurring time-of-week window: `days` (0 = Sunday … 6 = Saturday) plus a
/// `HH:MM`–`HH:MM` interval. Mirrors the console's CalendarWindow.
#[derive(Deserialize)]
struct CalendarCfg {
    #[serde(default)]
    days: Vec<u8>,
    #[serde(default)]
    start: String,
    #[serde(default)]
    end: String,
}
fn default_start() -> u64 {
    1_750_000_000
}
fn default_unlock_window() -> u32 {
    30
}

#[derive(Deserialize)]
struct ConfirmCfg {
    secret: String,
    #[serde(default = "default_digits")]
    digits: u8,
    /// "sequence" | "time" | "both"
    #[serde(default)]
    mode: ReceiptModeCfg,
}

#[derive(Deserialize, Default, Clone, Copy)]
#[serde(rename_all = "lowercase")]
enum ReceiptModeCfg {
    #[default]
    Sequence,
    Time,
    Both,
}
impl From<ReceiptModeCfg> for ReceiptMode {
    fn from(m: ReceiptModeCfg) -> Self {
        match m {
            ReceiptModeCfg::Sequence => ReceiptMode::Sequence,
            ReceiptModeCfg::Time => ReceiptMode::Time,
            ReceiptModeCfg::Both => ReceiptMode::Both,
        }
    }
}
fn default_seed() -> u32 {
    0x5EED_C0DE
}

#[derive(Deserialize)]
struct KeyCfg {
    secret: String,
    #[serde(default = "default_digits")]
    digits: u8,
    /// index of this key's decoy twin in `keys`
    decoy: Option<u8>,
    display: Option<DisplayCfg>,
    /// Receipt chain: this key's REAL reveals require feeding the lock's
    /// receipt code back into the generator, then a cooling-off.
    chain: Option<ChainCfg>,
    /// Cascade: this reveal key is ritual-gated. Its real code flows only while
    /// a ritual unlock window is open (see `gen unlock`); otherwise it mints the
    /// poison twin (if `decoy` set) or refuses.
    #[serde(default)]
    gated: bool,
}

#[derive(Deserialize)]
struct ChainCfg {
    /// The lock's confirm secret (the generator holds a Validator over it).
    secret: String,
    #[serde(default = "default_digits")]
    digits: u8,
    #[serde(default)]
    mode: ReceiptModeCfg,
    /// Which receipt action feeds the chain ("lock" = witnessed it locked).
    #[serde(default = "default_chain_action")]
    action: String,
    /// Reveals resume this long after a receipt is fed.
    #[serde(default)]
    min_elapsed_s: u32,
    /// Accepted receipt age for TIME-mode proofs (travel time to a far
    /// generator). Sequence proofs are ageless by construction.
    #[serde(default = "default_max_age")]
    max_age_s: u32,
}
fn default_chain_action() -> String {
    "lock".into()
}
fn default_max_age() -> u32 {
    3600
}
fn default_digits() -> u8 {
    6
}

#[derive(Deserialize)]
struct DisplayCfg {
    #[serde(default)]
    mode: ModeCfg,
    #[serde(default = "default_dwell")]
    dwell_ms: u16,
    #[serde(default = "default_reveal")]
    reveal_s: u16,
    #[serde(default)]
    once: OnceCfg,
    #[serde(default)]
    gap_min_s: u16,
}
fn default_dwell() -> u16 {
    800
}
fn default_reveal() -> u16 {
    5
}

#[derive(Deserialize, Default, Clone, Copy)]
#[serde(rename_all = "lowercase")]
enum ModeCfg {
    #[default]
    Plain,
    Scatter,
}

#[derive(Deserialize, Default, Clone, Copy)]
#[serde(rename_all = "lowercase")]
enum OnceCfg {
    #[default]
    Unlimited,
    Refuse,
    Decoy,
}

#[derive(Deserialize)]
struct SlotCfg {
    key: u8,
    #[serde(default = "default_action")]
    action: String,
    policy: PolicyCfg,
    #[serde(default)]
    progress: bool,
    #[serde(default = "default_true")]
    reset_on_invalid: bool,
    /// "reset" | "lockout:<secs>" | "silent"
    #[serde(default = "default_negative")]
    negative: String,
    #[serde(default)]
    gates: GatesCfg,
    /// Veto window: 0 = fire immediately; >0 = arm, fire after this many
    /// seconds unless a valid code from veto_key cancels.
    #[serde(default)]
    veto_delay_s: u16,
    veto_key: Option<u8>,
    /// 0 = unlimited; otherwise the slot dies after this many fires.
    #[serde(default)]
    budget: u16,
}

/// Position / motion / calendar gates on a slot. Evaluated against the
/// emulator's virtual `Env` (driven by `env` REPL commands).
#[derive(Deserialize, Default)]
struct GatesCfg {
    /// fence-table index the lock must be inside (portable locks)
    fence: Option<u8>,
    /// seconds of stillness required (0 = no stillness gate)
    #[serde(default)]
    stillness_s: u16,
    /// calendar-window index that must be open
    calendar: Option<u8>,
}
fn default_action() -> String {
    "unlock".into()
}
fn default_true() -> bool {
    true
}
fn default_negative() -> String {
    "reset".into()
}

#[derive(Deserialize)]
#[serde(tag = "type", rename_all = "lowercase")]
enum PolicyCfg {
    Always,
    Sequence {
        n: u8,
        window_s: u16,
        gap_min_s: u16,
        gap_max_s: u16,
        #[serde(default)]
        delay_min_s: u16,
        #[serde(default = "default_delay_max")]
        delay_max_s: u16,
        /// 0 = fixed pacing; >0 = each step's accept window is randomly
        /// tightened by up to this many seconds (device-internal draw).
        #[serde(default)]
        jitter_s: u16,
    },
    Path {
        leg_keys: Vec<u8>,
        leg_deadline_s: u16,
        delay_max_s: u16,
    },
    DeadMan {
        beat_s: u16,
    },
    Quorum {
        m: u8,
        keys: Vec<u8>,
        window_s: u16,
        #[serde(default)]
        alternating: bool,
        /// Paced quorum: contributions must keep this generation cadence
        /// (defaults = unpaced).
        #[serde(default)]
        gap_min_s: u16,
        #[serde(default = "default_gap_max")]
        gap_max_s: u16,
    },
}
fn default_gap_max() -> u16 {
    u16::MAX
}
fn default_delay_max() -> u16 {
    60
}

/// Everything this emulated device implements (policy features from the
/// shared engine + the platform gates the virtual env provides).
pub fn known_features() -> Vec<&'static str> {
    let mut f = ephemerkey_core::SUPPORTED_POLICY_FEATURES.to_vec();
    f.extend(["zones", "calendars", "cascade"]);
    f
}

/// Build the generator + lock + remote validator from a scenario — by
/// ENCODING the scenario to the pinned integer-keyed CBOR config and running it
/// back through the shared `ephemerkey-config` decoder/builder, exactly as the
/// firmware does on a sealed config. So the emulator exercises the same CBOR
/// path the device ships (no separate mapping to drift out of sync), and its
/// simulation genuinely runs on CBOR data.
fn build(scn: &Scenario) -> (Generator, LockEngine, LockEngine, Option<Validator>, Calendars, u32) {
    for c in &scn.crit {
        assert!(
            known_features().contains(&c.as_str()),
            "config requires unsupported critical feature '{c}' — refusing"
        );
    }
    let cbor = scenario_to_cbor(scn);
    let model = ephemerkey_config::parse(&cbor, &known_features())
        .expect("scenario → cbor → model");
    (
        ephemerkey_config::build_generator(&model),
        ephemerkey_config::build_lock(&model),
        // The generator's cascade ritual: the same slot table, consumed as an
        // unlock ritual rather than a lock-consumer (see `gen unlock`).
        ephemerkey_config::build_ritual(&model),
        ephemerkey_config::build_validator(&model),
        model.calendars(),
        model.unlock_window_s,
    )
}

// ---- scenario → integer-keyed CBOR config (see ephemerkey_config schema) ---

/// Encode a scenario as the sealed config the firmware parses. The role field
/// is a placeholder (the emulator simulates both sides; the `build_*` functions
/// ignore role), so only keys/slots/confirm/crit carry meaning here.
fn scenario_to_cbor(scn: &Scenario) -> Vec<u8> {
    use ephemerkey_envelope::cbor::Enc;
    let mut buf = [0u8; 4096];
    let mut e = Enc::new(&mut buf);
    // A generator cascade is in play when any key is gated; only then emit the
    // unlock window (and the config must carry crit:["cascade"] to be accepted).
    let has_cascade = scn.keys.iter().any(|k| k.gated);
    let mut top = 1u64; // role
    top += !scn.keys.is_empty() as u64;
    top += !scn.slots.is_empty() as u64;
    top += !scn.calendars.is_empty() as u64;
    top += scn.confirm.is_some() as u64;
    top += !scn.crit.is_empty() as u64;
    top += has_cascade as u64;
    e.map(top).unwrap();
    e.uint(1).unwrap();
    e.uint(1).unwrap(); // placeholder role
    if has_cascade {
        e.uint(9).unwrap();
        e.uint(scn.unlock_window_s as u64).unwrap();
    }
    if !scn.keys.is_empty() {
        e.uint(4).unwrap();
        e.array(scn.keys.len() as u64).unwrap();
        for k in &scn.keys {
            enc_key(&mut e, k);
        }
    }
    if !scn.slots.is_empty() {
        e.uint(5).unwrap();
        e.array(scn.slots.len() as u64).unwrap();
        for s in &scn.slots {
            enc_slot(&mut e, s);
        }
    }
    if !scn.calendars.is_empty() {
        e.uint(6).unwrap();
        e.array(scn.calendars.len() as u64).unwrap();
        for c in &scn.calendars {
            e.map(3).unwrap();
            e.uint(1).unwrap();
            e.uint(days_mask(&c.days)).unwrap();
            e.uint(2).unwrap();
            e.uint(hhmm_min(&c.start)).unwrap();
            e.uint(3).unwrap();
            e.uint(hhmm_min(&c.end)).unwrap();
        }
    }
    if let Some(c) = &scn.confirm {
        e.uint(7).unwrap();
        e.map(3).unwrap();
        e.uint(1).unwrap();
        e.bstr(c.secret.as_bytes()).unwrap();
        e.uint(2).unwrap();
        e.uint(c.digits as u64).unwrap();
        e.uint(3).unwrap();
        e.uint(mode_u(c.mode)).unwrap();
    }
    if !scn.crit.is_empty() {
        e.uint(8).unwrap();
        e.array(scn.crit.len() as u64).unwrap();
        for c in &scn.crit {
            e.tstr(c).unwrap();
        }
    }
    let n = e.len();
    buf[..n].to_vec()
}

fn enc_key(e: &mut ephemerkey_envelope::cbor::Enc<'_>, k: &KeyCfg) {
    let mut cnt = 2u64; // secret + digits
    cnt += k.decoy.is_some() as u64;
    cnt += k.display.is_some() as u64;
    cnt += k.chain.is_some() as u64;
    cnt += k.gated as u64;
    e.map(cnt).unwrap();
    e.uint(1).unwrap();
    e.bstr(k.secret.as_bytes()).unwrap();
    e.uint(2).unwrap();
    e.uint(k.digits as u64).unwrap();
    if let Some(d) = k.decoy {
        e.uint(3).unwrap();
        e.uint(d as u64).unwrap();
    }
    if let Some(d) = &k.display {
        e.uint(4).unwrap();
        e.map(5).unwrap();
        e.uint(1).unwrap();
        e.uint(match d.mode {
            ModeCfg::Plain => 0,
            ModeCfg::Scatter => 1,
        })
        .unwrap();
        e.uint(2).unwrap();
        e.uint(d.dwell_ms as u64).unwrap();
        e.uint(3).unwrap();
        e.uint(d.reveal_s as u64).unwrap();
        e.uint(4).unwrap();
        e.uint(match d.once {
            OnceCfg::Unlimited => 0,
            OnceCfg::Refuse => 1,
            OnceCfg::Decoy => 2,
        })
        .unwrap();
        e.uint(5).unwrap();
        e.uint(d.gap_min_s as u64).unwrap();
    }
    if let Some(c) = &k.chain {
        e.uint(5).unwrap();
        e.map(6).unwrap();
        e.uint(1).unwrap();
        e.bstr(c.secret.as_bytes()).unwrap();
        e.uint(2).unwrap();
        e.uint(c.digits as u64).unwrap();
        e.uint(3).unwrap();
        e.uint(mode_u(c.mode)).unwrap();
        e.uint(4).unwrap();
        e.uint(action_u(&c.action)).unwrap();
        e.uint(5).unwrap();
        e.uint(c.min_elapsed_s as u64).unwrap();
        e.uint(6).unwrap();
        e.uint(c.max_age_s as u64).unwrap();
    }
    if k.gated {
        e.uint(7).unwrap();
        e.bool(true).unwrap();
    }
}

fn enc_slot(e: &mut ephemerkey_envelope::cbor::Enc<'_>, s: &SlotCfg) {
    let mut cnt = 9u64; // fields 1-8 + 10
    cnt += s.veto_key.is_some() as u64;
    e.map(cnt).unwrap();
    e.uint(1).unwrap();
    e.uint(s.key as u64).unwrap();
    e.uint(2).unwrap();
    e.uint(action_u(&s.action)).unwrap();
    e.uint(3).unwrap();
    enc_policy(e, &s.policy);
    e.uint(4).unwrap();
    e.bool(s.progress).unwrap();
    e.uint(5).unwrap();
    e.bool(s.reset_on_invalid).unwrap();
    e.uint(6).unwrap();
    enc_negative(e, &s.negative);
    e.uint(7).unwrap();
    enc_gates(e, &s.gates);
    e.uint(8).unwrap();
    e.uint(s.veto_delay_s as u64).unwrap();
    if let Some(vk) = s.veto_key {
        e.uint(9).unwrap();
        e.uint(vk as u64).unwrap();
    }
    e.uint(10).unwrap();
    e.uint(s.budget as u64).unwrap();
}

fn enc_policy(e: &mut ephemerkey_envelope::cbor::Enc<'_>, p: &PolicyCfg) {
    match p {
        PolicyCfg::Always => {
            e.map(1).unwrap();
            e.uint(1).unwrap();
            e.uint(0).unwrap();
        }
        PolicyCfg::Sequence {
            n,
            window_s,
            gap_min_s,
            gap_max_s,
            delay_min_s,
            delay_max_s,
            jitter_s,
        } => {
            e.map(8).unwrap();
            e.uint(1).unwrap();
            e.uint(1).unwrap();
            for (k, v) in [
                (2, *n as u64),
                (3, *window_s as u64),
                (4, *gap_min_s as u64),
                (5, *gap_max_s as u64),
                (6, *delay_min_s as u64),
                (7, *delay_max_s as u64),
                (8, *jitter_s as u64),
            ] {
                e.uint(k).unwrap();
                e.uint(v).unwrap();
            }
        }
        PolicyCfg::Path {
            leg_keys,
            leg_deadline_s,
            delay_max_s,
        } => {
            e.map(4).unwrap();
            e.uint(1).unwrap();
            e.uint(2).unwrap();
            e.uint(2).unwrap();
            e.array(leg_keys.len() as u64).unwrap();
            for k in leg_keys {
                e.uint(*k as u64).unwrap();
            }
            e.uint(3).unwrap();
            e.uint(*leg_deadline_s as u64).unwrap();
            e.uint(4).unwrap();
            e.uint(*delay_max_s as u64).unwrap();
        }
        PolicyCfg::DeadMan { beat_s } => {
            e.map(2).unwrap();
            e.uint(1).unwrap();
            e.uint(3).unwrap();
            e.uint(2).unwrap();
            e.uint(*beat_s as u64).unwrap();
        }
        PolicyCfg::Quorum {
            m,
            keys,
            window_s,
            alternating,
            gap_min_s,
            gap_max_s,
        } => {
            e.map(7).unwrap();
            e.uint(1).unwrap();
            e.uint(4).unwrap();
            e.uint(2).unwrap();
            e.uint(*m as u64).unwrap();
            e.uint(3).unwrap();
            e.array(keys.len() as u64).unwrap();
            for k in keys {
                e.uint(*k as u64).unwrap();
            }
            e.uint(4).unwrap();
            e.uint(*window_s as u64).unwrap();
            e.uint(5).unwrap();
            e.bool(*alternating).unwrap();
            e.uint(6).unwrap();
            e.uint(*gap_min_s as u64).unwrap();
            e.uint(7).unwrap();
            e.uint(*gap_max_s as u64).unwrap();
        }
    }
}

fn enc_gates(e: &mut ephemerkey_envelope::cbor::Enc<'_>, g: &GatesCfg) {
    let mut cnt = 1u64; // stillness always
    cnt += g.fence.is_some() as u64;
    cnt += g.calendar.is_some() as u64;
    e.map(cnt).unwrap();
    if let Some(f) = g.fence {
        e.uint(1).unwrap();
        e.uint(f as u64).unwrap();
    }
    e.uint(2).unwrap();
    e.uint(g.stillness_s as u64).unwrap();
    if let Some(c) = g.calendar {
        e.uint(3).unwrap();
        e.uint(c as u64).unwrap();
    }
}

fn enc_negative(e: &mut ephemerkey_envelope::cbor::Enc<'_>, s: &str) {
    if s == "silent" {
        e.array(1).unwrap();
        e.uint(1).unwrap();
    } else if let Some(secs) = s.strip_prefix("lockout:") {
        e.array(2).unwrap();
        e.uint(2).unwrap();
        e.uint(secs.parse::<u64>().expect("lockout secs")).unwrap();
    } else {
        e.array(1).unwrap();
        e.uint(0).unwrap();
    }
}

fn action_u(s: &str) -> u64 {
    match s {
        "lock" => 1,
        "duress" => 2,
        _ => 0, // unlock
    }
}

fn mode_u(m: ReceiptModeCfg) -> u64 {
    match m {
        ReceiptModeCfg::Sequence => 0,
        ReceiptModeCfg::Time => 1,
        ReceiptModeCfg::Both => 2,
    }
}

/// Days list (0 = Sunday … 6 = Saturday) → the bit-`i`-per-day mask.
fn days_mask(days: &[u8]) -> u64 {
    days.iter().filter(|&&d| d < 7).fold(0u64, |m, &d| m | (1 << d))
}

/// `"HH:MM"` → minutes from midnight.
fn hhmm_min(s: &str) -> u64 {
    let mut it = s.split(':');
    let h: u64 = it.next().and_then(|x| x.parse().ok()).unwrap_or(0);
    let m: u64 = it.next().and_then(|x| x.parse().ok()).unwrap_or(0);
    h * 60 + m
}

// ------------------------------------------------------------------- env
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
fn main() {
    let arg = std::env::args().nth(1).unwrap_or_else(|| {
        eprintln!("usage: ekemu <scenario.json>  (commands on stdin)");
        eprintln!("       ekemu serial <state.json> [listen_addr]");
        std::process::exit(2);
    });
    if arg == "serial" {
        let state = std::env::args().nth(2).unwrap_or_else(|| {
            eprintln!("usage: ekemu serial <state.json> [listen_addr]");
            std::process::exit(2);
        });
        let listen = std::env::args().nth(3).unwrap_or_else(|| "127.0.0.1:8422".into());
        serial::run(&state, &listen);
        return;
    }
    let scn: Scenario =
        serde_json::from_str(&std::fs::read_to_string(&arg).expect("read scenario"))
            .expect("parse scenario");
    let (gen, lock, ritual, validator, calendars, unlock_window_s) = build(&scn);
    let mut emu = Emu {
        now: scn.start_time,
        seed: scn.seed,
        gen,
        lock,
        ritual,
        unlock_window_s,
        env: Env { calendars, ..Default::default() },
        validator,
        last_event: String::new(),
        failures: 0,
        dial: Vec::new(),
        sel: 0,
        notebook: Vec::new(),
        receipts: Vec::new(),
    };
    println!("ekemu: scenario {arg}, t={}", emu.now);

    let stdin = std::io::stdin();
    for line in stdin.lock().lines() {
        let line = line.expect("stdin");
        if !emu.cmd(&line) {
            break;
        }
    }
    if emu.failures > 0 {
        eprintln!("ekemu: {} expectation(s) FAILED", emu.failures);
        std::process::exit(1);
    }
}

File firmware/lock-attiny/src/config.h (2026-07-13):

/*
 * ephemerkey lock board — programmable configuration (ATtiny1616)
 *
 * A bit-packed config blob, provisioned over I2C with its own HMAC secret
 * (REG_CONFIG), persisted in EEPROM, loaded at boot. Falls back to compile-time
 * defaults when EEPROM is unprogrammed.
 *
 * Actuation is a programmable STEP SEQUENCE: an ordered list of phases run on
 * UNLOCK, and an independent list run on LOCK. Each step fires any combination
 * of {servo1, servo2, solenoid} together, with per-step servo target positions
 * (so a servo can be driven either direction), a run time, and an optional
 * early-off sensor that ends the step early and advances to the next one.
 */
#ifndef CONFIG_H
#define CONFIG_H

#include <stdint.h>

#define CONFIG_MAGIC     0xE4       /* bump on layout change */

#define SEQ_STEPS        6          /* max phases per sequence */
#define STEP_BYTES       5          /* wire size of one step_t */
#define CONFIG_HDR       5          /* header bytes before the sequences */
#define CONFIG_LEN       (CONFIG_HDR + STEP_BYTES * SEQ_STEPS * 2)  /* 65 */

/* --- flags byte --- */
/* 6 V boosted servo: servo-only steps run off the boost rail at 6 V (BOOST_VSEL
 * low = interlock clear) instead of Vbat, for a 6 V servo. Requires the servo
 * strapped to VSOL (R13, the default). Off by default — do NOT set it unless the
 * board is wired for a boosted servo. Combined servo+solenoid steps force 6 V
 * regardless (see step.act below). */
#define CFG_SERVO_BOOST  0x01

/* --- step.act bits (which actuators the step drives) --- */
#define STEP_SERVO1      0x01
#define STEP_SERVO2      0x02
#define STEP_SOLENOID    0x04
/* act == 0 marks the end of the sequence (remaining steps ignored). */

/* --- step.eoff: per-step early-off selector --- */
/* bits 0-1: which LOGICAL sensor gates the step (resolved through sensor_map) */
#define EOFF_NONE        0u
#define EOFF_DOOR        1u         /* the DOOR_CLOSED logical sensor */
#define EOFF_BOLT        2u         /* the BOLT_LOCKED logical sensor */
#define EOFF_SENSOR_MASK 0x03u
/* bit 2: trigger edge. Clear = advance when the magnet is PRESENT (sensor
 * active); set = advance when the magnet is ABSENT (e.g. door opened).
 * Deglitched (see actuate.c): the step must first CONFIRM the opposite state
 * (arm), then an integrating counter of fixed-cadence samples must reach the
 * firing level — a few transients only delay it; a sensor that never shows the
 * opposite state (broken/disturbed) never fires and the step runs full time. */
#define EOFF_EDGE_ABSENT 0x04u

/* sensor_map: each STATUS role picks its source sensor, so either physical port
 * (J6 or J7) can be the "door" or the "bolt" indicator (or a role can be off).
 * The per-step early-off DOOR/BOLT selectors resolve through this map too.
 *   bits 0-1: DOOR_CLOSED source   bits 2-3: BOLT_LOCKED source */
#define SENSOR_SRC_J6    0u   /* HALL pin on J6, PA7 */
#define SENSOR_SRC_J7    1u   /* HALL pin on J7, PB3 */
#define SENSOR_SRC_OFF   2u   /* role disabled -> reads 0 */
#define SENSOR_DOOR_SHIFT 0
#define SENSOR_BOLT_SHIFT 2
#define SENSOR_SRC_MASK  0x03u

/* One phase of a sequence. All uint8_t, so struct layout == wire layout. */
typedef struct {
    uint8_t act;      /* STEP_* actuator bits; 0 = end of sequence */
    uint8_t s1_pos;   /* servo1 target 0..255 -> 500..2500 us (if STEP_SERVO1) */
    uint8_t s2_pos;   /* servo2 target (if STEP_SERVO2) */
    uint8_t dur_ds;   /* run time, x100 ms (servo drive / solenoid hold), 0..25.5 s */
    uint8_t eoff;     /* early-off selector (EOFF_*) */
} step_t;

/* Packed blob — all uint8_t, so struct layout == wire layout (no padding). */
typedef struct {
    uint8_t magic;       /* CONFIG_MAGIC */
    uint8_t flags;       /* CFG_* */
    uint8_t strike_cs;   /* solenoid strike (full pull-in) time, x10 ms (12 V economizer) */
    uint8_t hold_duty;   /* solenoid economizer hold PWM duty, 0..255 -> 0..100 % */
    uint8_t sensor_map;  /* door/bolt role -> J6/J7/off (see SENSOR_*) */
    step_t  seq_unlock[SEQ_STEPS];
    step_t  seq_lock[SEQ_STEPS];
} config_t;

void            config_init(void);                  /* load EEPROM or defaults */
const config_t *config_get(void);
void            config_to_blob(uint8_t out[CONFIG_LEN]);

/* Validate a received blob (magic), persist to EEPROM, reload. Returns 1 on ok. */
uint8_t         config_apply_blob(const uint8_t blob[CONFIG_LEN]);

/* Encoding helpers. */
uint16_t        cfg_pos_to_us(uint8_t pos);         /* 0..255 -> 500..2500 us */
uint16_t        cfg_strike_ms(void);                /* strike_cs * 10 */
uint8_t         cfg_door_src(void);                 /* SENSOR_SRC_* for DOOR_CLOSED */
uint8_t         cfg_bolt_src(void);                 /* SENSOR_SRC_* for BOLT_LOCKED */

#endif /* CONFIG_H */

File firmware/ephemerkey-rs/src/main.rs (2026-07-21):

//! ephemerkey — GPS-geofenced TOTP (RFC 6238) code generator.
//!
//! One firmware, two build targets sharing the same STM32U0x3 die:
//!   - `board-ephemerkey`  → STM32U083KCU6 (UFQFPN-32), the product board.
//!   - `board-nucleo-u083` → STM32U083RCT6 (NUCLEO-U083RC), for bench bring-up
//!     of the flash-journal / identity / USB-provisioning path with no GNSS,
//!     ESP32, lock, or sensors attached.
//!
//! Board selection (a Cargo feature) picks the embassy chip feature and the two
//! board-specific pins below; the on-board subsystems (`gnss`, `wifi`, `lock`,
//! `sensors`, `buzzer`) are each behind their own feature so a bare Nucleo
//! compiles and links without them. The store/identity/USB code is identical
//! across both.
//!
//! Architecture: one async task per subsystem. Sleep is the executor's WFI;
//! Stop-mode entry is a later step (see README).

#![no_std]
#![no_main]

use defmt::info;
use defmt_rtt as _;
use panic_probe as _;

use embassy_executor::Spawner;
use embassy_stm32::flash::Flash;
use embassy_stm32::gpio::{Input, Level, Output, Pull, Speed};
use embassy_stm32::rng::Rng;
use embassy_stm32::{bind_interrupts, peripherals, rng};
#[cfg(feature = "usb-provision")]
use embassy_stm32::usb;
use embassy_time::Timer;

// Policy engine + TOTP + reveal scheduler live in the shared no_std core,
// exercised on-host by the emulator (../ephemerkey-emu) and tests.
use ephemerkey_core as _;

// Some clock/gate API is only exercised on the generator (gnss) build; keep it
// across configurations even when a given board doesn't call it.
#[allow(dead_code)]
mod clock;
mod config;
#[allow(dead_code)]
mod gate;
#[cfg(feature = "hw-aes")]
mod pacaes;
mod provision;
#[cfg(feature = "usb-provision")]
mod usbcdc;
#[cfg(feature = "usb-provision")]
mod usbprov;

#[cfg(feature = "buzzer")]
mod buzzer;
#[cfg(oled)]
mod display;
#[cfg(feature = "gnss")]
mod generator;
#[cfg(feature = "gnss")]
mod gnss;
#[cfg(feature = "lock")]
mod lock;
#[cfg(any(feature = "gnss", feature = "lock", feature = "sensors"))]
mod motion;
#[cfg(all(feature = "lock", feature = "usb-provision"))]
mod lockconsole;
#[cfg(feature = "sensors")]
mod sensors;
#[cfg(feature = "wifi")]
mod wifi;

// Shared blocking I2C1 bus (PB6/PB7): the generator's OLED and the accel
// sampler each hold an `I2c1Dev` handle to it. Single-executor, cooperative —
// a blocking transaction never awaits — so a `NoopRawMutex` is sound and, unlike
// a critical-section mutex, doesn't disable interrupts across the (multi-ms)
// OLED flush.
#[cfg(feature = "sensors")]
use embassy_embedded_hal::shared_bus::blocking::i2c::I2cDevice;
#[cfg(feature = "sensors")]
use embassy_sync::blocking_mutex::{raw::NoopRawMutex, Mutex as BlockingMutex};
#[cfg(feature = "sensors")]
use static_cell::StaticCell;
#[cfg(feature = "sensors")]
type I2c1Raw =
    embassy_stm32::i2c::I2c<'static, embassy_stm32::mode::Blocking, embassy_stm32::i2c::mode::Master>;
#[cfg(feature = "sensors")]
pub type I2c1Bus = BlockingMutex<NoopRawMutex, core::cell::RefCell<I2c1Raw>>;
#[cfg(feature = "sensors")]
pub type I2c1Dev = I2cDevice<'static, NoopRawMutex, I2c1Raw>;

bind_interrupts!(pub struct Irqs {
    RNG_CRYP => rng::InterruptHandler<peripherals::RNG>;
    #[cfg(feature = "usb-provision")]
    USB_DRD_FS => usb::InterruptHandler<peripherals::USB>;
});

#[embassy_executor::main]
async fn main(spawner: Spawner) {
    #[allow(unused_mut)]
    let mut config = embassy_stm32::Config::default();
    // TODO(clocks): LSE 32.768 kHz -> RTC (the TOTP timebase, disciplined from
    // GNSS PPS). For USB we run the crystal-less path: HSI48 trimmed by CRS off
    // the USB SOF. embassy's U0 Config::default() already enables HSI48; ask CRS
    // to sync from USB so it stays within the ±0.25% FS spec without a crystal.
    #[cfg(feature = "usb-provision")]
    {
        config.rcc.hsi48 = Some(embassy_stm32::rcc::Hsi48Config { sync_from_usb: true });
    }
    // RTC clock source (TOTP time base). The product board has the 32.768 kHz
    // LSE crystal (PC14/PC15); the Nucleo has no guaranteed crystal, so fall
    // back to the LSI. DESIGN.md Open Question 8 tracks LSE-vs-LSI accuracy.
    #[cfg(feature = "board-ephemerkey")]
    {
        config.rcc.ls = embassy_stm32::rcc::LsConfig::default_lse();
    }
    #[cfg(feature = "board-nucleo-u083")]
    {
        config.rcc.ls = embassy_stm32::rcc::LsConfig::default_lsi();
    }
    let p = embassy_stm32::init(config);

    // TOTP time base. Undisciplined until the GNSS provides UTC; `now()` reads 0
    // until then (see clock::now_unix / is_fresh).
    clock::init(p.RTC);

    // --- Board-specific pins -------------------------------------------------
    // status LED (heartbeat / provisioning-mode indicator) and the provisioning
    // button (active-low). Everything else is board-independent.
    #[cfg(feature = "board-ephemerkey")]
    let (status_led, prov_button) = (
        Output::new(p.PB0, Level::Low, Speed::Low), // green, in-fence/code-valid
        Input::new(p.PA5, Pull::Up),                // SW1
    );
    #[cfg(feature = "board-nucleo-u083")]
    let (status_led, prov_button) = (
        Output::new(p.PA5, Level::Low, Speed::Low), // LD2 (green)
        Input::new(p.PC13, Pull::Up),               // B1 user button
    );
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

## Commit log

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2026-06-21 Add USB-C input + Li-ion charging subsystem (house parts)
    Resolved power decisions: 1S Li-ion (rechargeable), USB-C powers+charges+
    provisions, GNSS kept hot via V_BCKP. Charger/USB front-end reuses parts
    already used in sibling projects for BOM consolidation:
    - USB-C: GCT USB4105 (USB-TYPE-C-019, C2927039) — house-standard connector
    - ESD: USBLC6-2SC6 (C2687116)
    - Charger: MCP73831T-2ACI/OT (C424093), Rprog sets Ichg
    - Power path: AO3401A P-FET (C15127) load-share — run/charge from USB without
    cycling the battery; SYS feeds TPS63900 VIN (VBUS~4.7V or BAT 3.0-4.2V)
    DESIGN.md: new power-tree, "USB-C input + Li-ion charging" section, parts +
    library-map rows, resolved decisions/open-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
    [psu.kicad_sch]
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2026-06-22 Fix kschgen: flatten extends-based symbols so they render
    Root cause of the "blank symbol" (J1 TC2030-NL, U3 USBLC6-2SC6): kschgen
    copied the raw library symbol keeping (extends "PARENT"). KiCad/eeschema
    resolves extends at load, but kicad-cli's SVG/PDF exporters do NOT — a derived
    symbol with unresolved extends renders as just ref/value text (no body).
    tsumikoro renders fine because it's eeschema-authored (symbols already
    flattened); notchdeck + ephemerkey use kschgen and were blank.
    Fix: kschgen now flattens — _flattened_block() re-bases a parent's full block
    (graphics + pins) onto the child name and drops the extends, recursively. No
    (extends) remain in generated sheets; J1/U3 now re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
    [ephemerkey.kicad_sch, gnss.kicad_sch, mcu.kicad_sch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]
2026-06-22 Add 128x32 I2C OLED (DS1) on a 4-pin 0.1" header
    Uses the KiCad standard-library symbol Display_Graphic:ER_OLEDM0.91_1x-I2C
    (0.91" = 128x32 I2C OLED panel type), mapped to a 4-pin 0.1" pin header
    (PinHeader_1x04_P2.54mm_Vertical) so an OLED module plugs in.
    Pinout: 1 GND, 2 VCC(3V3), 3 SCL->PB6, 4 SDA->PB7 — shares I2C1 with U5 LIS3DH
    (OLED 0x3C vs LIS3DH 0x18); the existing R9/R10 4.7k pull-ups serve both.
    Placed on the MCU sheet with the other connectors; renders correctly.
    make check: 60 components, 60/60 footprints, no dup refs. DESIGN.md library
    map + display open-question resolved; PARTS.md updated.
    [ephemerkey.kicad_sch, gnss.kicad_sch, mcu.kicad_sch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]
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2026-06-28 lock: switch ephemerkey<->lock link to master-driven I2C (wake-on-I2C)
    Replace the 4-wire authenticated UART with a 3-wire authenticated I2C bus:
    - ephemerkey is the I2C master, the lock (ATtiny1616) is the target (0x60).
    Challenge-response is master-driven: read the nonce, then write the
    HMAC-SHA1(secret, nonce||code).
    - Drop the discrete CODE_REQ wake line (don't mix a button-style input with
    the bus). The lock wakes from power-down on the first I2C START (pin-change
    interrupt on SCL); the master sends a dummy/wake xfer then retries.
    - 3-wire J2 (GND/SCL/SDA), 1x3 on both boards.
    - I2C pull-ups R11/R12 (4.7k) on ephemerkey's 3V3 (master side) -- the lock
    runs at VBAT, so master-s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
    [drv.kicad_sch, ephemerkey.kicad_sch, gnss.kicad_sch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]
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2026-07-01 lock: commit repoured board — clearance shorts cleared (DRC)
    Repour resolved all 7 track-to-GND-zone clearance violations (stale fill).
    Remaining DRC: 3 starved-thermal on J6/J7 GND (mild). 0 unconnected, 0 parity.
    [lock.kicad_pcb]
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2026-07-01 jlcpcb: fix BOM/CPL so JLCPCB matches all SMD parts
    Two packaging bugs caused JLCPCB to report parts 'not in BOM/CPL':
    - BOM collapsed designators into ranges (R18-R20); JLCPCB doesn't expand them,
    so real SMD resistors R18-R23 would silently not be placed. Now exported with
    --ref-range-delimiter '' (individual refs, comma-separated).
    - CPL included DNP parts (R14/R9/C7) that the BOM omits -> mismatch. Now
    --exclude-dnp on the pos export; SMD BOM<->CPL sets reconcile exactly.
    Remaining J2-J8 (through-hole connectors) absent from the SMT CPL is expected —
    hand-solder them or enable THT assembly. Re-captured fab/ snapshot + BUILD.md.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
    [lock-BOM.csv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]
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2026-07-01 lock: 220uF 25V C5/C8 -> C4747974 (RST220UF25V019), Economic-eligible
    Swap the reservoir/servo-bulk electrolytic from C2918361 (not available for
    JLCPCB Economic assembly) to C4747974 — same D6.3xL7.7mm body, Economic-eligible.
    Updated schematic (C5/C8), manifest, README BOM, and BUILD.md; remade BOM/CPL
    (BOM<->CPL still match exactly, 42=42).
    [drv.kicad_sch, lock-BOM.csv]
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2026-07-01 ephemerkey: add buzzer (PB4/TIM3_CH1), 2nd vertical USB-C, antenna 1.8pF shunt
    - Beeper: LS1 MLT-8530 (C94599, 3.6V magnetic transducer) + AO3400A low-side
    driver (Q2) + 1N4148W flyback (D5) + gate 100R/100k, driven by PB4/TIM3_CH1.
    PB4 verified as TIM3_CH1 (AF1) on the U0 family AF map; TIM3 free (PPS uses TIM2).
    Buzzer footprint is the CUI CMT-8504 placeholder -- verify vs MLT-8530 at layout.
    - 2nd USB-C: J5 GCT USB4085 (C7095263), vertical, same 16-pin USB2.0 family,
    same bus as J3 (parallel VBUS/D+/D-/GND) with its own CC pulldowns R15/R16.
    - Antenna: populate Cm2 = 1.8pF shunt (W3011A datasheet reference value; the -A's
    rated -16dB is measured with shunt 1.8pF), Cm3 DNP; VNA-t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
    [ephemerkey.kicad_pcb, ephemerkey.kicad_sch, gnss.kicad_sch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]
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2026-07-01 ephemerkey: 2nd USB-C -> vertical GT-USB-7051A (C2843970), KiCad footprint
    USB4085 was horizontal (GCT drawing: 'Dip Type, PCB Top Mount' -- cable inserts
    parallel to the board), not the upright connector needed. Swap J5 to the
    G-Switch GT-USB-7051A (C2843970): true vertical/upright SMT USB-C that sticks up
    off the board, 16-pin USB2.0, ~3.5k JLCPCB stock, with a bundled KiCad footprint
    (USB_C_Receptacle_G-Switch_GT-USB-7051x) + 3D model. Same symbol/bus as J3.
    [ephemerkey.kicad_pcb, ephemerkey.kicad_sch, gnss.kicad_sch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]
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2026-07-09 hardware: fix PSU load-share S/D, make all sheet notes monospace
    The PSU wiring note specified Q1 (AO3401A load-share PMOS) as S=BAT+,
    D=VSYS. A PMOS body diode conducts D->S, so that orientation points the
    diode VSYS -> BAT+: with USB attached VSYS sits ~4.7V (VBUS - D3) against
    a 3.0-4.2V cell, forward-biasing it and dumping uncontrolled current into
    the battery, bypassing the MCP73831 charger entirely.
    Correct assignment is D=BAT+, S=VSYS, so the body diode points BAT+ ->
    VSYS: the battery always reaches the load, and USB can never back-feed
    the cell. Q1 was placed but never wired (all three pins are unconnected
    in the netlist), so this is a spec fix ahead of wiring, not a board
    change.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
    [drv.kicad_sch, gnss.kicad_sch, mcu.kicad_sch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]
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2026-07-11 lock-attiny: authenticated I2C lock (HMAC-SHA1 challenge-response)
    TWI0 target @ 0x60 implementing the hardware/lock/README protocol, verified
    live on real hardware via a RedBoard serial<->I2C bridge:
    - Registers: STATUS (door/bolt/actuator/rail/busy/last-cmd-ok — the hall read),
    NONCE (fresh 16B, reading arms it), COMMAND (cmd ‖ HMAC-SHA1(secret, nonce‖cmd)).
    - Challenge-response: master reads NONCE, writes COMMAND; lock recomputes the
    HMAC, constant-time compares, burns the nonce (replay-proof), then actuates
    UNLOCK/LOCK via the servo or solenoid+boost drivers. Bad HMAC is rejected.
    - Anti-replay nonce = EEPROM monotonic counter (no TRNG); secret in USERROW with
    a DEV fallba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
    [actuate.c, hall.c, main.c]
2026-07-11 lock-attiny: programmable config + non-blocking actuator state machine
    Adds admin-programmable configuration over I2C and reworks actuation to never
    block the bus. Verified live on hardware (RedBoard bridge): config get/set,
    EEPROM persistence across reset, runtime actuator switch, and a servo+solenoid
    unlock cycle polled through all phases while I2C stayed responsive.
    - REG_CONFIG (0x20): authenticated with its OWN secret (config secret), reusing
    the nonce challenge. Write = blob(9) ‖ HMAC(config_secret, nonce ‖ blob);
    read returns the current blob. Two secrets now split across USERROW
    (pairing [0:16], config [16:32]), SECRET_LEN=16 each.
    - Bit-packed 9-byte config (config.c/.h),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
    [actuate.c, config.c, config.h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]
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2026-07-11 lock-attiny: servo_boost = 6 V (interlock-clear); fix VSERVO strap docs
    Per the intended use (6 V boosted servo), boost_servo_enable() now enables the
    boost with BOOST_VSEL LOW (6 V FB select) so the Q5 interlock stays clear and
    servo power remains enabled — VSOL rises to ~6 V and feeds the servo. 12 V is
    never used for servos (it interlocks servo power off). The servo-boost phase no
    longer asserts RAIL_12V (it's 6 V).
    Corrected the VSERVO strap references: the routed drv.kicad_sch has
    R13(fitted)->BAT+ (direct battery, default) and R14(DNP)->VSOL (6 V boost) —
    the opposite of the stale lock.schgen.py manifest note. So the default board
    runs the servo on direct battery and CFG_SERVO_BOO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
    [actuate.c, config.h, power.c]
2026-07-12 lock-attiny: remove firmware servo pulse clamp
    The servo pulse width was clamped to SERVO_MIN_US..SERVO_MAX_US in
    servo1_set_us/servo2_set_us. The config already bounds the lock/unlock
    positions, so the firmware clamp only prevented reaching the full range
    of a given servo. Drop it: US_TO_CMP() is applied directly and
    SERVO_MIN_US/SERVO_MAX_US are gone (SERVO_MID_US retained).
    [servo.c]
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2026-07-12 lock-attiny: programmable actuation step sequences
    Replace the fixed servos-then-solenoid actuation with two independent,
    programmable step sequences (one for UNLOCK, one for LOCK, up to 6 steps
    each). Each step fires any combination of {servo1, servo2, solenoid}
    together, with per-step servo target positions (so a servo can be driven
    either direction — e.g. unlatch, drive the solenoid, then drive a servo
    back the opposite way), a run time, and an optional hall early-off that
    ends the step and advances to the next.
    Per-step rail selection (the boost makes VSOL, which also feeds the servo):
    - solenoid + servo in one step -> 6 V, solenoid FULL DC (no economizer
    PWM), servo powered: the on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
    [actuate.c, config.c, config.h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]
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2026-07-12 lock-attiny: ABORT command + actuation-engine hardening audit
    Adds an authenticated emergency stop and fixes four defects found in a
    critical audit of the step engine, command path, and buffer sizes,
    prompted by a one-time field wedge (servo left powered, cycle stuck).
    ABORT (CMD 0x03): same nonce+HMAC framing as UNLOCK/LOCK; tears every
    actuator and rail down immediately (verified live: BUSY+12V rail to
    safe/idle in <0.5 s mid-solenoid-hold).
    Rail safety (per review):
    - Rail-hot tracking + pre-drain: whenever the boost has been enabled the
    rail is flagged hot until a completed drain window. actuate_begin on a
    hot rail (i.e. after an abort mid-boost) inserts a 2 s passive bleed
    befor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
    [actuate.c, main.c, solenoid.c]
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2026-07-12 lock-attiny: deglitch early-off — arm on opposite state + integrator
    The per-step early-off fired falsely on the bench: STATUS showed the door
    hall reading a SUSTAINED false-absent for the entire actuation (both the
    6V servo and 12V solenoid phases; present again the instant the cycle
    ends), so the old 500 ms time-window cut a 10 s solenoid hold ~1 s in
    with the magnet present. Actuation disturbs the sensor supply/read path
    (same transient family as the I2C bus errors; dev-board wiring).
    Replace the time-window with two deglitching layers, both failing toward
    "keep driving":
    - ARM: the step must first see the sensor in the OPPOSITE state for 5
    consecutive 10 ms samples (eoff=door- requ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
    [actuate.c, config.h]
2026-07-12 lock-attiny: STATUS bit2 -> live SERVO_ON, add bit6 SOL_ON
    STATUS bit2 was the pre-sequence "configured actuator type" flag
    (1=servo), set once at boot/config-write - meaningless now that one
    sequence can drive both actuators, and actively misleading in traces
    ("ACTUATOR=servo" while the 12 V solenoid holds).
    Replace it with live actuator telemetry, set/cleared exactly where the
    outputs are switched in the step engine:
    bit2 SERVO_ON - a servo is currently powered
    bit6 SOL_ON - the solenoid coil is energized (stays set through the
    drain, where the coil conducts VSOL down - honest)
    RAIL_12V (bit3) is unchanged as the rail indicator. Drop
    status_reflect_config()/cfg_any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
    [actuate.c, config.c, config.h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]
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2026-07-13 hardware: add optional ESP32-C3 WiFi + audit-log EEPROM (wifi/storage sheets)
    Two new generated sheets (existing sheets untouched, no force-regen):
    WiFi (wifi.kicad_sch, optional — depopulate to omit):
    - ESP32-C3-MINI-1-N4 (C2838502) on its own AP2112K-3.3 rail from VSYS, so
    350mA TX bursts never load the TPS63900 (400mA) or the GNSS VCC_RF rail
    - 3 MCU pins total: PB5 = LDO EN (power cycle = reset; 100k default-off),
    PA2 = LPUART1_TX doubling as the IO9 boot strap, PA3 = LPUART1_RX
    (wake-from-Stop); accel INTs move PA2/PA3 -> PB3/PA8, zero spares remain
    - USB-CDC bridge flashing plan (stock esptool.py through the STM32) and
    DNP 0R links to BOOT0/NRST for ESP-driven ROM recovery o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
    [ephemerkey.kicad_sch, storage.kicad_sch, wifi.kicad_sch]
2026-07-13 firmware: Rust/Embassy scaffold for STM32U083 + unlock-policy design doc
    New firmware/ephemerkey-rs crate (embassy-stm32 0.6, stm32u083kc,
    thumbv6m-none-eabi, defmt/probe-rs). Compiles clean; release image 20.4KB.
    - One image, two personalities (config::Role): Generator (GNSS->TOTP) or
    LockController (code-slot policy engine -> lock board), both provisioned
    by signed files over USB or WiFi (provision.rs sketch).
    - All DESIGN.md pin-budget bindings wired and type-checked against the
    U083 AF table: USART1 GNSS (DMA RX), LPUART1 ESP32-C3 + PB5 rail gate,
    I2C1 sensors + LIS3DH EXTI3/8, TIM3_CH1 buzzer, LEDs, buttons.
    - FINDING: PB0/PB1 (LOCK_SDA/SCL) have no I2C alternate function on th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
    [buzzer.rs, gnss.rs, lock.rs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]
2026-07-13 hardware+fw: swap lock I2C <-> LEDs (PA6/PA7 <-> PB0/PB1) for hardware I2C3
    PB0/PB1 carry no I2C alternate function on the STM32U083 (caught by the
    Rust firmware's compile-time AF check), so the lock link could only ever
    have been bit-banged there. PA6/PA7 are I2C3 SDA/SCL at AF4 and were
    merely driving LEDs, which are function-agnostic. Swap:
    PA6 = LOCK_SDA (I2C3_SDA) PB0 = LED green
    PA7 = LOCK_SCL (I2C3_SCL) PB1 = LED red
    - schgen manifest: MCU pinout note rows 12-15 swapped; J2 note gains the
    swap rationale and a neutral 3V3-pull-up justification (verify PA6/PA7
    V_tol before ever considering VSYS pull-ups).
    - mcu.kicad_sch: surgical on-canvas note replacement (regen woul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
    [mcu.kicad_sch]
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2026-07-13 firmware: ephemerkey-core (shared policy/TOTP/reveal) + ekemu local emulator
    New no_std crate ephemerkey-core, consumed by BOTH the STM32 firmware and
    a host emulator so lock/generator behavior can never diverge:
    - totp: RFC 4226/6238 HOTP/TOTP (RustCrypto hmac/sha1), 4-10 digit codes
    with significant leading zeros; RFC test vectors pass.
    - policy: the slot model moved out of ephemerkey-rs (Sequence with walk
    delay + generation cadence, gates, NegativeAction).
    - engine: LockEngine - per-slot delay-window counter search, replay burn
    watermark, decoy twins as NEGATIVE matches with reset/lockout/silent
    severities, invalid->reset dispatch. 6 scenario unit tests (delay
    window, hoard-an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
    [lib.rs, main.rs]
2026-07-13 core: implement Path, DeadMan, and Quorum policy machines
    Fills the stubbed policies with emulator-proven implementations:
    - Path (walk-the-path): per-leg zone keys (leg_keys[MAX_PATH_LEGS]);
    engine offers only the CURRENT leg's key, so order is structural;
    pace is generation-time (counter gap <= leg_deadline_s); all codes
    enter at the destination within delay_max_s. Wrong order = no match.
    - DeadMan: first code fires, fresh codes every <= beat_s sustain (BEAT),
    expiry emits a RELOCK event. Events queue in the engine
    (take_relocks bitmask) so no expiry is ever lost between polls.
    - Quorum: M of N distinct keys within window_s, each key counts once,
    optional strict alternation (s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
    [main.rs]
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2026-07-19 ephemerkey-core: wire slot gates (position/stillness/calendar) into the engine
    The Gates struct was declared but inert -- a portable-lock slot that must be
    inside a geofence would fire anywhere. Make evals actually gate:
    - policy.rs: add a caller-owned `Sensors` trait (inside_fence / still_for_s /
    calendar_open), a `GateBlock` reason enum, `AllGatesOpen`, and
    `Gates::block(env)` evaluated fence -> stillness -> calendar for a stable
    reported reason.
    - engine.rs: new `enter_code_with(entered, now, &impl Sensors)`; `enter_code`
    delegates with AllGatesOpen so every existing caller/test is unchanged. A
    correct-but-gated code returns `Outcome::Gated(slot, reason)` WITHOUT
    burning the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
    [main.rs]
2026-07-19 ephemerkey-core: confirm-TOTP receipts -- HOTP (sequence) AND TOTP (time)
    The lock talks back: on every fire and relock it mints its own code from a
    per-lock confirm secret so a remote party can verify the event happened. Time
    and sequence answer different questions, so make them independently selectable
    (and combinable), per the user's ask:
    - new receipt.rs: `ReceiptMode { Sequence, Time, Both }`.
    - Sequence = HOTP over a monotonic event counter -> order/skip/replay proof;
    validator tracks the expected counter (RFC 4226 s7.4 resync + look-ahead).
    - Time = TOTP over the event time -> "it happened at HH:MM"; validator
    searches a drift window and reports the offset.
    - Both = emi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
    [lib.rs, main.rs]
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2026-07-19 ephemerkey-envelope: pin the config/telemetry wire format (ekenv-v1)
    COSE-profile envelope shared by firmware, emulator, and ekctl-server:
    - COSE_Sign1 (Ed25519) and COSE_Encrypt0 (X25519 + HKDF-SHA256 +
    AES-128-GCM) with seq/target in the AEAD-authenticated protected
    header so untrusted relays can order and route without decrypting
    - config-ack and telemetry event-batch payload schemas
    - no_std, no-alloc, dependency-free hand-rolled CBOR; randomness is
    caller-supplied (TRNG on device, OS on hosts, fixed in tests)
    Cross-implementation coverage lives in ephemerkey-control's smoke suite
    (independent JS device simulator -> this crate's verifiers).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
    [lib.rs]
2026-07-19 ephemerkey-frame + ekemu serial: framed provisioning link, emulated device
    - ephemerkey-frame: no_std serial framing (EK magic, len u16le,
    CRC-16/CCITT-FALSE, incremental noise-tolerant parser) shared by the
    emulator now and provision.rs later
    - ekemu serial <state.json> [addr]: emulate a device in provisioning
    mode over TCP with the real crypto — self-signed IDENTITY enrollment
    doc, "ek-identify-v1" challenge signatures, sealed-config transfer
    with envelope open + owner TOFU (inner Sign1 kid = owner_pub; first
    writer wins, wrong owner -> ERROR wrong-set, replay -> seq-rollback),
    signed config-acks and event batches, WiFi set/status frames;
    identity/config persist in the st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
    [lib.rs, main.rs]
2026-07-19 ephemerkey-provision: portable provisioning engine; wire into provision.rs
    - new no_std/no-alloc crate: the full framed provisioning protocol
    (identity doc, identify-challenge signatures, chunked sealed-config
    transfer with envelope open + owner TOFU via inner Sign1 kid,
    seq-rollback/wrong-set rejection, signed config-acks, event-ring
    batches, wifi set/status) behind a platform Store trait; all buffers
    in-struct (~14 KiB, static-alloc on MCU); host-tested (3 tests
    covering the same flows ekemu serial + the ekctl e2e exercise);
    builds for thumbv6m-none-eabi
    - ephemerkey-rs/src/provision.rs: replace the superseded TLV+HMAC
    sketch with the engine + FlashStore scaffold (journal,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
    [lib.rs]
2026-07-19 policy: paced quorum + randomized sequence pacing (jitter)
    - Quorum gains gap_min_s/gap_max_s: contributions must keep the same
    generation cadence Sequence enforces (0..=65535 = unpaced). A paced
    quorum proves the parties acted in a shared rhythm — one courier
    bursting a stack of pre-minted codes resets the round.
    - Sequence gains pace_jitter_s: 0 = classic fixed [gap_min, gap_max];
    >0 = after each accepted code the device draws the next step's
    effective accept window by tightening both bounds by up to jitter
    (xorshift seeded per round from first counter+arrival; clamped so the
    window never empties). Entries outside the drawn window reset — the
    reject/accept ranges are de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
    [main.rs]
2026-07-19 crit features: configs name required protections; consumers must reject
    - ephemerkey-core: SUPPORTED_POLICY_FEATURES registry (seq-jitter,
    quorum-pace); a config's crit list names features it depends on for
    its security promises — unknown crit entry = reject, never silently
    skip a protection (X.509-critical / COSE-crit pattern)
    - ephemerkey-frame: err_code::UNSUPPORTED = 7
    - ekemu: scenario loader refuses unknown crit; `ekemu serial` enforces
    crit on sealed configs before commit (ERROR 7)
    - ephemerkey-provision: Store::validate_config hook called between
    verification and commit (rejection test incl. no-commit assertion)
    - ephemerkey-envelope schema: enrollment_decode for the IDEN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
    [lib.rs, main.rs]
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2026-07-19 ekemu: clarify the INVALID-code outcome message
    "armed slots reset" was ambiguous now that Armed is a veto state — a code
    matching no ritual wipes every reset_on_invalid ritual. Dispatch/reset
    semantics are specified in DESIGN-policies.md (a code goes to the first
    matching ritual by key; only a no-match is "invalid").
    [main.rs]
2026-07-19 firmware: persistent flash store, TRNG identity, USB provisioning, board features
    Ungate hardware provisioning on the STM32U0. Previously the provisioning
    engine was reachable only from tests/emulator: the store was in-RAM (owner
    binding lost on power-down) and the device identity was a [0;32] placeholder.
    - ephemerkey-store: portable no_std flash journal behind a Flash trait
    (2048B page / 8B word). Identity page + 2-slot ping-pong config record
    with atomic commit + CRC — a torn write can lose the new config but never
    the owner binding, as Store::commit requires. 7 host tests over a RAM
    fake-flash that enforces the U0 no-reprogram-before-erase rule.
    - ephemerkey-rs: EmbassyFlash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
    [lib.rs, main.rs]
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2026-07-19 envelope: pluggable AES-GCM backend (software default)
    Introduce an AesGcm128 trait so the envelope's A128GCM primitive can be
    swapped without touching the wire format (GCM output is identical). SoftAesGcm
    (RustCrypto aes-gcm) is the default used by the host, emulator, server, and
    tests unchanged; seal_write/open keep their signatures as thin wrappers, with
    seal_write_with/open_with taking an explicit backend. Provisioner is now
    Provisioner<S, A = SoftAesGcm> with new_with_aes() for injecting a backend;
    new() is unchanged.
    This is the injection point for using the STM32U0's hardware AES engine to
    open sealed configs on-device. It is NOT wired yet: embassy-stm32 0.6 ships an
    AES driver only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
    [lib.rs]
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
